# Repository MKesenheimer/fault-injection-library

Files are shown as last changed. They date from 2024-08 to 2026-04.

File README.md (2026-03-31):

# Usage with examples

Findus (aka the fault-injection-library) is a toolchain to perform fault-injection attacks on microcontrollers and other targets.
This library offers an easy entry point to carry out fault-injection attacks against microcontrollers, SoCs and MCUs.
With the provided and easy to use functions and classes, fault-injection projects can be realized quickly with cheap and available hardware.

Findus supports the [ChipWhisperer Pro](https://rtfm.newae.com/Capture/ChipWhisperer-Pro/), the [ChipWhisperer Husky](https://rtfm.newae.com/Capture/ChipWhisperer-Husky/) and the [Pico Glitcher](https://mkesenheimer.github.io/blog/pico-glitcher-v3.html).

More information about the fault-injection-library and the Pico Glitcher can be found on [https://fault-injection-library.readthedocs.io/en/latest/](https://fault-injection-library.readthedocs.io/en/latest/).

## Table of contents

- [Purchasing the Pico Glitcher](#purchasing-the-pico-glitcher)
- [Documentation](#documentation)
- [Installing findus](#installing-findus)
- [Updating the Pico Glitcher firmware](#updating-the-pico-glitcher-firmware)
    - [Step 1: MicroPython firmware](#step-1-microPython-firmware)
    - [Step 2: Install the findus library](#step-2-install-the-findus-library)
    - [Step 3: Update the firmware of your Pico Glitcher](#step-3-upload-the-pico-glitcher-micropython-script)
- [Installing from source](#installing-from-source)
- [Test the functionality of your Pico Glitcher](#test-the-functionality-of-your-pico-glitcher)
- [UART Trigger](#uart-trigger)
- [More Examples](#more-examples)
- [Analyzer](#analyzer)

## Purchasing the Pico Glitcher

Only a Raspberry Pi Pico and a few other components are required to use this software.
However, in order to achieve the best results, a circuit board was developed that was adapted directly for the fault-injection-library.

The board consists of a Raspberry Pi Pico, two level shifters for in- and outputs with any voltage, and glitching transistors that can switch up to 66 amps.
A multiplexing stage to quickly switch between up to four different voltage levels was added in revision 2.

There are several connection options for different voltage sources, from 1.8V, 3.3V to 5V.
The Pico Glitcher can also be supplied with any external voltage via `VCC_EXTERN`.
To power the target board, it is supplied with power via the `VTARGET` connection.
The output of this voltage source can be controlled via software, i.e. the target can be completely disconnected from power by executing the `power_cycle_target()` command.
This allows a cold start of the target to be carried out in the event of error states that cannot be eliminated by a reset.

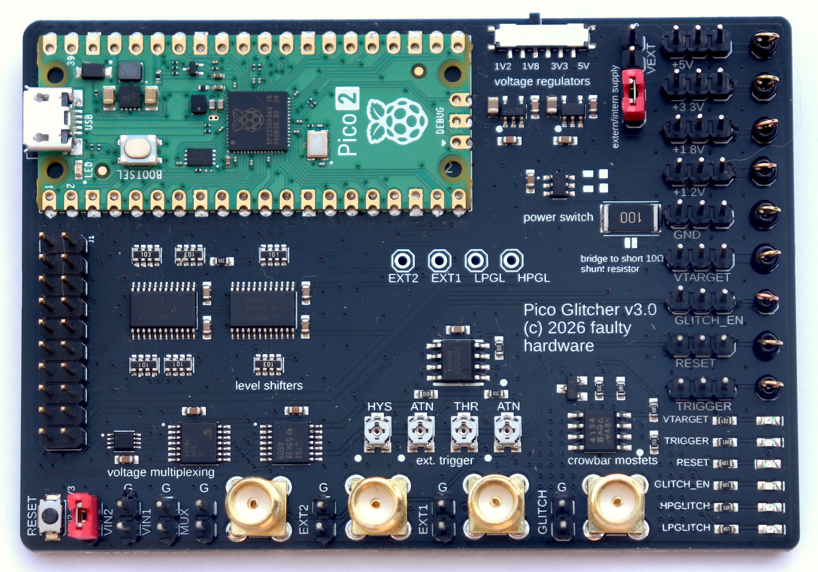
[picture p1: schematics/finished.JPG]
Assembled Pico Glitcher v1


The Pico Glitcher can be purchased from the [faultyhardware](https://faultyhardware.de) online store. If you have questions or special requests, please feel free to contact me.

## Documentation

The documentation of the source code and how to use the library and the hardware can be found on [https://fault-injection-library.readthedocs.io/](https://fault-injection-library.readthedocs.io/).

## Installing findus

If you just want to get started quickly and don't want to bother with the source code of findus, findus can be installed via pip. The findus library can be found on [https://pypi.org/project/findus/](https://pypi.org/project/findus/) and can be installed locally in a Python environment using the following command:

```bash
mkdir my-fi-project && cd my-fi-project
python -m venv .venv
source .venv/bin/activate
pip install findus
```

Install the optional RD6006 python bindings if you have a RK6006 or a RD6006 power supply from Riden:

```bash
pip install rd6006
```

This external power supply can be used optionally to supply the target with power. It is possible to control the RD6006 power supply via the findus library using the power supply's USB interface. Suitable functions for this are implemented in the findus library.
Don't worry if you don't have this power supply. The Pico Glitcher can also supply the target with voltage.

Now you can use findus:

```bash
python
>>> from findus import Database, PicoGlitcher
...
```

The next step is to copy an existing glitching script and to adapt it to your needs.
Start by copying [https://github.com/MKesenheimer/fault-injection-library/blob/master/example/pico-glitcher.py](https://github.com/MKesenheimer/fault-injection-library/blob/master/example/pico-glitcher.py). More example projects are located at [https://github.com/MKesenheimer/fault-injection-library/tree/master/projects](https://github.com/MKesenheimer/fault-injection-library/tree/master/projects).

See [examples](examples.md) for more information how to use findus and the Pico Glitcher.

## Updating the Pico Glitcher firmware

Your Pico Glitcher should come with the latest firmware already installed. If not, follow the following procedure to update the software on the Pico Glitcher.

### Step 1: MicroPython firmware

Download the MicroPython firmware from [https://micropython.org/download/RPI_PICO/](https://micropython.org/download/RPI_PICO/). Unplug the Pico Glitcher from your computer, press and hold the 'BOOTSEL' button on the Raspberry Pi Pico and connect it back to your computer. The Raspberry Pi Pico should come up as a flash-storage device. Copy the MicroPython firmware ('RPI_PICO-xxxxxxxx-vx.xx.x.uf2') to this drive and wait until the Raspberry Pi Pico disconnects automatically.
More information about setting up the Raspberry Pi Pico can be found [here](https://projects.raspberrypi.org/en/projects/getting-started-with-the-pico).

### Step 2: Install the findus library

Skip this step, if you already installed findus previously.

If you want to make sure that the libraries to be installed do not collide with your local Python environment, use a virtual environment.
Set it up by generating a new virtual environment and by activating it:

```bash
python -m venv .venv
source .venv/bin/activate
```

After these steps we have to install findus (aka fault-injection-library).
Make sure to have pip [installed](https://docs.python.org/3/library/ensurepip.html).

```bash
pip install findus
```

### Step 3: Update the firmware of your Pico Glitcher

If everything went well, you should have the `update-fw` script available for execution in your command-line environment.
Connect the Pico Glitcher to your computer and check which serial device comes up:

```bash
ls /dev/tty*
```

Take note of the device path. Next update the Pico Glitcher firmware and the specific configuration for your Pico Glitcher hardware version via the following command:

```bash
update-fw --port /dev/<rpi-tty-port> --version <pico-glitcher-version>
```

Your Pico Glitcher should now be ready to perform fault-injection attacks.

## Installing from source

If you want to get involved in the development or to have access to all the resources of this repository, clone the findus library:

```bash
git clone --depth 1 --recurse-submodules \ 
    https://github.com/MKesenheimer/fault-injection-library.git
```

Install the findus and the optional rd6006 library:

```bash
cd fault-injection-library
pip install .
cd rd6006
pip install .
update-fw --port /dev/<rpi-tty-port> --version <pico-glitcher-version>
```

The next step is to copy an existing glitching script and to adapt it to your needs.
Start by copying `fault-injection-library/example/pico-glitcher.py`. More example projects are located at `fault-injection-library/projects`.

## Test the functionality of your Pico Glitcher

The following  setup can be used to test the Pico Glitcher.

- Connect 'TRIGGER' input with 'RESET'.
- Between 'GLITCH' and 'VTARGET', connect a 10 Ohm resistor (this is the test target in this case).
- Optionally connect channel 1 of an oscilloscope to 'RESET' and channel 2 to 'GLITCH'.

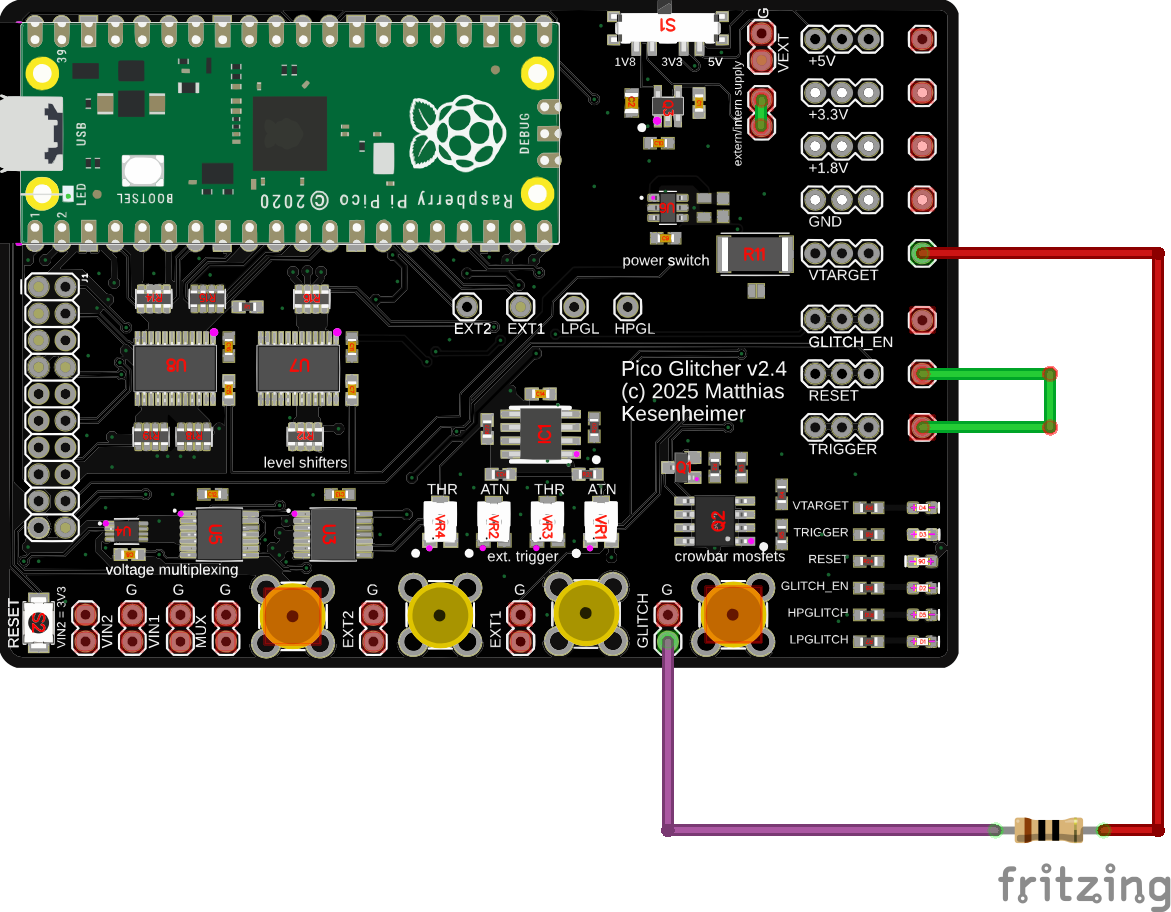
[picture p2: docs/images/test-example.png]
Example setup


Next, run the test script `pico-glitcher.py` located in `fault-injection-library/example`:

```bash
cd example
python pico-glitcher.py --rpico /dev/<rpi-tty-port> --delay 1000 1000 --length 100 100
```

You should now be able to observe the glitches with an oscilloscope on the 10 Ohm resistor.
Measure the expected delay and glitch length with the oscilloscope.

## UART Trigger

- Connect 'TRIGGER' input to 'RX' and 'TX' of a USB-to-UART adapter
- Between 'GLITCH' and 'VTARGET', connect a 10 Ohm resistor (this is the test target in this case).
- Optionally connect channel 1 of an oscilloscope to 'RESET' and channel 2 to 'GLITCH'.

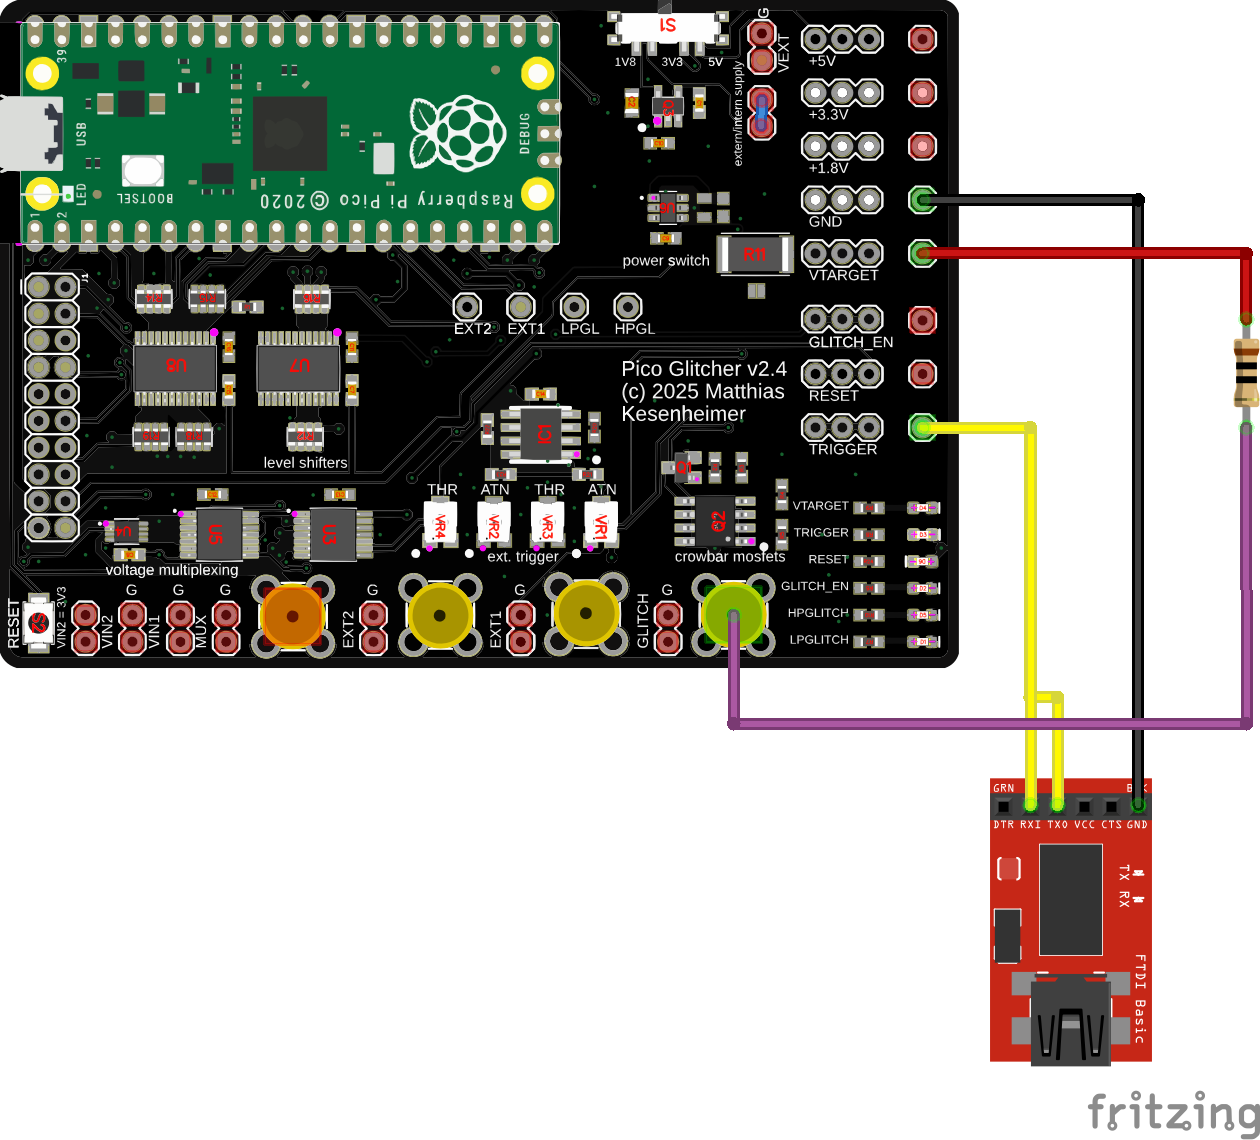
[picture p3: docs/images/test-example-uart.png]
Example setup


Next, run the test script `pico-glitcher-uart.py` located in `fault-injection-library/example`:

```bash
cd example
python pico-glitcher-uart.py --rpico /dev/<rpi-tty-port> --target /dev/<target-tty-port> --delay 1000 1000 --length 100 100
```

You should now be able to observe the glitches with an oscilloscope on the 10 Ohm resistor.
Measure the expected delay and glitch length with the oscilloscope.

## More Examples

More examples can be found on [https://fault-injection-library.readthedocs.io/en/latest/examples/#](https://fault-injection-library.readthedocs.io/en/latest/examples/#) or under `fault-injection-library/projects`.

## Analyzer

During your glitching campaign, run the `analyzer` script in a separate terminal window:

```bash
analyzer --directory databases
```

This spins up a local web application on [http://127.0.0.1:8080](http://127.0.0.1:8080) which can be used to observe the current progress.

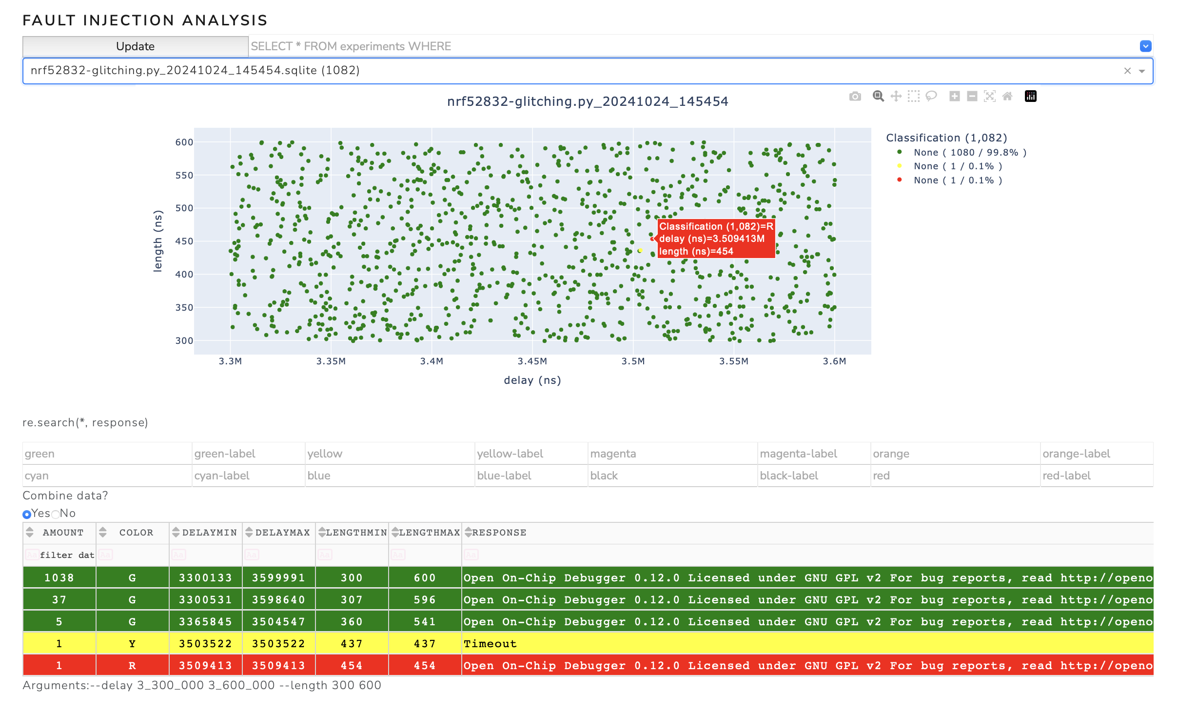
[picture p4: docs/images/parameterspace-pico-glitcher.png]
Parameter space web application


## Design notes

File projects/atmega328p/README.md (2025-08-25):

# Attacking the ATMEGA328P

## Prerequisites

- avrdude
- gcc-avr
- avr-gdb
- binutils-avr
- avr-libc

The installation on macOS is given below.
Installation on other platforms should be similar.

### Commands to install avr-gcc on macOS

```bash
brew tap osx-cross/avr
brew install avr-gcc avr-gdb avr-binutils
```

## Setup

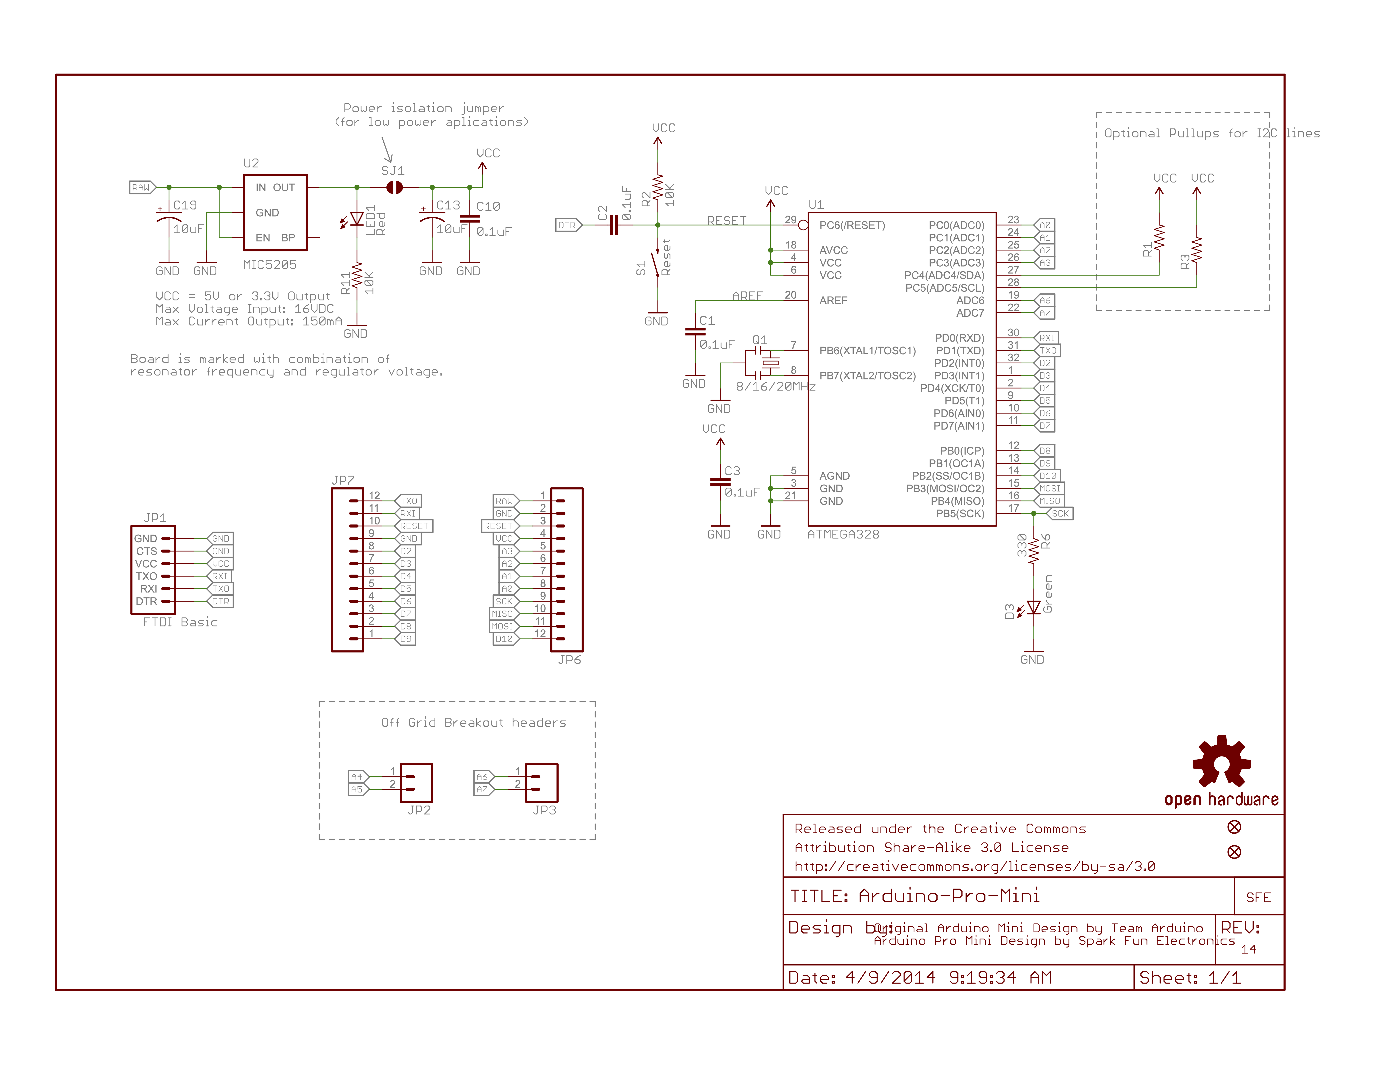
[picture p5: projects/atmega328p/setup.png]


### Wiring

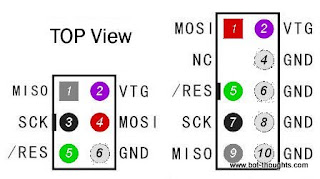
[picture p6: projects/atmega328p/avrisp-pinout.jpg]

Wire JTAGICE3 ISP pins to the ATmega328P:

```
MISO → MISO (PB4)
MOSI → MOSI (PB3)
SCK → SCK (PB5)
RESET → RESET
VCC → VCC
GND → GND
```

## Programming and Reading

The following commands can be used to program the chip, set the lock bits and read from flash:

### Programming

Write program to flash:

```bash
avrdude -F -c jtag3isp -p m328p -U flash:w:blink.hex:i
```

Setting fuses:

* Low fuse (lfuse): 0xFF -> external crystal, no CKDIV8
* High fuse (hfuse): 0xDE -> SPIEN enabled, bootloader reset + 0.5 KB boot section, EESAVE not set
* Extended fuse (efuse): 0x05 -> sets brown-out detection at 2.7 V

```bash
avrdude -F -c jtag3isp -p m328p \
  -U lfuse:w:0xFF:m \
  -U hfuse:w:0xDE:m \
  -U efuse:w:0x05:m # or 0xFD on newer avrdude
```

### Enable readout protection

* 0xFF = unlocked (default)
* 0x00 = full lock (chip only erasable, not readable)
* 0xFC = no programming, no verify/read (strongest: code protected)

```bash
avrdude -F -c jtag3isp -p m328p -U lock:w:0x00:m
```

### Disable readout protection and erase flash

```bash
avrdude -F -c jtag3isp -p m328p -e
```

### Reading

Dump flash:
```bash
avrdude -F -c jtag3isp -p m328p -U flash:r:dump.hex:i
```

Read fuses:
```bash
avrdude -F -c jtag3isp -p m328p -U lfuse:r:lfuse.hex:h -U hfuse:r:hfuse.hex:h -U efuse:r:efuse.hex:h
```

Read lock bits:
```bash
avrdude -F -c jtag3isp -p m328p -U lock:r:lock.hex:h
```

Read lock bits to stdout:
```bash
avrdude -F -c jtag3isp -p m328p -U lock:r:-:h
```

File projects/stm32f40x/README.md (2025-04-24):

# Notes

Short notes for the attacks on the STM32F40x microcontroller series.

## Short Summary

- This script attacks the read memory command while the microcontroller is in bootloader mode 
- This attack is similar to the attacks on the [STM8](https://github.com/MKesenheimer/fault-injection-library/tree/master/projects/stm8s) microcontroller
- A glitch is sent immediately after the read memory command (0x11ee)
- If the glitch is successful, the microcontroller responds with an ACK
- To get the memory contents of the flash, the script sends the following commands to set the address to read from and the number of bytes to read from that address
- To get the full flash back, the glitch is executed several times and the address to read from is increased accordingly.

Note that this script is for research only and is not intended to run on a real target. For example, if the script detects an error (such as a PCROP bit set), the microcontroller will be reprogrammed and all content will be lost. Make sure you understand what this script does and modify it to suit your needs.

Look into the [image folder](images) for more details.

A detailed write-up can be found [here](https://mkesenheimer.github.io/blog/glitching-the-stm32f4.html).

## Schematics

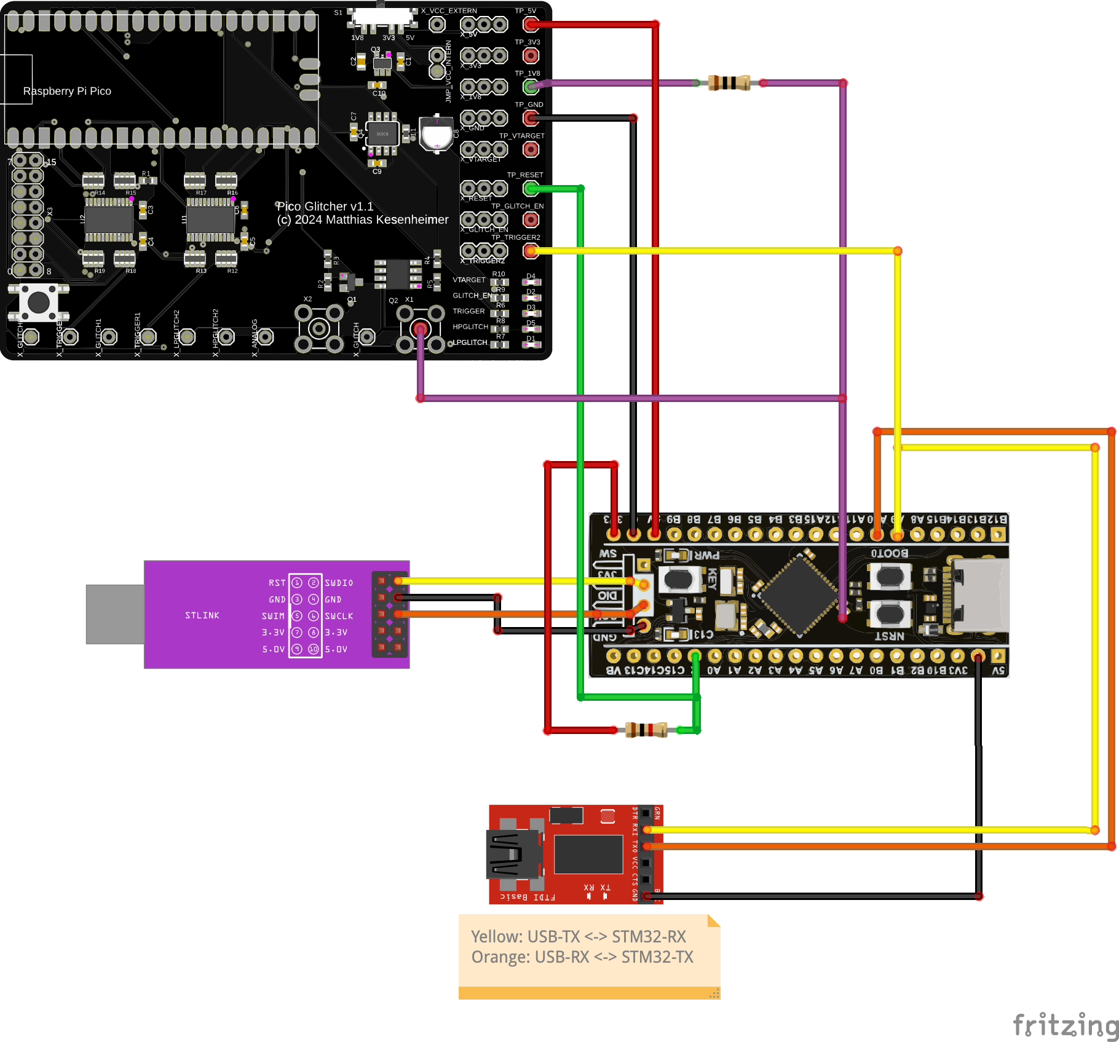
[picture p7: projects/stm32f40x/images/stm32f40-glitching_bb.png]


## Black Pill setup

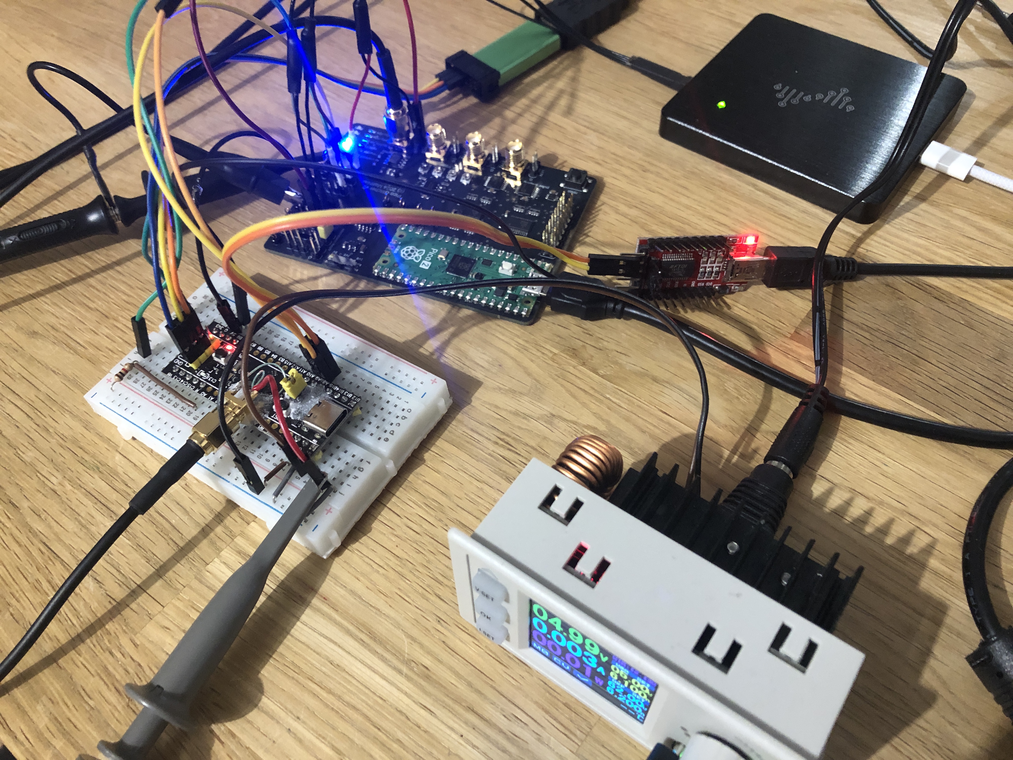
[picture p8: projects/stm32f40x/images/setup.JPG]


## Parameterspace

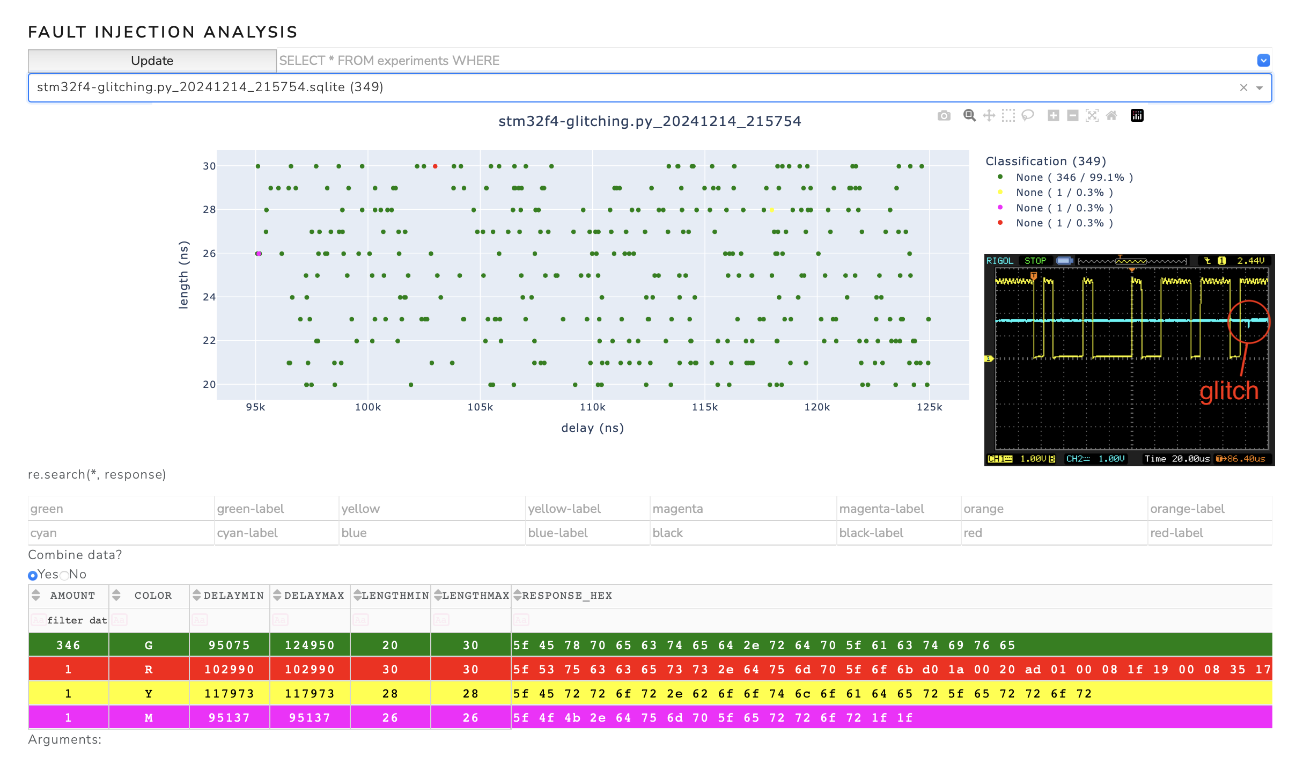
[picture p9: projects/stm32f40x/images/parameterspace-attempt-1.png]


## Successful dump

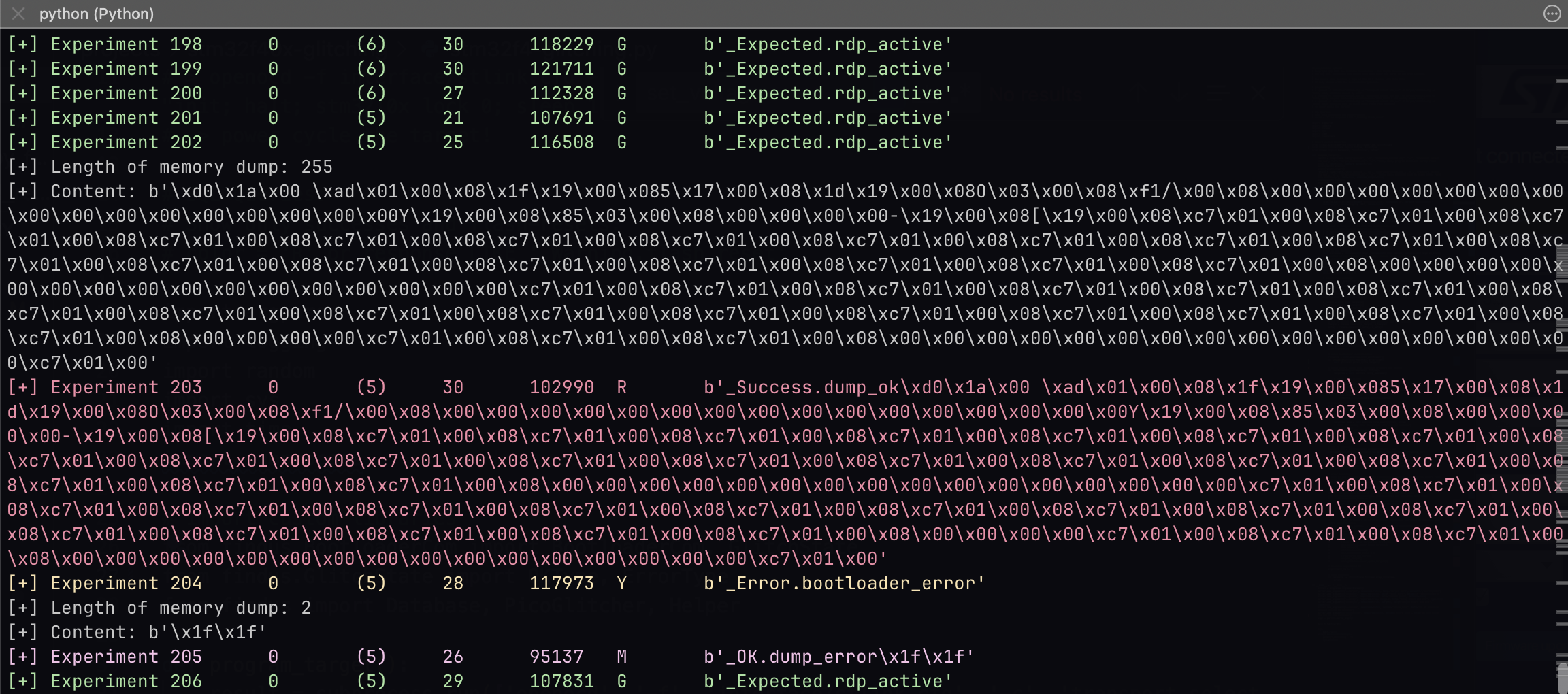
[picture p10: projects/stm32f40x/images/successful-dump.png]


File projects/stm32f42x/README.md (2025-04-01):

# Notes

## Short Summary
- Capacitors V_CAP_1 and V_CAP_2 have to be removed. Glitch is inserted on V_CAP line.
- Successful glitches and memory dumps in the following parameter range (ChipWhisperer Pro):
```bash
python pro-glitcher.py --target /dev/<target-tty-port> --delay 90_500 91_500 --length 230 240
```
- Flash gets erased occasionally while glitching -> target has to be reprogrammed.
- PCROP register gets set occasionally while glitching -> bootloader memory responses are masked with zeros.
- PCROP register must be unset if it is set during a glitching attempt.
- Bootloader code (address 0x1fff0000) can be dumped and reverse engineered.
- [AN2606 Application note STM32 microcontroller system memory boot mode](https://www.st.com/resource/en/application_note/an2606-stm32-microcontroller-system-memory-boot-mode-stmicroelectronics.pdf)

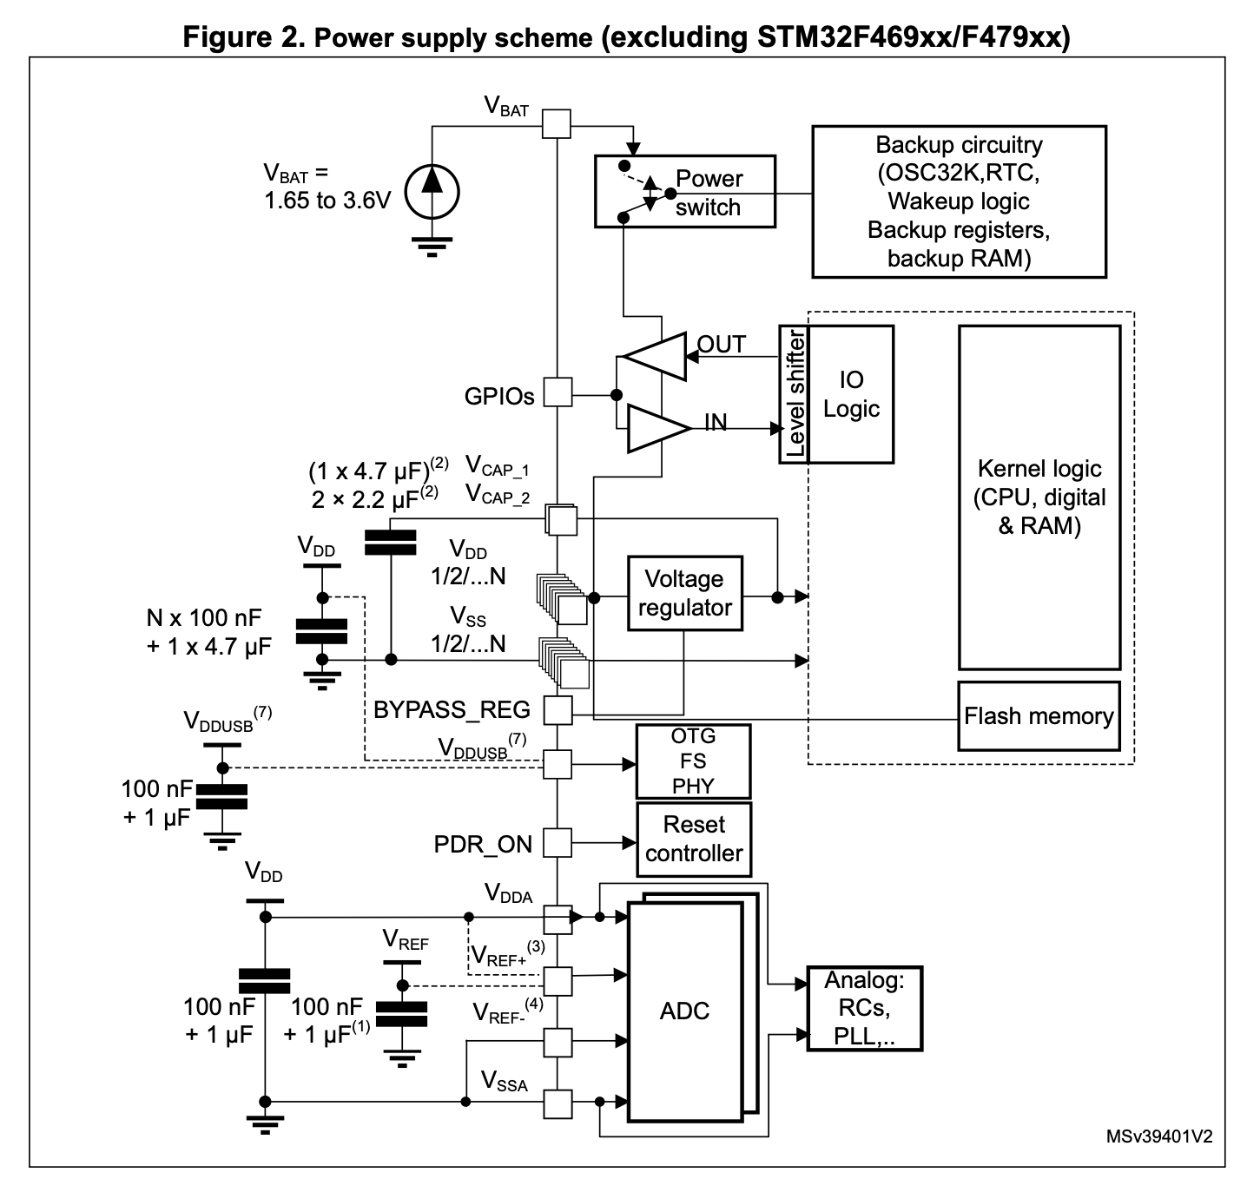
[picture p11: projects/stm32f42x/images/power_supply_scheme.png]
Glitch insertion point

[AN4488 Application note](https://www.st.com/resource/en/application_note/an4488-getting-started-with-stm32f4xxxx-mcu-hardware-development-stmicroelectronics.pdf)

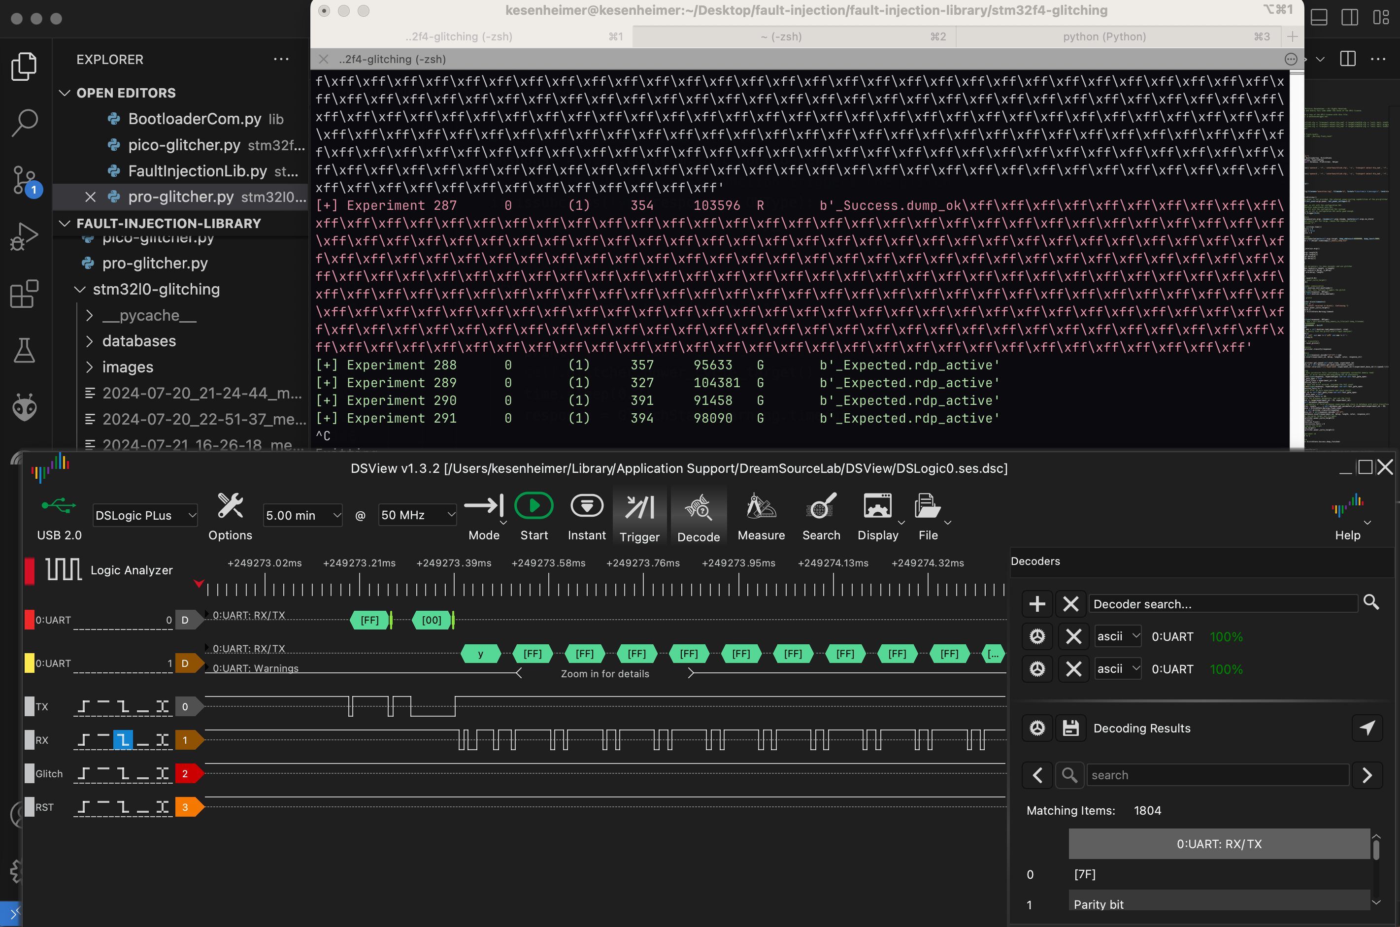
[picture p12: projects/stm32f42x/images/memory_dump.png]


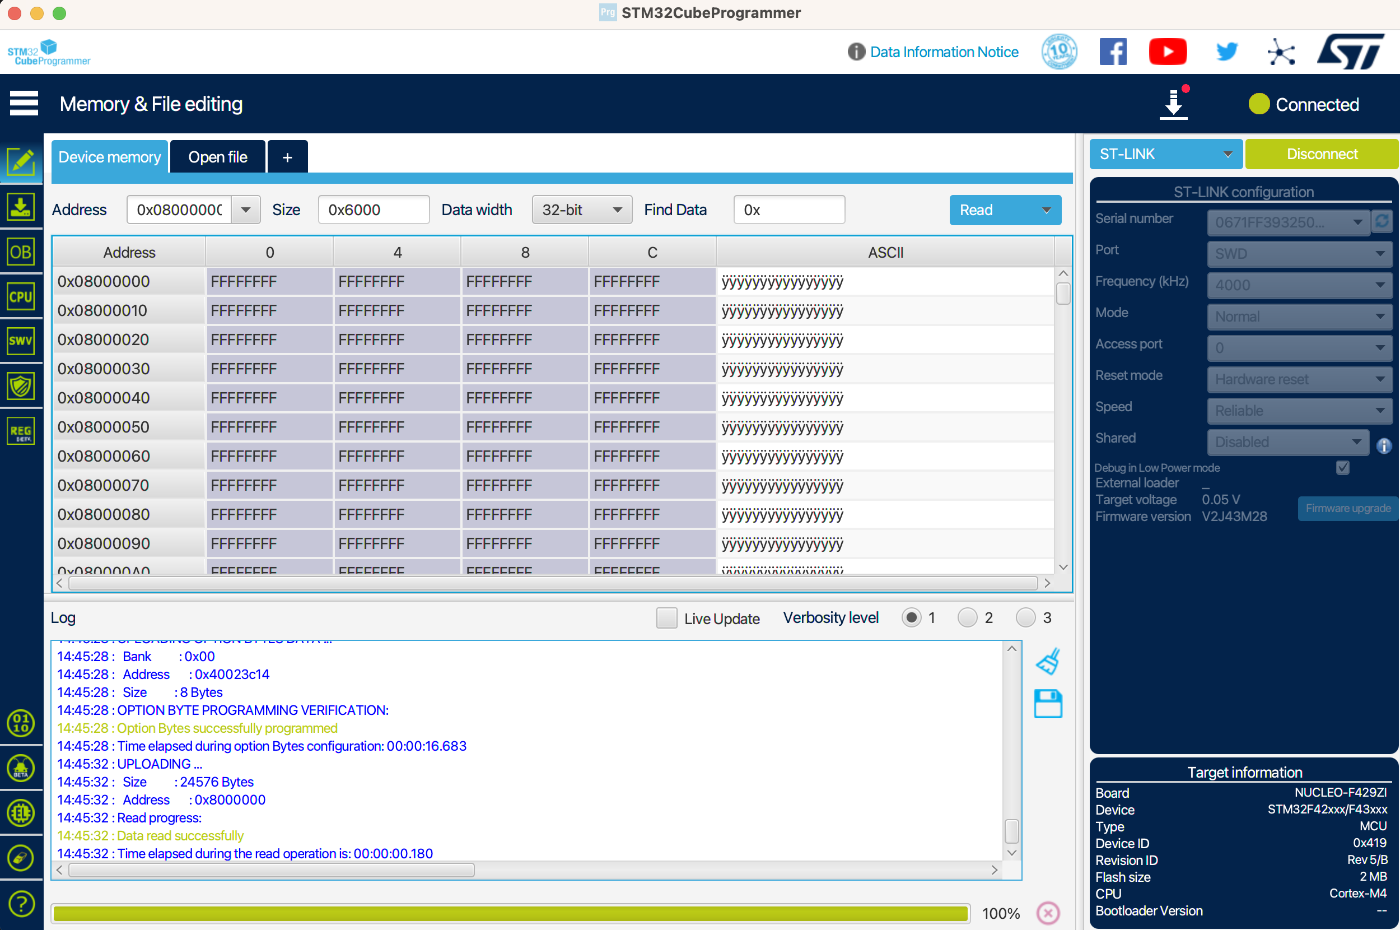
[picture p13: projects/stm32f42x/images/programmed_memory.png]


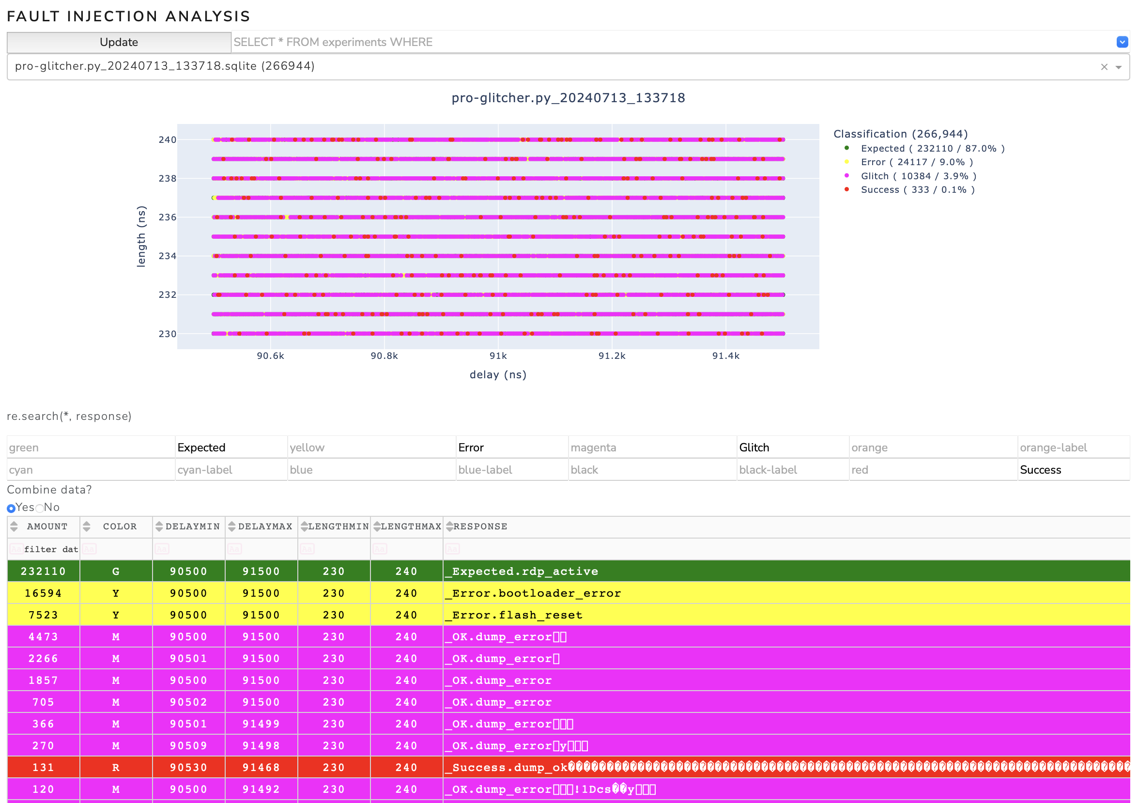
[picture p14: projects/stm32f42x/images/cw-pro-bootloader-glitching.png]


## TODO
- [ ] Screenshot of set PCROP register
- [ ] STM32F4 glitching with new development board (STM black pill STM32F401CCU6), see [STM32F401CCU6 glitching](https://jerinsunny.github.io/stm32_vglitch/)
- [ ] Screenshot of oscilloscope
- [ ] Dump and reverse engineering of Bootloader
- [ ] Document results

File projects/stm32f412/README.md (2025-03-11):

# Notes

## Short Summary

- Capacitors V_CAP_1 and V_CAP_2 have to be removed. Glitch is inserted on V_CAP line.

- Successful glitches and memory dumps in the following parameter range (PicoGlitcher):
  
  ```bash
  python pico-glitcher.py --rpico /dev/<PicoGlitcher-tty-port> --target /dev/<target-tty-port> --delay 103_000 105_000 --length 225 235
  ```

- Flash gets erased occasionally while glitching -> target has to be reprogrammed.

- Bootloader code (address 0x1fff0000) can be dumped and reverse engineered.

- [AN2606 Application note STM32 microcontroller system memory boot mode](https://www.st.com/resource/en/application_note/an2606-stm32-microcontroller-system-memory-boot-mode-stmicroelectronics.pdf)

Glitch insertion point
[AN4488 Application note](https://www.st.com/resource/en/application_note/an4488-getting-started-with-stm32f4xxxx-mcu-hardware-development-stmicroelectronics.pdf)

## Images

This is what it looks like if observering the Vcore (yellow, where we glitch) and the serial transmission (green) from the device. The bit pattern shown is that of 0x1f - NACK - we're not allowed to continue our Read Memory request due to RDP.

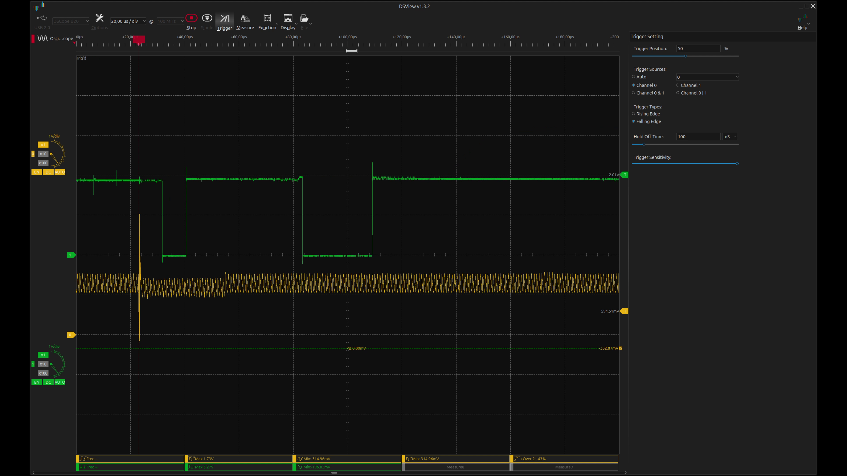
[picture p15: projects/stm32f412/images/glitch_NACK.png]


When the glitch is successful, we can see that the bit pattern now has changed to that of 0x79 - ACK - and we can continue sending the wanted memory address and length.

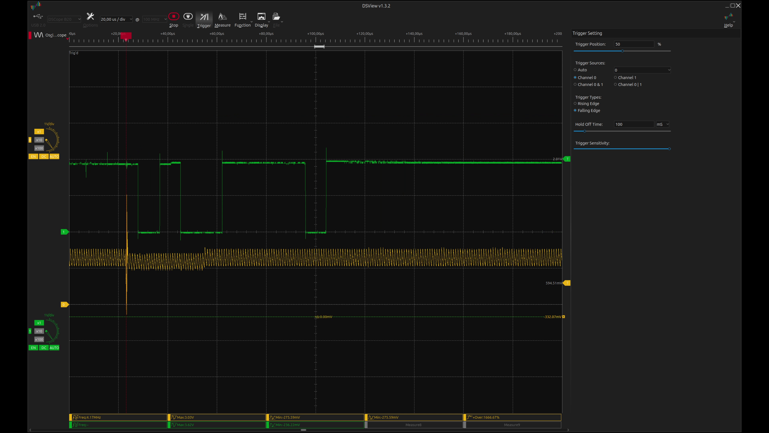
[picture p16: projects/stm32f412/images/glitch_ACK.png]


Closeups of the actual Vcore glitch. The amount of "ringing" (overshoot) after the glitch seems to correlate with what actions the glitch caused the device to take afterwards.

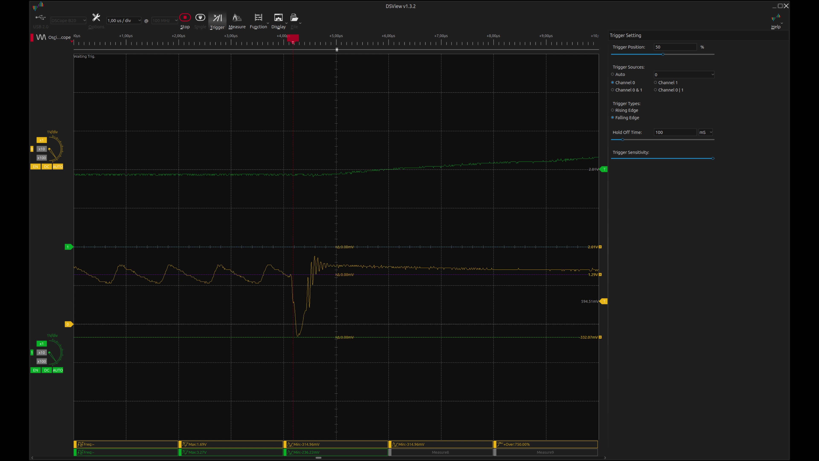
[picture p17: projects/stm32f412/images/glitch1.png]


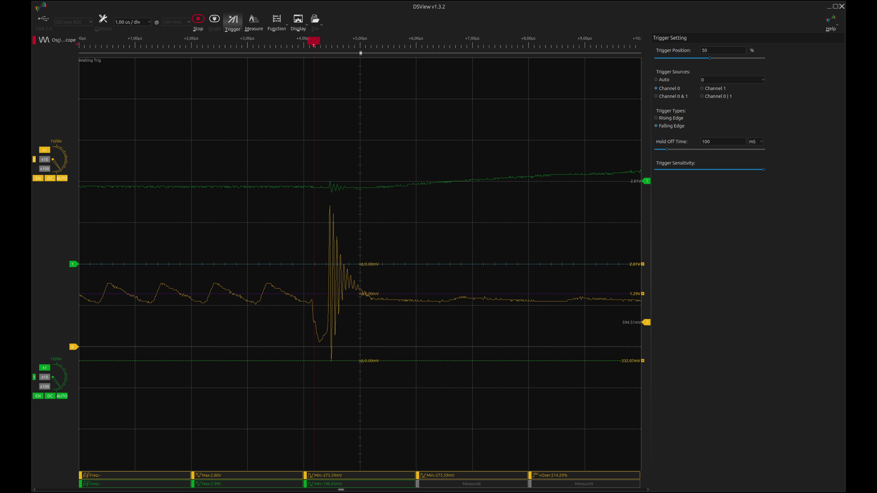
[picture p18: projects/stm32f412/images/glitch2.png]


## Example statistics

Reading out the bootloader (~24kB in size, v3.1) takes a few hours. As can be seen from the statistics, during that time we had 69 occasions (cyan) where the internal flash of the device was _possibly_ cleared. 96 successful glitched Read Memory requests (red) were needed, from a total of  ~15000 tries in total. Magenta indicates a successful glitch but where the device was no longer responding according to what Read Memory should (wrong execution path likely reached) and the various green rows indicate responses that were either expected (NACK) or anything else besides ACK.

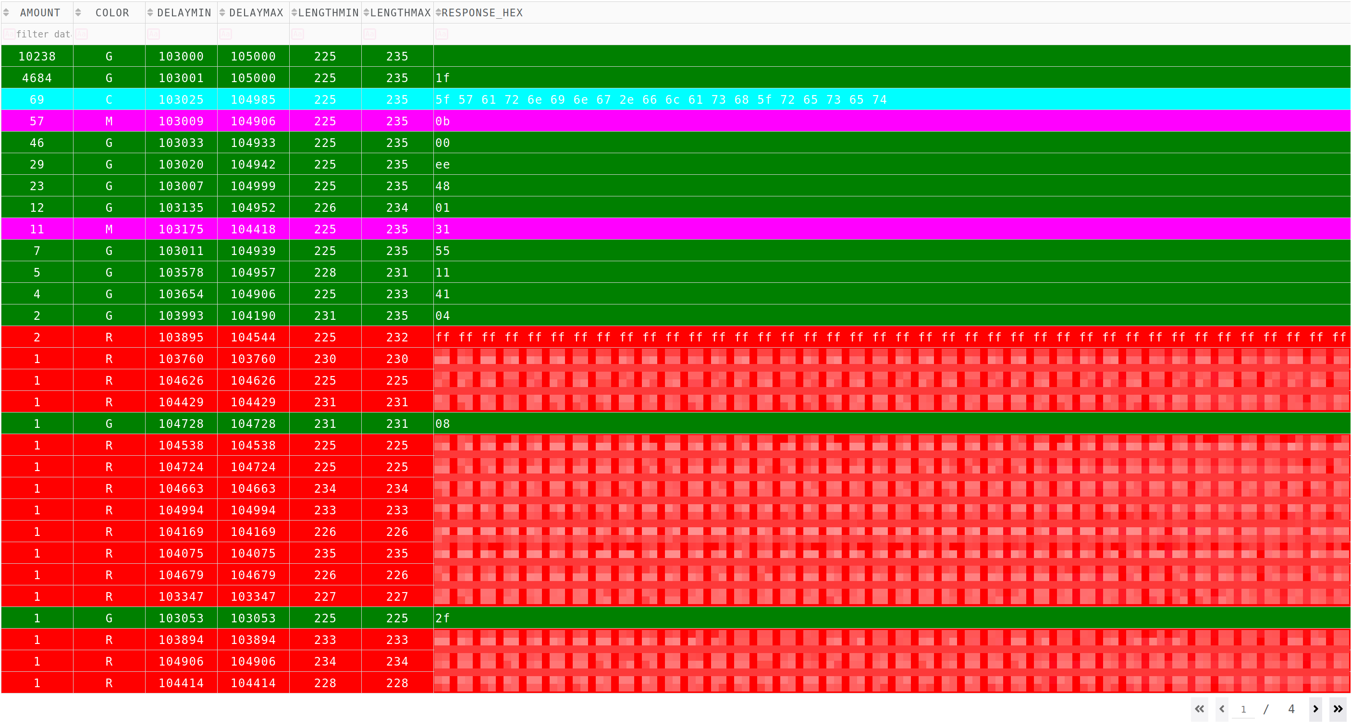
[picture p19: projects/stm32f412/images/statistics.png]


## Why this target is difficult to glitch

The current method for glitching STM32F4* relies on sending a Read Memory request to the STM bootloader via USART, picking up the sent byte on the serial line and then waiting a fix amount of nanoseconds before activating the glitch. However, due to the interaction between the serial clock and the CPU clock this method is wildly inexact. Looking at the red rows in the picture above we can clearly see that the delay at which we got successful glitches varies over 2000 ns. This also means that we're glitching all sorts of code paths during these tries, and some of those cause unintended and serious side effects.

The STM bootloader checks the received command byte with one long sequence of compares and jumps. Glitching during the time this code is run can cause execution to continue in another bootloader command method. We're also not currently able to "hook" onto some other indicator of where the bootloader is currently in it's execution, which would be needed for a much more exact exploit without the risk of clearing the internal flash memory.

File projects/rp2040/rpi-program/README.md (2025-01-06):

# Raspberry Pico Test Program

Set up raspberry pi pico projects according the official [documentation](https://projects.raspberrypi.org/en/projects/getting-started-with-the-pico).

Build and flash the project:
```
mkdir build && cd build
cmake -DCMAKE_BUILD_TYPE=Debug ..
make -j4
picotool load rpi-test.bin -f && picotool reboot
```

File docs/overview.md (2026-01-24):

# Overview

This page will give a brief overview of what findus (aka the fault-injection-library) and the PicoGlitcher is, what it can be used for and where to go from here.

## Fault-Injection

Fault injection is a group of attacks in which external influences are used to cause faults in a system and thereby influence the behavior of the system. In the simplest case, this can be an input mask on a web application that is not correctly secured against incorrect input. However, fault injection attacks usually also involve some kind of side-channel attack. This means that the fault is not caused by the usual channels (e.g. the input screen on the web application), but by a second channel. In the case of microcontrollers or embedded systems in general, the power supply or the clock generators on the board are used as a side channel to provoke error states.

## Voltage Glitching

In voltage glitching, the voltage supply to the chip is reduced for a very short time (in the order of nanoseconds to a few microseconds) to such an extent that processes in the chip no longer function correctly. Energy is required for certain operations in the chip. If this energy is not available, the operation is not carried out or is carried out incorrectly. Writing or erasing a memory cell, for example, cannot take place if there is not enough energy (i.e. in the simplest case, the supply voltage) available.

If the power supply is reduced at the time when a CPU register is written, no data or an incorrect value is written to the register. This can be particularly useful as an attack vector if the microcontroller has read-out protection. With read-out protection, the flash content is protected by checking if certain register values are set. These register values are not usually located in the firmware on the flash, but in a separate memory area, so-called fuses. If the microcontroller wants to check whether the read-out protection is set, these fuses must be read out and copied to an internal CPU register. If the power supply is lowered during this copying process so that the internal CPU register is written to incorrectly, the read-out protection can potentially be bypassed.

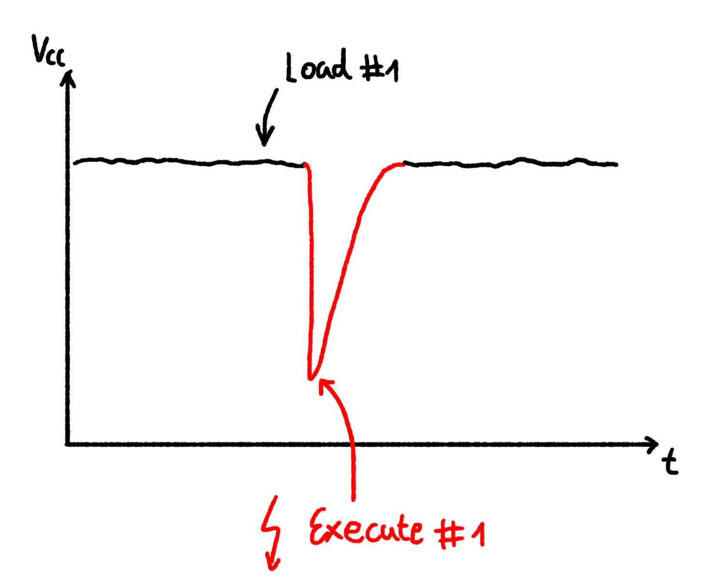
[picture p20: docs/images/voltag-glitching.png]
A reduction in the power supply causes an error during execution


The parameters for such attacks are the time delay from a trigger condition to the glitch itself ("delay") and the duration of the glitch ("length"). The trigger condition can be anything, for example switching on the power supply, removing the reset signal or certain states in the data transmission.

## What is findus?

Findus (aka the fault-injection-library) is a toolchain to perform fault-injection attacks on microcontrollers and other targets.
This library offers an easy entry point to carry out fault-injection attacks against microcontrollers, SoCs and CPUs.
With the provided and easy to use functions and classes, fault-injection projects can be realized quickly with cheap and available hardware.

Findus supports the [ChipWhisperer Pro](https://rtfm.newae.com/Capture/ChipWhisperer-Pro/), the [ChipWhisperer Husky](https://rtfm.newae.com/Capture/ChipWhisperer-Husky/) and the PicoGlitcher.
More information about the ChipWhisperer Pro and the ChipWhisperer Husky can be found on [https://chipwhisperer.readthedocs.io/en/latest/index.html](https://chipwhisperer.readthedocs.io/en/latest/index.html).

## What is the Pico Glitcher v1?

The Pico Glitcher is a device similar to the [ChipWhisperer Pro](https://rtfm.newae.com/Capture/ChipWhisperer-Pro/) and the [ChipWhisperer Husky](https://rtfm.newae.com/Capture/ChipWhisperer-Husky/).
The Pico Glitcher is capable of generating voltage glitches very precisely. It also has several options for trigger generation, i.e. the Pico Glitcher can trigger on rising or falling edges, or even on patterns in a data transmission (for example on a specific UART word).

Pico Glitcher v1.1 components

The hardware is based on the [Raspberry Pi Pico](https://www.raspberrypi.com/products/raspberry-pi-pico/), a low-power and a high-power MOSFET for glitch generation and other components for power supply. Level shifters ensure that the Pico Glitcher can handle a wide range of reference voltages, i.e. the Pico Glitcher is not limited to a fixed logic level.

Three tapping points are available for reference voltages: 1.8V, 3.3V and 5V. These can be used to supply the target or to provide reference voltages for external circuits. The voltage on the `VTARGET` pin header can be switched on and off via the findus library, which is useful for performing a hard reset on the target (power-cycle). The `VTARGET` pinouts can also be supplied by an external power supply unit. To do this, the `JMP_VCC_INTERN` jumper must be removed. The external power supply is then applied to the `VCC_EXTERN` pin.

An additional pin header is connected to the remaining GPIO pins of the Raspberry Pi Pico via level shifters. These can be programmed for further inputs and outputs as required. For example, further triggers can be created on these pin headers or protocol translators can be implemented.

Glitches are generated by two crowbar transistors. A 'IRLML2502' MOSFET is used for generating low-power glitches, the second 'SI4134DY' MOSFET can switch up to 50 Amperes. Depending on the application, one or the other transistor may be suitable. The transistors can be selected via the findus library. For most applications, the low-power MOSFET is sufficient and even generates sharper glitches (with steeper edges) than the high-power MOSFET. However, if larger currents need to be dissipated, for example if large capacitors are installed on the target, the high-power MOSFET is the better choice.

Status LEDs also indicate the current status of the board: Whether the target voltage is being generated, whether the glitcher is armed, or whether a trigger signal is present, etc.

## Pico Glitcher v2

Compared to hardware revision 1, several new features have been added in revision 2. However, the basic usage is the same and the scripts for version 1 will also (likely) work for version 2 [1].

Pico Glitcher v2.1 components

The hardware is similar to the Pico Glitcher v1 (based on the Raspberry Pi Pico, high-power MOSFETs for glitch generation, level shifters to ensure compatibility over a wide voltage range etc.).
The pin assignment of the GPIO header has changed due to PCB routing optimization.
These pins still can be programmed for further inputs and outputs as required. For example, further triggers can be created on these pin headers or protocol translators can be implemented.
Input pins `GPIO16` - `GPIO19` are connected to the Raspberry Pi Pico without a level shifter and can be used bi-directionally.

A new input stage (`EXT1` and `EXT2`) has been added to the board which can be used to filter out noise and other disturbances, see section [Schmitt Trigger EXT inputs](schmitt.md).
The multiplexing output can be used to quickly switch between different voltage levels and to supply the target board with power. Up to four different voltage levels can be configured and switched between (see section [Multiplexing](multiplexing.md)).

## Pico Glitcher v3

More improvements have been made to the Pico Glitcher version 3.

Pico Glitcher v3.0 components

The summary of changes are:

- The Pico Glitcher version 3 is based on the Raspberry Pi Pico 2: higher clock speed, better accuracy in glitching attacks, more power!
- Improved power supply: You can now choose from four different voltages to interface with various microcontrollers: 1.2V, 1.8V, 3.3V, and 5V.
- Improved Schmitt trigger inputs provide even better and more reliable triggering.

Everything else is unchanged: Two high-power MOSFETs for crowbar glitch generation, and two level shifters to ensure compatibility over a wide voltage range. An Schmitt Trigger input stage (EXT1 and EXT2) can be used to filter out noise and other disturbances via adjustable Schmitt Triggers. The multiplexing output can be used to quickly switch between up to four different voltage levels and to supply the target board with power.

Compared to the original Raspberry Pi Pico, the Pico 2 is simply a better platform for voltage glitching. The most obvious advantage is performance. The Pico 2 runs at a significantly higher clock speed, which directly improves timing resolution. In glitching attacks, timing is everything. Finer timing granularity means you can place glitches more precisely relative to the target's execution, which increases both reliability and repeatability.

The improved power supply makes the Pico Glitcher far more flexible when attacking real-world targets. Modern microcontrollers operate at a wide range of core and I/O voltages, and voltage glitching is most effective when the glitch amplitude closely matches the target's supply rail. By supporting 1.2 V and 1.8 V directly, the Pico Glitcher can interface cleanly with low-power and high-performance MCUs without level shifters or external regulators.

The HYS potentiometer of the `EXT2` input (see [Schmitt Trigger EXT inputs](schmitt.md)) is used to adjust the hysteresis of the Schmitt trigger input EXT2. It controls the difference between the upper and lower switching thresholds. By changing this difference, it directly determines how much the input signal must move before the output changes state.

Continue reading [getting started](getting_started.md) to learn more about how to set up your Pico Glitcher.

[1]: If not, please submit an issue at [https://github.com/MKesenheimer/fault-injection-library/issues](https://github.com/MKesenheimer/fault-injection-library/issues).

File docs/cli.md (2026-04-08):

# Command-Line Tools

The following command-line tools are available after the installation of findus (`pip install findus`).

## update-fw

Tool to update the firmware of the Pico Glitcher.
Usage:

```bash
$ update-fw --help
usage: update-fw [-h] --port PORT [--version VERSION]

Update the firmware of the Pico Glitcher.

options:
  -h, --help         show this help message and exit
  --port PORT        /dev/tty* of the Raspberry Pi Pico
  --version VERSION  Pico Glitcher (one of v1, v2.1, v2.2, v2.3, v2.4, v2.5, v3.0)
```

Examples:

- Update hardware version 3.0 to the latest firmware version:
```bash
update-fw --version v3.0 --port /dev/tty.usbmodem2101
```

In case this script fails, use the old update mechanism with `upload-ampy`. See below.

## upload

Tool to upload MicroPython scripts to the Pico Glitcher. This tool can be used, for example, to update the firmware of the Pico Glitcher or to update single files.
Usage:

```bash
$ upload --help
usage: upload [-h] --port PORT [--delete-all] [--delete DELETE] [--file FILE] [--files FILES [FILES ...]]

Upload a micro python script to the Raspberry Pi Pico.

options:
  -h, --help            show this help message and exit
  --port PORT           /dev/tty* of the Raspberry Pi Pico
  --delete-all          Delete all files from the Raspberry Pi Pico
  --delete DELETE       Delete the file from the Raspberry Pi Pico
  --file FILE           File to upload to the Raspberry Pi Pico
  --files FILES [FILES ...]
                        Files to upload to the Raspberry Pi Pico
```

Examples:

- Upload or update an existing MicroPython script:
```bash
upload --port /dev/<rpi-tty-port> --file <file.py>
```

- Upload multiple files:
```bash
upload --port /dev/<rpi-tty-port> --files <file1.py> <file2.py>
```

- Delete all content:
```bash
upload --port /dev/<rpi-tty-port> --delete-all
```

## upload-ampy (slow but reliable)

In case updating the firmware with the command `update-fw` or `upload` fails, there is a fall-back solution that relies on `ampy`. This script is slower, however, it is reliable.

```bash
upload-ampy --help
usage: upload-ampy [-h] --port PORT [--delete-all] [--delete DELETE] [--file FILE] [--files FILES [FILES ...]]

Upload a micro python script to the Raspberry Pi Pico.

options:
  -h, --help            show this help message and exit
  --port PORT           /dev/tty* of the Raspberry Pi Pico
  --delete-all          Delete all files from the Raspberry Pi Pico
  --delete DELETE       Delete the file from the Raspberry Pi Pico
  --file FILE           File to upload to the Raspberry Pi Pico
  --files FILES [FILES ...]
                        Files to upload to the Raspberry Pi Pico
```

The usage is the same as for `upload`.

Example to update the Pico Glitcher to the latest firmware:

```bash
cd fault-injection-library/findus/firmware
upload-ampy --files AD910X.py FastADC.py Globals.py PicoGlitcher.py PulseGenerator.py Spline.py Statemachines.py <config-version>/config.json --port /dev/<rpi-tty-port>
```

where `<rpi-tty-port>` is the tty port the Pico Glitcher is available at, and `<config-version>` is the config path for your specific Pico Glitcher hardware revision. For example `config_v1` for version 1, `config_v2.1-2` for versions 2.1 and 2.2, `config_v2.3-4` for versions v2.3 and v2.4, and `config_v3.0` for version 3.0, and so on.

## analyzer

Script that spins up a web application during a glitching campaign to observe the current progress. Must be executed in the directory where the glitching script is executed (this directory contains the `database` folder).

```bash
$ analyzer --help
usage: analyzer [-h] --directory DIRECTORY [--port PORT] [--ip IP] [-x X] [-y Y]
                [--aspect-ratio ASPECT_RATIO] [--auto-update [AUTO_UPDATE]] [--heatmap]
                [--x-number-of-bins X_NUMBER_OF_BINS] [--y-number-of-bins Y_NUMBER_OF_BINS]
                [--color-scale COLOR_SCALE]

analyzer.py v0.1 - Fault Injection Analyzer

options:
  -h, --help            show this help message and exit
  --directory DIRECTORY
                        Database directory
  --port PORT           Server port
  --ip IP               Server address
  -x X                  parameter to plot on the x-axis
  -y Y                  parameter to plot on the y-axis
  --aspect-ratio ASPECT_RATIO
                        aspect ratio of the plot relative to x-axis
  --auto-update [AUTO_UPDATE]
                        Whether to update the plot automatically. Optionally pass the update interval
                        in seconds.
  --heatmap             Generate a heat map
  --x-number-of-bins, --x-bins X_NUMBER_OF_BINS
                        Number of bins of the x-axis for the heat map
  --y-number-of-bins, --y-bins Y_NUMBER_OF_BINS
                        Number of bins of the y-axis for the heat map
  --color-scale COLOR_SCALE
                        Color scale to use for the heat map (findus, Blues, Reds, Greys, PuRd,
                        YlOrRd).
```

Example:
```bash
cd projects/airtag-glitching
analyzer --directory databases -x delay -y length
```

Visit `http://127.0.0.1:8080` in your web browser to access the analyzer web application.
Parameter space web application

Alternatively, you can spin up the web application on all network interfaces to access it from other hosts:

```bash
cd projects/airtag-glitching
analyzer --directory databases --ip 0.0.0.0
```

If you want to generate a heat map that shows the number of successful events in a region, use:

```bash
analyzer --directory databases --auto-update 60 --heatmap --x-bins 15 --y-bins 15 --color-scale findus
```

## database-tool

This is a small tool to operate on existing databases. For example, experiments can be removed on certain conditions, or two databases can be merged.

```bash
database-tool --help
usage: database-tool [-h] [--dbname DBNAME] [--cleanup CLEANUP] [--remove REMOVE] [--merge databas1 database2 output]

options:
  -h, --help            show this help message and exit
  --dbname DBNAME       Name of the database
  --cleanup CLEANUP     Remove experiments with a certain color from the database.
  --remove REMOVE       Remove experiments by a certain condition. For example, `id = 1000`, `id > 1000`, `color = "C"`
                        or `delay < 6000`.
  --merge databas1 database2 output
                        Merge two databases
```

Example how to remove experiments by a given condition:
```bash
database-tool --dbname database1.sqlite --remove 'color = "G"'
database-tool --dbname database1.sqlite --remove 'id > 1000'
```

Example how to merge two databases:
```bash
database-tool --merge database1.sqlite database2.sqlite out.sqlite
```

## stm32-bootloader

Communicate with a STM32 microcontroller in bootloader mode and read the flash memory (only if RDP-0 is active). If read-out protection is active, the corresponding target responses are printed.

Example:
```bash
stm32-bootloader /dev/<target-tty-port>
```

## stm8-programmer

Communicate with a STM8 microcontroller in bootloader mode and read the flash memory (only if RDP-0 is active). If read-out protection is active, the corresponding target responses are printed.

Example:
```bash
usage: stm8-programmer [-h] --port PORT [--baud BAUD] [--write WRITE] [--read READ] [--number-of-bytes NUMBER_OF_BYTES] [--write-option WRITE_OPTION]
                      [--read-option [READ_OPTION]]
```

## power-on

Enable `VTARGET` with this simple script. Can be necessary, for example, to supply the target with power for debugging purposes. Alternatively, the target device can also powered via the multiplexing stage, pulse-shaping stage or external power supply. If the `--rpico` argument is omitted (no Pico Glitcher connected), it will try to connect to the ChipWhisperer Pro instead.

```bash
power-on --help
usage: power-on [-h] [--rpico RPICO] [--power POWER] [--multiplexing] [--pulse-shaping] [--voltage VOLTAGE]

Power the target via different output stages of the Pico Glitcher (VTARGET, multiplexing stage, pulse-shaping stage or external power supply).

options:
  -h, --help         show this help message and exit
  --rpico RPICO      rpico port
  --power POWER      rk6006 port
  --multiplexing     Use the multiplexing stage to power the target (requires PicoGlitcher v2).
  --pulse-shaping    Use the pulse-shaping stage to power the target (requires PicoGlitcher v2). Be sure to calibrate the pulse-shaping stage's voltage output.
  --voltage VOLTAGE  The voltage to set. Note that the voltage output of the pulse-shaping stage can not be controlled with this parameter. The voltage output of the pulse-
                     shaping stage must be set manually with the potentiometer.
```

Example:
```bash
power-on --rpico /dev/<rpi-tty-port>
```

## stm32-power-cycle-and-read

Test the power supply capabilities of your setup by executing this script. The target's response is read over UART after power-cycle.
If the `--rpico` argument is omitted (no Pico Glitcher connected), it will try to connect to the ChipWhisperer Pro instead.

```bash
stm32-power-cycle-and-read --help
usage: stm32-power-cycle-and-read [-h] --target TARGET [--rpico RPICO] [--dump] [--power POWER] [--multiplexing] [--pulse-shaping] [--voltage VOLTAGE]

Power the target via different output stages of the Pico Glitcher (VTARGET, multiplexing stage, pulse-shaping stage or external power supply) and dump the flash content of a
STM32 in bootloader mode via a UART connection.

options:
  -h, --help         show this help message and exit
  --target TARGET    target port
  --rpico RPICO      rpico port
  --dump
  --power POWER      rk6006 port
  --multiplexing     Use the multiplexing stage to power the target (requires PicoGlitcher v2).
  --pulse-shaping    Use the pulse-shaping stage to power the target (requires PicoGlitcher v2). Be sure to calibrate the pulse-shaping stage's voltage output.
  --voltage VOLTAGE  The voltage to set. Note that the voltage output of the pulse-shaping stage can not be controlled with this parameter. The voltage output of the pulse-
                     shaping stage must be set manually with the potentiometer.
```

Example:

- Power cycle and read the target's response:
```bash
stm32-power-cycle-and-read --target /dev/<target-tty-port> --rpico /dev/<rpi-tty-port>
```

- Power cycle and dump the flash content of an STM32 target in bootloader mode (without read-out protection active):
```bash
stm32-power-cycle-and-read --target /dev/<target-tty-port> --rpico /dev/<rpi-tty-port> --dump
```

## power-cycle

Test the power supply capabilities of your setup by executing this script.
If the `--rpico` argument is omitted (no Pico Glitcher connected), it will try to connect to the ChipWhisperer Pro instead.

```bash
power-cycle --help
usage: power-cycle [-h] [--rpico RPICO] [--power POWER] [--multiplexing] [--pulse-shaping] [--voltage VOLTAGE]

Power-cycle the target via different output stages of the Pico Glitcher (VTARGET, multiplexing stage, pulse-shaping stage or external power supply).

options:
  -h, --help         show this help message and exit
  --rpico RPICO      rpico port
  --power POWER      rk6006 port
  --multiplexing     Use the multiplexing stage to power-cycle the target (requires PicoGlitcher v2).
  --pulse-shaping    Use the pulse-shaping stage to power-cycle the target (requires PicoGlitcher v2). Be sure to calibrate the pulse-shaping stage's voltage output.
  --voltage VOLTAGE  The voltage to set. Note that the voltage output of the pulse-shaping stage can not be controlled with this parameter. The voltage output of the pulse-
                     shaping stage must be set manually with the potentiometer.
```

Example:

- Power cycle via the Pico Glitcher:
```bash
power-cycle --rpico /dev/<rpi-tty-port>
```

- Power cycle via the ChipWhisperer Pro:
```bash
power-cycle
```

## pulse-calibration

A small tool to calibrate the digital-to-analog converter of the pulse-shaping expansion board.

```bash
pulse-calibration --help
usage: pulse-calibration [-h] --rpico RPICO [--vhigh VHIGH] [--vlow VLOW]

options:
  -h, --help     show this help message and exit
  --rpico RPICO  rpico port
  --vhigh VHIGH  The measured maximum voltage of the pulse.
  --vlow VLOW    The measured minimum voltage of the pulse.
```

Execute the following command and follow the notes on the command line:
```bash
pulse-calibration --rpico /dev/<rpi-tty-port>
```

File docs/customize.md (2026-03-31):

# Customize your Pico Glitcher

In some cases the functionality findus provide will not be sufficient and you have to write your own code. 

## Pico Glitcher v1 GPIO pin overview

The Pico Glitcher v1 is built from these components:

Pico Glitcher v1.1 components

The GPIO pins of the Raspberry Pi Pico are connected to the following outlets:

| GPIO Pin | Function |
|---|---|
| 0 | RESET (with level shifter) |
| 1 | GLITCH_EN |
| 2 - 7 | unused outputs (with level shifter) |
| 8 - 14 | unused inputs (with level shifter) |
| 15 | TRIGGER (with level shifter) |
| 16 | high-power glitch output |
| 17 | low-power glitch output |
| 18 | TRIGGER (without level shifter), currently unused |
| 19 | Glitch output (without level shifter), currently unused |
| 20 | VTARGET_EN: used to enable and disable the target voltage |
| 21 | VTARGET over current input, currently unused |
| 22 | unused |
| 26 | Analog input |
| 27 | unused |
| 28 | unused |

## Pico Glitcher v1 GPIO pin header

If you want to write code for additional communication protocols, such as a UART-to-USB adapter, or an SPI-to-USB adapter, then the unused GPIO pins are perfect for that.
The output pins with level-shifting are `GPIO2` - `GPIO7`. For inputs the pins `GPIO8` - `GPIO14` can be used.

## Pico Glitcher v2 and v3 GPIO pin overview

Of course, the second revision of the Pico Glitcher can also be modified to suit your needs. Unfortunately, for better routing on the PCB and with added features, the GPIO pin assignment is different to version 1. Hence, code written for version 1 will likely not run on version 2.

The Pico Glitcher v2 is built from the following components:

Pico Glitcher v2.1 components

And the high-level overview of the Pico Glitcher v3 is shown below:

Pico Glitcher v3.0 components

The GPIO pins of the Raspberry Pi Pico are connected to the following outlets:

| GPIO Pin | Function |
|---|---|
| 0 | MUX1: Output 1 to multiplexer |
| 1 | MUX0: Output 0 to multiplexer |
| 2 | RESET (with level shifter) |
| 3 | GLITCH_EN (with level shifter) |
| 4 - 9 | unused outputs (with level shifter) |
| 10 | EXT2: Trigger input 2 with adjustable Schmitt Trigger |
| 11 | EXT1: Trigger input 1 with adjustable Schmitt Trigger |
| 12 | high-power glitch output |
| 13 | low-power glitch output |
| 14 | TRIGGER (with level shifter) |
| 15 | unused input (with level shifter) |
| 16 - 19  | unused in- and outputs (without level shifter) |
| 20 - 21  | unused inputs (with level shifter) |
| 22 | VTARGET_EN: used to enable and disable the target voltage |
| 26 | Analog input connected to glitch out line |
| 27 | Analog input connected to EXT1 input, currently unused |
| 28 | Analog input connected to EXT2 input, currently unused |

## Pico Glitcher v2 and v3 GPIO pin header

If you want to write code for additional communication protocols, such as a UART-to-USB adapter, or an SPI-to-USB adapter, then the unused GPIO pins are perfect for that.
Pins `GPIO16` - `GPIO19` are connected to the Raspberry Pi Pico without a level shifter and can be used bi-directionally.
The output pins with level-shifting are `GPIO4` - `GPIO9`. For inputs with level shifter the pins `GPIO15`, `GPIO20` and `GPIO21` can be used.

## Modify the MicroPython script

Add your modifications to `PicoGlitcher.py` ([https://github.com/MKesenheimer/fault-injection-library/blob/master/findus/firmware/PicoGlitcher.py](https://github.com/MKesenheimer/fault-injection-library/blob/master/findus/firmware/PicoGlitcher.py), or `fault-injection-library/findus/firmware/PicoGlitcher.py` if you cloned the whole repository) and upload the MicroPython script to the Raspberry Pi Pico:

```bash
cd findus/firmware
upload --port /dev/tty.<rpi-tty-port> --file PicoGlitcher.py
```

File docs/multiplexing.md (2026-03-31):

# Multiplexing

Multiplexing is a technique to quickly switch between different supply voltage levels of the microcontroller. Similar to glitching with the [crowbar technique](glitches.md), this can cause a fault in the microcontroller.
A fundamental difference is that with the multiplexing-fault-injection method, the supply voltage of the microcontroller is not pulled to GND, but intermediate voltages can also be used, for example 1.8V or user-defined voltages.
It is also possible to go through a sequence of different supply voltages, so called voltage profiles.

With the second hardware revision of the Pico Glitcher, it is possible to create different voltage profiles and apply them to the supply voltage of the target. This is made possible by the introduction of the multiplexing stage, section [customizing your Pico Glitcher](customize.md#pico-glitcher-v2-gpio-pin-overview).
The multiplexing stage also allows the target to be supplied with power. It is therefore not necessary to additionally supply the target with voltage via the `VTARGET` output.

## Multiplexing test setup

The following setup can be used to test the multiplexing stage of the Pico Glitcher v2 and v3:

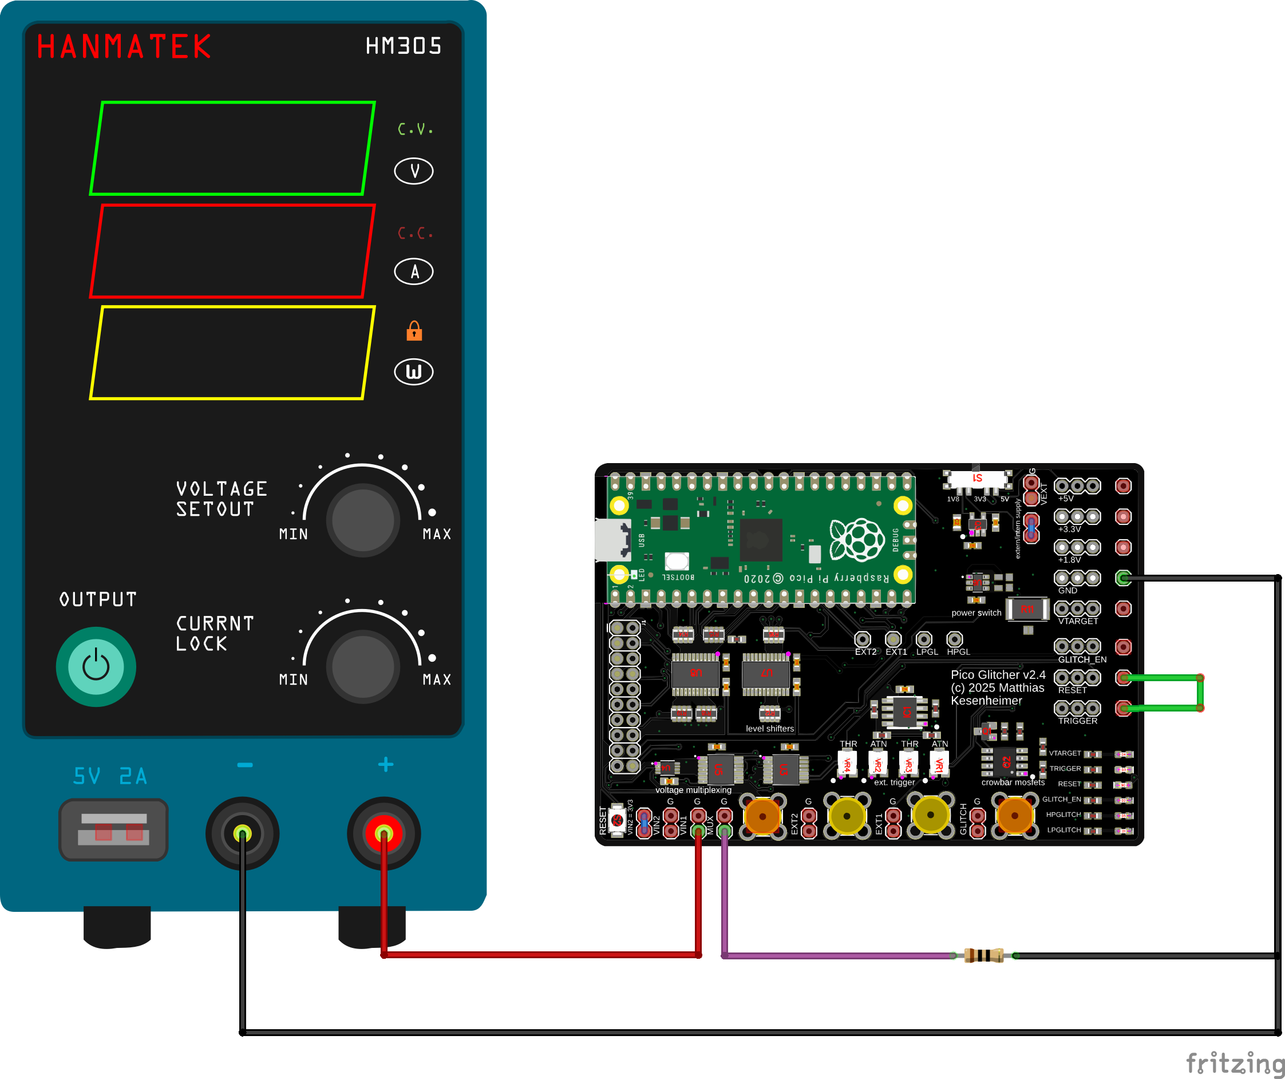
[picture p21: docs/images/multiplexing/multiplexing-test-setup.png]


Note that the power supply is optional and can be used to generate a third, intermediate voltage. Without the additional power supply, the multiplexing stage of the Pico Glitcher can switch between `3.3V`, `1.8V` and `0V`.
See `fault-injection-library/example/pico-glitcher.py` for a complete test script.

## Using the multiplexing stage

Implementing multiplexing in your fault injection campaign is no different to using the crowbar method.
Instead of setting up the crowbar transistors with `self.glitcher.set_lpglitch()` or `self.glitcher.set_hpglitch()`, the Pico Glitcher v2/v3 is configured to use the multiplexing stage with the following command:

```python
from findus import PicoGlitcher

glitcher = PicoGlitcher()
glitcher.init(port='/dev/ttyACM0')

# optional steps: set the initial voltage value
# the initial voltage for multiplexing must be hard-coded and can only be applied if the raspberry pi pico is reset and re-initialized.
glitcher.change_config_and_reset("mux_vinit", "1.8")
glitcher.init(port='/dev/ttyACM0')

glitcher.rising_edge_trigger()

glitcher.set_multiplexing()
```

Side note: you can also make use of the new trigger inputs of the Pico Glitcher v2/v3 by calling `glitcher.rising_edge_trigger(pin_trigger="ext1")`, described [here](schmitt.md). These trigger inputs are buffered by an adjustable Schmitt Trigger. If you do not provide the argument `pin_trigger` the default trigger input (`TRIGGER`) will be used.

After initializing the Pico Glitcher v2/v3, the multiplexing profile must be defined and the glitcher can be armed. This is typically done in the `while`-loop of the glitching script (see for example `fault-injection-library/example/pico-glitcher.py`).

```python
mul_config = {"t1": 100, "v1": "1.8", "t2": length, "v2": "GND"}
glitcher.arm_multiplexing(delay, mul_config)
```

The above profile, for example, will send a pulse of `1.8V` for `100ns`, followed by a 'crowbar' pulse of duration `length`, resulting in the following voltage trace:

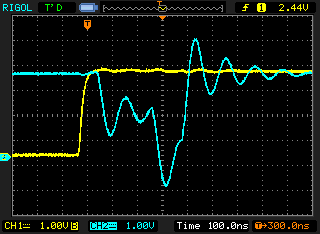
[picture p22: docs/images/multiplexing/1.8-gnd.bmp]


## Available Voltages

To switch between the different voltages, the user can choose from fixed voltages by selecting the appropriate voltage level, which is controlled by the internal multiplexer pins. The selection is made using the `mul_config` dictionary in `arm_multiplexing()` with voltage identifiers as values (e.g., `"v1": "GND"`, `"v2": "1.8"`).

Pico Glitcher v2.1 and v2.2:

- `GND`: Pulls the output to ground (0V).
- `1.8`: Outputs a fixed 1.8V reference.
- `3.3`: Outputs a fixed 3.3V reference.
- `VCC`: Outputs the voltage from the `VCC` input pin.

Pico Glitcher v2.4 and later:

- `GND`: Pulls the output to ground (0V).
- `1.8`: Outputs a fixed 1.8V reference.
- `VI1`: By selecting `VI1` the multiplexing stage outputs the voltage that is supplied at the `VI1` input.
- `VI2` / `3.3`: If the jumper 'VIN2 = 3V3' is set, by selecting `VI2` the multiplexing stage outputs `3.3V`. If the jumper is not set, arbitrary voltages can be applied to the `VI2` input.

## Example of voltage profiles

The software for controlling the multiplexing stage is extremely flexible and a vast number of voltage profiles with countless parameterizations can be generated.
Up to four different voltage steps can be parametrized and utilized with the general multiplexing configuration similar to
```python
mul_config = {"t1": t1, "v1": "GND", "t2": t2, "v2": "1.8", "t3": t3, "v3": "VCC", "t4": t4, "v4": "3.3"} 
```
where `VCC` is a user-supplied voltage level by the `VIN` input.

Below are some examples of voltage traces that can be applied to the target.

- `1.8V` voltage step, custom voltage of `0.95V`, followed by a pull to GND (`mul_config = {"t1": 4000, "v1": "1.8", "t2": 4000, "v2": "VCC", "t3": 1000, "v3": "GND"}`):

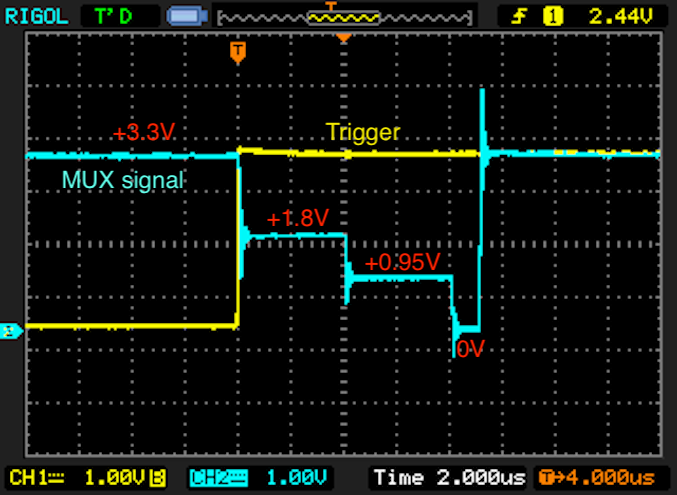
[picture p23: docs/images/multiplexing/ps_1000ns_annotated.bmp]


- `1.8V` voltage step followed by a pull to GND (`mul_config = {"t1": t1, "v1": "1.8", "t2": length, "v2": "GND"}`):

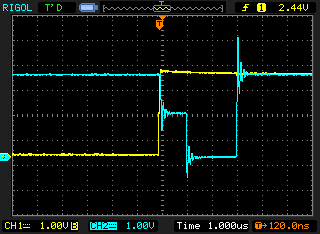
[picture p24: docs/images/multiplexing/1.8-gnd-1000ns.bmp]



- `1.8V` voltage step, `3.3V` voltage step, crowbar pull to GND (`mul_config = {"t1": t1, "v1": "1.8", "t2": t2, "v2": "3.3", "t3": length, "v3": "GND"}`)

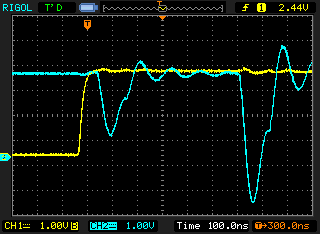
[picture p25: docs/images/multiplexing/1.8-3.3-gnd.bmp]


- double glitch (one to GND, the other to `1.8V`), separated by `400ns` (`mul_config = {"t1": length, "v1": "GND", "t2": 400, "v2": "3.3", "t3": length, "v3": "GND"}`, `mul_config = {"t1": length, "v1": "1.8", "t2": 400, "v2": "3.3", "t3": length, "v3": "1.8"}`):

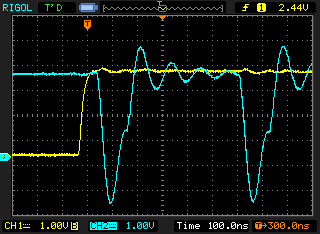
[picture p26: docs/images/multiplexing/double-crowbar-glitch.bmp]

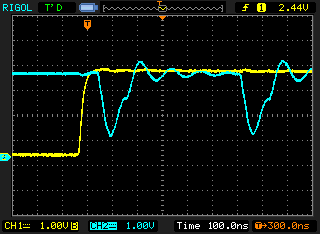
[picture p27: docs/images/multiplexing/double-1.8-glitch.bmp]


- GND pull, `1.8V` voltage step, GND pull, second `1.8V` voltage step (`mul_config = {"t1": length, "v1": "GND", "t2": 2*length, "v2": "1.8", "t3": 2*length, "v3": "GND", "t4": length, "v4": "1.8"}`):

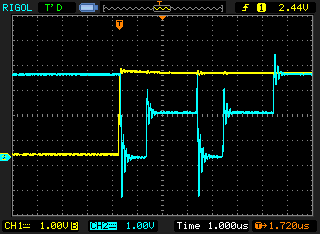
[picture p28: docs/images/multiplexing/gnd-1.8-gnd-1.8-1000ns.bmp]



By using the multiplexing stage, the possible parameter combinations can increase exponentially, which makes the search for suitable parameters more difficult. Of course, one can also keep multiple parameters constant and only vary one specific parameter. Another option is to vary all parameters and apply a [genetic algorithm](genetic.md) to the search space to find suitable parameters.

## Technical details
In order to switch quickly between different voltage levels, the chip `TS3A4751` from Texas Instruments is used. This chip is a 4-channel analog switch in SPST (single-pull-single-through) configuration.
To make the analog switch easier to control and to reduce the signal lines from the Raspberry Pi Pico to the analog switch, a digital demultiplexer is used (`SN74LVC1G139DCUT`). Since the voltage levels are reversed after the demultiplexer, a 4-channel not-gate is used to reverse the voltage levels.

Multiplexing schematic for the Pico Glitcher v2.1 and v2.2:


Multiplexing schematic for the Pico Glitcher v2.4 and later:


This setup seems rather complicated to switch between four different voltage levels. However, the choice of analogue switches is not exactly extensive or does not match the requirements of a fast-switching fault-injection device. The required properties of the analogue switch are as follows:

- Fast switching: less than 5ns switching time.
- Number of channels: four channels for flexible switching between as many voltage levels as possible.
- Low resistance: to avoid switching losses, a low resistance of 1Ω or less is required.
- High output current: a high continuous current of at least 100mA is needed to keep the device powered even for a long time. This maximum current should be suitable for most microcontrollers.

All these requirements are met by the `TS3A4751`, even if the choice of this chip has made controlling it a little more complicated.

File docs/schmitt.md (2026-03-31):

# Schmitt Trigger EXT inputs

The trigger inputs `EXT1` and `EXT2` are particularly useful for noisy logic signals, as the noise can be easily suppressed by the adjustable Schmitt Trigger. If the signal oscillates or is disturbed in any other way, these disturbances can be filtered by selecting a suitable threshold.



Use the potentiometer labeled `THR` to adjust the threshold of the Schmitt Trigger. The threshold is lowered by turning the potentiometer counter-clockwise.

The potentiometer `ATN` can be used to attenuate the signal, if necessary. Turning the potentiometer clockwise disables attenuation and uses the full signal range.

Changes have been made in version 3 to the `EXT2` trigger input. Now the hysteresis of the trigger behavior can be adjusted.



The `HYS` potentiometer adjusts the hysteresis of the Schmitt trigger input `EXT2`. It controls the difference between the upper and lower switching thresholds. A larger hysteresis means the input signal must change more before the output switches, while a smaller hysteresis makes the output more sensitive to small signal changes.

With no hysteresis, the Schmitt trigger switches at the same input level for both rising and falling edges. The output changes state exactly at a single threshold, making the circuit sensitive to noise and small fluctuations around that level.

When hysteresis is introduced, the switching point depends on the direction of the input signal. On a rising input, the signal must reach the upper threshold before the output changes, causing the transition to occur later than it would without hysteresis. On a falling input, the signal must drop below the lower threshold before switching back, which also delays the transition compared to a single-threshold comparator.

Increasing the hysteresis widens the gap between the upper and lower thresholds. This makes the circuit switch later on both rising and falling edges, relative to the no-hysteresis case. Reducing the hysteresis narrows this gap, bringing the two switching points closer together until they coincide when hysteresis is effectively zero.

This behavior is what gives the Schmitt trigger its noise immunity: small variations around the switching level do not cause repeated transitions, and the exact timing of state changes can be deliberately shifted by adjusting the hysteresis.

The schematics of the new Schmitt trigger inputs can be seen below.



## How to set the potentiometers

The `ATN` potentiometer should be turned clockwise completely to the right to use the full signal range.
If you have trigger signals that exceed the voltage range of the Pico Glitcher (max. `5V`), use the `ATN` potentiometer to attenuate the input signals to a range acceptable for the Raspberry Pi Pico.

By turning the `THR` potentiometer counter-clockwise to the left, the threshold is lowered, which means the Pico Glitcher triggers at lower signals. Start the `THR` potentiometer at the highest threshold position (right), then lower it (turn it counter-clockwise) until the trigger is observed.

Adjust the `HYS` potentiometer in the same way as the `THR` potentiometer. Start the `HYS` potentiometer at the highest hysteresis position (right), then reduce it (turn it counter-clockwise) until the desired hysteresis is achieved.

Choose the trigger input (`EXT1` or `EXT2`) based on your setup and the quality of your trigger signal. Try each input to determine which works best.

Once the potentiometers are set for a particular configuration, do not change them during your glitching campaign. Changing the threshold or hysteresis values can affect your glitching parameters, particularly the `delay` value.

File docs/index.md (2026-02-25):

# Welcome to findus (aka fault-injection-library)

This library is intended to make fault injection attacks against microcontrollers accessible for hobbyists and to introduce the topic of voltage glitching.
Findus offers an easy entry point to carry out your own attacks against microcontrollers, SoCs and CPUs.
With the provided and easy to use functions and classes, fault injection projects can be realized quickly.

The fault-injection-library has been built to work with hardware that consists of a common MOSFET, the [Raspberry Pi Pico](https://www.raspberrypi.com/products/raspberry-pi-pico/) as the controller and a few other cheap components.
The Raspberry Pi Pico is not only cheap and available for the hobbyist, but also a very capable microcontroller.
Furthermore, this library supports the [ChipWhisperer Pro](https://rtfm.newae.com/Capture/ChipWhisperer-Pro/) and the [ChipWhisperer Husky](https://rtfm.newae.com/Capture/ChipWhisperer-Husky/) as well.

Pico Glitcher Board

The Pico Glitcher was developed to minimize the effort and requirements for the hardware setup. The Pico Glitcher is optimized for use with findus and makes it particularly easy to carry out fault injection attacks.

## Where to get the Pico Glitcher from?

The Pico Glitcher and accessories can be obtained from [https://faultyhardware.de/](https://faultyhardware.de/).

## Links and further resources

If you have feature requests or issues, please contact me:

- [twitter @BartimaeusvUruk](https://x.com/BartimaeusvUruk)
- [Mastodon @mkesenheimer@mastodon.social](https://mastodon.social/@mkesenheimer)
- [Faulty Hardware discord server](https://discord.gg/8mqEVPG6k7)
- [Pico Glitcher v3](https://faultyhardware.de/en/home/21-pico-glitcher-v3.html)
- [STM8s target board](https://faultyhardware.de/en/home/30-stm8-target-board.html)

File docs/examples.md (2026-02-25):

# Example Projects

Start your glitching career with these examples.

## Important

Some connections on the Pico Glitcher are not obvious and incorrect connection can lead to errors or even destruction of the hardware. So be especially careful when rebuilding the following examples. In particular, be aware that some pin headers carry both the signal and a connection to `GND`. The following pins on the signal lines, marked with a capital `G`, are connected to `GND`.

GND connections

## Test the functionality of your Pico Glitcher

The following  setup can be used to test the Pico Glitcher.

- Connect `TRIGGER` input with `RESET`.
- Between `GLITCH` and `VTARGET`, connect a 10 Ohm resistor (this is the test target in this case).
- Optionally connect channel 1 of an oscilloscope to `RESET` and channel 2 to `GLITCH`.

Example setup

Next, run the test script `pico-glitcher.py` located in `fault-injection-library/examples`:

```bash
cd examples
python pico-glitcher.py --rpico /dev/<rpi-tty-port> --delay 1000 1000 --length 100 100
```

You should now be able to observe the glitches with an oscilloscope on the 10 Ohm resistor.
Measure the expected delay and glitch length with the oscilloscope.

## UART Trigger

- Connect `TRIGGER` input to `RX` and `TX` of a USB-to-UART adapter
- Between `GLITCH` and `VTARGET`, connect a 10 Ohm resistor (this is the test target in this case).
- Optionally connect channel 1 of an oscilloscope to `RESET` and channel 2 to `GLITCH`.

Example setup

Next, run the test script `pico-glitcher-uart.py` located in `fault-injection-library/examples`:

```bash
cd examples
python pico-glitcher-uart-trigger.py --rpico /dev/<rpi-tty-port> --target /dev/<target-tty-port> --delay 1000 1000 --length 100 100
```

You should now be able to observe the glitches with an oscilloscope on the 10 Ohm resistor.
Measure the expected delay and glitch length with the oscilloscope.

## Edge Counting Trigger

Sometimes it is clever to trigger after a certain number of edges in a signal. For example, if the communication protocol is unknown or is not supported by the Pico Glitcher as a trigger signal.
However, since most signals are deterministic, the number of edges of the signal can be used as a trigger signal.

The script `pico-glitcher-edge-counter.py` located in `fault-injection-library/examples` can be used to test the edge-counting trigger capabilities of the Pico Glitcher. Use the same connections as in [the first setup](#test-the-functionality-of-your-pico-glitcher).

Run the following command to execute the script that implements edge-counting:

```bash
cd examples
python pico-glitcher-edge-counter.py --rpico /dev/<rpi-tty-port> --delay 1000 1000 --length 100 100
```

Observe the edges of the signal on the `RESET` line and the position of the glitch on the `GLITCH` output.

## STM8s Glitching

Difficulty: Simple

If you have the STM8s target board (available [here](https://faultyhardware.de/en/home/30-stm8-target-board.html)), you can learn how to atttack targets with findus and the Pico Glitcher. The STM8s MCUs are very easy to glitch.

Similar to the STM32 series, the STM8s has a configurable read-out protection (ROP), which can be used to protect the flash content from unauthorised access. However, the STM8s does not have a UART bootloader like a MCU from the STM32 series (see [STM32 glitching](#stm-black-pill-stm32f401-glitching)), meaning that an ST-Link programming adapter would be required for an example target.

In order to have a simple test target and also a realistic scenario, a STM32-like UART bootloader was developed for the STM8s target board. The bootloader software can be found [on github](https://github.com/MKesenheimer/stm8-bootloader). However, it should not be necessary to install the software yourself.

The bootloader implements several UART commands that can be used, for example, to read or write the flash content or to set the option bytes (configure the ROP). To read a memory area from flash, the following commands have to be sent to the STM8s MCU in bootloader mode via UART. Each command is acknowledged by an `ACK` (`0x79`) if successful or `NACK` (`0x1f`) if not.

- bootloader init (`0x7f`)
- read memory command (`0x11`), followed by the address to read from (for example `0x8000`)
- the number of bytes to read minus one, starting from the specified address (for example `0xff` to read 256 bytes)

The bootloader checks if reading from flash memory is allowed, and responds with an `ACK` on the read memory command. If flash access is not allowed (default behavior when ROP is set), the bootloader returns a `NACK` on the read memory command.
The following C code reflects this check:

```C
inline void bootloader_enter() {
    // ...
    } else if (cmd == 0x11) {
        // check if ROP is set
        uint8_t rop = read_flash(0x4800);
        if (rop == 0xaa) {
            serial_send_nack();
        } else {
            serial_send_ack();
            read_memory();
        }
    // ...
}
```

In order to attack the bootloader and obtain the flash content, a glitch must be triggered while this check is being carried out. The script [stm8s-readmemory.py](https://github.com/MKesenheimer/fault-injection-library/blob/master/projects/stm8s/stm8-readmemory.py) therefore configures the Pico Glitcher to trigger on the UART word `0x11`. The following figure shows the UART communication with the bootloader. The glitch is executed after the read memory command.

Bootloader communication

To carry out the attack on the STM8s in bootloader mode, the target board is connected to the Pico Glitcher as follows. A USB-C cable is also used to connect the target board to the host computer which will provide the UART interface.

STM8s crowbar glitching
STM8s crowbar glitching setup

If you don't have an SMA cable, twist two jumper cables and connect them as shown in the following figure (black and brown cables). Connect the black cable to `GND` and the brown cable to `GLITCH`.

No SMA cable

- red: 1.8V, supply voltage for the `VCAP` input of the STM8s MCU
- black: `GND`
- green: Reset line, connected to the Reset input of the target board
- yellow: Trigger line, connected to the UART `TX` line. If the UART word `0x11` is observed on this line, the glitch is triggered.
- purple: `GLITCH`, connected to `VCAP` of the STM8s

Also, for glitching the jumper on the STM8s target board must be in the `ISP ENABLE` position.

Next, we determine the time between the read memory command `0x11` and the response (`ACK` or `NACK`) from the microcontroller. The check whether ROP is active must happen between those two events. It turns out (and by observing the [Analog Plotter](../adc.md)), the glitch must be placed between 106,000 and 107,500 ns.

<TODO: AnalogPlot figure>

As always, the glitch length is estimated: the length must not be too long, but also not too short. We start with a broad range of 10 to 100 ns.
Overall, the glitching script is called with the following parameters (the tty ports can of course be different in your case).

```bash
git clone https://github.com/MKesenheimer/fault-injection-library.git
cd fault-injection-library/projects/stm8s
python stm8-readmemory.py --rpico /dev/tty.usbmodem11301 \
  --target /dev/tty.usbserial-A50285BI --delay 106_000 107_500 \
  --length 10 100
```

After a few attempts you should observe the first positive results.

Successful glitches

The parameterspace could be optimized to increase the success rate even more.

Optimized parameterspace

Note how the successful events shift upwards if no SMA cable and instead two jumper cables are used to connect to the `GLITCH` line.

Parameterspace without SMA cable

### Technical deep-dive - why do we attack the VCAP line and not VCC?

The `VCAP` line of the STM8 microcontroller is targeted in voltage glitching attacks rather than the VCC line because it directly affects the internal core voltage of the microcontroller.

VCAP input

The `VCAP` pin is connected to the internal voltage regulator, which powers the CPU core. This voltage is typically lower (e.g., 1.8V) than the external supply (VCC, often 3.3V or 5V) and is more sensitive to small fluctuations. Glitching the core voltage can cause instruction corruption, bypass security checks, or cause unintended behavior.

Also, the core voltage (`VCAP`) is isolated from the peripheral voltage (VCC). Glitching VCC may cause a system reset or disrupt external interfaces, while glitching `VCAP` directly targets the internal logic without affecting external components.

The VCAP line is in general more vulnerable and effective for precision attacks on the core logic, while the VCC line is more resilient due to the internal voltage regulation.

### Bonus: Using the multiplexing method

The voltage glitching attack against the STM8 target board can also be performed using the voltage multiplexing stage.
The setup is similar to glitching with the crowbar method, however, the connection to the `1.8V` supply to power the microcontroller is not required. When glitching with the multiplexing stage, power can be supplied directly from the multiplexing stage.
Note, that this attack can only be performed with the Pico Glitcher v2 (and later versions).

STM8s multiplexing glitching

**Important**: In order to flush the multiplexing stage and initialize the multiplexing stage with the correct voltage, the script has to be execute once before connecting to the target. Make sure the correct voltage can be measured at the `MUX` output (`1.8V`). Other voltages may damage the STM8s target board.

We first try scanning over a larger parmater space with the following command.

```bash
python stm8-readmemory.py--rpico /dev/tty.usbmodem11301 \
  --target /dev/tty.usbserial-A50285BI --delay 104_000 110_000 \
  --length 0 100 --multiplexing
```

After a while a positive event is observed, as can be seen in the following figure.

Success with the multiplexing method

It turns out that the timing is a little different than with the crowbar method. Now that we have found a positive experiment, we can optimize our search by homing in around the 105,000 nanosecond mark. In this case, however, the multiplexing method appears to be less effective than the crowbar method.

### Programming the STM8s target board

If something goes wrong and the memory of the STM8s is wiped (or simply if we want to flash the target with another program), we can flash the STM8s with the following steps. For this an ST-LINK V2 is needed.
The setup is as follows:

Target board programming

To function correctly, the jumper must be on the `VCAP` position.

Note, to program the STM8s target board, the program [stm8flash](https://github.com/vdudouyt/stm8flash) must be installed.
We continue by downloading the STM8s bootloader, compiling it and flashing it to the target board.

```bash
git clone https://github.com/MKesenheimer/stm8-bootloader.git && cd stm8-bootloader
make
make flash
make enable-rop
```

Now we check if the bootloader responds correctly to the isp programmer. For that we execute the following command (we could also use the command line tool `stm8-programmer` which is part of findus):

```bash
python3 isp-programmer/STM8Programmer.py -p /dev/tty.usbserial-11140 --read 0x8000 --number-of-bytes 255
```

If everything is correct, the bootloader should respond with the memory contents via serial:

```bash
b'success: bootloader enter succeeded'
b'success:'
b"\x82\x00\x80\x80\xcc..."
```

We continue by enabling the read-out protection

```bash
make enable-rop
```

If we now run the above command, the bootloader should not respond with the memory contents which tells us that the read-out protection is active:

```bash
b'success: bootloader enter succeeded'
b'error: sending read memory command failed'
b''
```

## Airtag Glitching

Difficulty: Simple

It has already been shown by other works ([Stacksmashing](https://youtu.be/_E0PWQvW-14?si=zNzqpAz84Lce6TEz), [Adam Catley](https://adamcatley.com/AirTag.html), [Colin O'Flynn](https://colinoflynn.com/tag/airtag/)) that the chip installed on the Airtag, the nrf52832, is susceptible to voltage glitching attacks. The setup for the voltage glitching attack with the Pico Glitcher is as follows:

Airtag Glitching

To ensure that the correct voltage levels are available to the Segger J-Link, a level converter is inserted between the Airtag and J-Link. Voltage levels of 1.8V are required on the Airtag side and 3.3V on the J-Link side. The Pico Glitcher's voltage generation capabilities can be used to generate the different voltage levels.

The numbers on the pads of the Airtag PCB represent the following signals:

|Name | Description |
|-----|---|
|VCC1 | +3.0V input (1 of 2 - both needed)* |
|VCC2 | +3.0V input (2 of 2 - both needed)* |
|GND  | Ground | 
| | |
| 5 | VCC2 (Connects to VCC2 input) |
| 6 | VCC1 (Connects to VCC1 input) |
| 7 | GND |
| 8 | nRF ball E2 (P0.16) |
| 9 | nRF ball D3 (P0.26) |
| 19  | 1.8V SPI Flash - Data In (COPI) / nRF ball H3 (P0.16) |
| 20  | 1.8V SPI Flash - Data Out (CIPO) /nRF ball H4 (P0.15) |
| 21  | 1.8V SPI Flash VCC |
| 22  | 1.8V SPI Flash - SCLK / nRF ball G3 (P0.17) |
| 24  | 1.8V SPI Flash - Chip Select (CS)/ nRF ball F4 (P0.11) |
| 29  | Apple Logo :) GND |
| 30  | nRF ball H1 (P0.21/nRST) |
| 31  | nRF ball H2 (P0.18/SWO) |
| 34  | 1.8V from nRF |
| 35  | nRF ball F1 (SWCLK) |
| 36  | nRF ball G1 (SWDIO) |

The colors of the connections encode these signals:

- red: `VTARGET`, supply voltage of the air tag (`3.3V`)
- brown: `VRef`, reference voltage for the level shifter (`1.8V`)
- black: `GND`
- green: `TRIGGER` line, connected to `1.8V` of the airtag. If this line is supplied with voltage, the trigger is set.
- purple: `GLITCH`, connected to `VCORE` of the airtag. This is the power supply of the nrf52832

An oscilloscope on `VTARGET` and `VCORE` is also used to monitor the fault-injection campaign and to narrow down the `delay` paremeter.
The following figures show the voltage curve of `VTARGET` (blue) and `VCORE` (yellow).
The fine voltage drop in `VCORE` after about 4.5ms after activating the power supply is striking.
This area is interesting for gliching attacks, as the microcontroller nrf52832 switches from the bootloader to the user program (application) and has a higher energy consumption after this switch.
Shortly before this switch, a check is made to see whether read-out protection is set. Glitches are therefore set around the 4.5ms mark.

Voltage trace

Glitch

The magnitude of the glitch length is estimated from the processor frequency. For the nrf52832 this is 64 MHz, i.e. one CPU cycle takes approx. 16 ns. However, as other components such as capacitors or even the supply lines can change the "sharpness" of the glitch, a multiple of this duration is selected as the starting point. The glitch duration must not be too long, otherwise the microcontroller will be driven into reset. A glitch duration of 300 ns is selected initially.

The script `nrf52832-glitching.py` located at `projects/nrf52832` (or [here](https://github.com/MKesenheimer/fault-injection-library/blob/master/projects/nrf52832)) is used to perform the glitching campaign. After connecting the Pico Glitcher to the Airtag according to the schematics, run the following commands to start glitching:

```bash
cd fault-injection-library/projects/nrf52832
python pico-glitcher.py --rpico /dev/<rpi-tty-port> --delay 300 600 --length 3_300_000 3_600_000
```

Note, in order to communicate with the Airtag over SWD, [openocd](https://openocd.org) must be installed. Additionally, the script [testnrf.cfg](https://github.com/MKesenheimer/fault-injection-library/blob/master/projects/nrf52832/testnrf.cfg) must be in the root directory of the script `pico-glitcher.py`.
During the glitching campaign, run the `analyzer` script in a separate terminal window:

```bash
analyzer --directory databases
```

This spins up a local web application on [http://127.0.0.1:8080](http://127.0.0.1:8080) which can be used to observe the current progress.

Parameter space web application

The successful glitch and dump of the Airtag's flash content can be seen in the following figures.

Successful glitch

Successful dump

### Details of the script nrf52832-glitching.py 

After initializing the glitcher, setting up the database and the logging mechanism, a random point from the parameter space is rolled in an endless loop from the arguments passed.
The advantage of rolling a random parameter point is that a successful glitch can be achieved more quickly, even if a large range is tested.
It also gives a quicker overview of interesting areas. The `glitcher.arm` function arms the glitcher and waits until the trigger condition occurs.

```bash
# set up glitch parameters (in nano seconds) and arm glitcher
length = random.randint(s_length, e_length)
delay = random.randint(s_delay, e_delay)
self.glitcher.arm(delay, length)
```

The target is then restarted (power-cycled), which triggers the glitch. The glitch is sent after the time `delay` with the duration `length`.
The function `test_jtag()` is used to check whether the nrf52832 can be interacted with on the SWD interface and, if so, the flash content is downloaded.

```bash
# power cycle target
self.glitcher.power_cycle_target(0.08)
 
# block until glitch
try:
    self.glitcher.block(timeout=1)
    # dump memory
    response = test_jtag()
except Exception as _:
    print("[-] Timeout received in block(). Continuing.")
    self.glitcher.power_cycle_target(power_cycle_time=1)
    time.sleep(0.2)
    response = b'Timeout'
```

The following commands are used to characterize the response of the target via SWD and the parameter point is inserted into the database in the corresponding color.

```bash
# classify response
color = self.glitcher.classify(response)

# add to database
self.database.insert(experiment_id, delay, length, color, response)
```

## STM Black Pill (STM32F401) Glitching

Difficulty: Advanced

STMicroelectronics offers a wide range of STM32 microcontrollers, based on ARM Cortex-M cores, catering to various performance and power requirements. These microcontrollers are integral in applications across industrial automation, consumer electronics, automotive systems, and IoT devices, providing efficient processing, connectivity, and real-time control.
Since they are widely used, these microcontrollers are a interesting target for hardware attacks.

A processor from the ST32F4 series was chosen as the target, specifically the STM Black Pill board with the STM32F401 microcontroller which is based on the Arm® Cortex®-M4 architecture. The Black Pill board contains all necessary components for operation.

STM32 processors utilize a readout protection (RDP) that is divided into three stages.
RDP level 1 (RDP-1) is the first level that restricts access to the microcontroller.
With RDP-0 selected, no protection is active, i.e. the flash content of the microcontroller can be read out and the debug functions can be accessed.
With RDP-1, the readout protection is active for the program flash, but the RAM of the microcontroller can still be accessed for debugging purposes. With RDP-2 selected, the microcontroller is completely closed. It is possible to switch from RDP-1 to RDP-0, but the program flash will be deleted. Switching from RDP-2 to RDP-1 is not supported by the microcontroller.
The level of the readout protection can, for example, be set or read via the [STM32CubeProgrammer](https://www.st.com/en/development-tools/stm32cubeprog.html).

The following setup was selected to glitch the microcontroller. The glitch is inserted at one of the voltage regulator capacitors (`VCAP` pin). In order to achieve good results, the capacitor have to be removed from the board.

STM Black Pill Glitching

The colors of the connections encode these signals:

- red: Voltage supply of the Black Pill board (5V)
- purple: 1.8V voltage supply to the `VCAP` pin decoupled with a 10 Ohms resistor and glitch input. The 1.8V voltage supply via the resistor is needed to get a stable voltage on the `VCAP` pin.
- yellow: TX line to the STM32 microcontroller.
- orange. RX line to the STM32 microcontroller.
- also yellow: Trigger line, connected to the TX line to the STM32 microcontroller. If 0x11 (memory read command) is transmitted, the trigger is set.
- geen: Reset line to reset the microcontroller.

Additionally, an oscilloscope is connected to the TX line and the `VCAP` pin (glitch line).

The bootloader of the STM32 processors offers a specific option for reading out the program flash.
The bootloader mode is activated when the `BOOT0` pin is connected to VCC.
This can be done by pressing the `BOOT0` switch on the Black Pill board, or by shorting the `BOOT0` pin to `VCC`.

To read the program memory, a series of commands must be sent to the processor in bootloader mode via UART, which instruct the processor to return parts of the flash memory (see [STMicroelectronics: USART protocol used in the STM32 bootloader](https://www.st.com/resource/en/application_note/an3155-usart-protocol-used-in-the-stm32-bootloader-stmicroelectronics.pdf)).
Among other things, the 'read memory' command is sent to the processor via UART, i.e. the byte 0x11.
The glitcher is configured in such a way that it triggers as soon as byte 0x11 is recognized on the TX line.
As the transmission of a  second checksum byte requires additional 80µs, the interesting range begins at a `delay` of 80,000ns and ends as soon as the bootloader sends the acknowledgement approximately 20-40µs later. In practice, it turns out that a range from 95,000ns to 125,000ns must be scanned.
The duration of the glitch is selected just short enough so that the microcontroller is not reset (´brown-out’) and long enough so that the glitch also has an effect. A `length` of 25 to 35ns turns out to be good.

The script to perform the glitch can be found in `projects/stm32f40x` or [here](https://github.com/MKesenheimer/fault-injection-library/blob/master/projects/stm32f40x/stm32f4-glitching.py) and is typically run with the command:

```bash
python stm32f4-glitching.py --target /dev/tty.usbserial-A50285BI --rpico /dev/tty.usbmodem11101 --power /dev/tty.usbserial-10 --delay 95_000 125_000 --length 25 35
```

In the following figure, the glitch is barely visible after the bytes 0x11 and 0xee are sent via UART.

Oscilloscope trace of a glitch

A successful glitching campaign can be seen in the following figure. Successful glitches were found around the parameter point (104,000ns, 33ns), for example.

Parameter space and a successful glitch

A status message is printed with the memory content if a successful glitch was found.

Memory dump

### Things that can and will go wrong

*Problem 1: Flash is sometimes completely erased*

In addition to the memory read command, the bootloader also offers the memory erase command. If this function is accidentally triggered by a glitch, the entire flash content of the microcontroller is erased. This can happen up to once every 100,000 attempts. Interesting data (such as the firmware) is of course lost in that case.

*Problem 2: PCROP protection*

It can also happen that the SPRMOD bit is set in the event of a glitch. This bit causes the bytes returned by the bootloader when reading the flash contents to be masked with 0x00. This means that the bootloader is in the correct path of the read memory routine due to the glitch, but any response from the bootloader will be replaced with a zero by a downstream instance in the microcontroller.

If the PCROP bit is set by mistake, the glitching process must be aborted and the entire flash reprogrammed. Interesting data (e.g. firmware) will be lost.

## Burst Glitching

If the position of the glitch is unknown, a fast overview of the parameters space can be obtained with the burst glitching feature of the Pico Glitcher.
Add the arguments `number_of_pulses` and `delay_between` when invoking the function `arm()`, where `number_of_pulses` is the number of pulses to emit and `delay_between` is the delay between each pulse. For example:

```python
from findus import PicoGlitcher
import random
import sys

glitcher = PicoGlitcher()
glitcher.init(port="/dev/ttyACM0", ext_power="/dev/ttyACM1", ext_power_voltage=3.3)

# set up database with a third parameter delay_between
database = Database(sys.argv, column_names=["delay", "length", "delay_between"])

# define delay, length, delay_between
delay = random.randint(0, 1_000)
length = random.randint(100, 200)
delay_between = random.randint(100, 200)

# burst glitching
glitcher.arm(delay=delay, length=length, number_of_pulses=20, delay_between=delay_between)

# reset target for 0.01 seconds (the rising edge on reset line triggers the glitch)
glitcher.reset_target(0.01)

# read the response from the device (for example UART, SWD, etc.)
response = ...

# classify the response and put into database
# If the method classify is not sufficient, overload classify with your own implementation
color = glitcher.classify(response)

database.insert(experiment_id, delay, length, delay_between, color, response)
```

As there are now three parameters in the database, different cuts through the parameterspace can be made to analyze different scenarios:

```bash
analyzer --directory databases -x delay -y length
analyzer --directory databases -x delay -y delay_between
```

## More examples

More example projects can be found at [https://github.com/MKesenheimer/fault-injection-library/tree/master/projects](https://github.com/MKesenheimer/fault-injection-library/tree/master/projects) or under `fault-injection-library/projects` if you cloned the whole repository.

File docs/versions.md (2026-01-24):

# Changelog

This is a brief summary of the different versions of Pico Glitcher and what has changed between versions.

## Pico Glitcher v1

### v1.0

- First prototype version of the Pico Glitcher with mainly the Raspberry Pi Pico, two power MOSFETs for glitching, level shifters and a switchable power supply.

### v1.1

- Public release of the Pico Glitcher v1.1
- Layouting changed. Fixed issues with some LEDs not lighting correctly.

## Pico Glitcher v2

### v2.0

- First prototype version of the Pico Glitcher v2.
- v2.0 included for the first time a voltage multiplexer that could switch between GND, 1.8V, 3.3V and an arbitrary voltage applied to the VIN input.
- Because a logic gate with open drain outputs was selected, the multiplexer stage did not work properly. This could be fixed with additional pull-up resistors.
- The capacity of the capacitor on the VTARGET output was reduced.

### v2.1

- Public release of the Pico Glitcher v2.1.
- The logic gates were fixed and the multiplexer stage works correctly.
- Increased the pin count of the multi-purpose GPIO header from 16 pins to 20 pins to support the pulse shaping expansion board.
- Removed the level shifters between GPIO pins 16-19 to interface the pulse shaping expansion board.
- Note: the power switch TPS2041 that controls the targets power supply VTARGET can only switch voltages above 2.2 V. The power switch has been replaced with TPS22860 in versions 2.3 and later to allow lower voltages to be switched.

### v2.2

- Improved PCB layout, such as thicker tracks for power traces.
- In order to switch between two arbitrary voltages with the multiplexer stage, the connection to 3.3V has been removed. Instead, a second input (VIN2) on the multiplexer stage can be used to supply a second arbitrary voltage.
- The multiplexer stage now consists of two arbitrary voltage inputs (VIN1, VIN2) and a second jumper to fix VIN2 at 3.3V.

### v2.3

- Replaced the TPS2041 power switch with the TPS22860 power switch, which has a faster switching rate and can switch lower voltages.
- Replaced NH245 level shifters with TXB0108 bi-directional level shifters.
- Removed the capacitors on the VTARGET output. This allows for faster switch on and off the power ouput.
- Major problems with this version: The red power LED did not light properly. Also, the level shifters did not work properly because they did not sense the signal direction correctly. This meant that the Pico Glitcher v2.3 could only be used with 3.3V logic levels. All other functions remain unaffected.

### v2.4

- Improved PCB layout.
- Switched back to NH245 level shifters which proved to be the better choice for that application.
- Added a 10Ω resistor to the VTARGET output to protect the power switch. This 10Ω resistor can be bypassed by shorting the solder bridge below the resistor.

### v3.0

- Replaced the Raspberry Pi Pico with the more powerful Raspberry Pi Pico 2.
- Improved power supply: Four different voltages to interface with various microcontrollers can be chosen from: 1.2V, 1.8V, 3.3V, and 5V.
- Improved Schmitt trigger inputs provide better and more reliable triggering.
- Tented vias and more vias in critical regions for better impedance.

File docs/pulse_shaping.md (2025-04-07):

# Pulse-Shaping

The pulse-shaping expansion board for the Pico Glitcher allows for fine-tuned control over glitch waveforms by defining voltage transitions over time. This technique is useful for more sophisticated fault injection attacks where simple square-wave glitches might not be effective.

As described previously in section [comparing different glitching modes](glitches.md), pulse-shaping is the method of generating arbitrary voltage profiles that are applied to the power rail of the target device. This board gives you very fine control over the voltage curve with which the target device is supplied. Not only that, but unwanted oscillations after the transitions between two voltage levels can also be suppressed, resulting in cleaner voltage curves.

This method was introduced to the Pico Glitcher v2 with a special expansion board and is described briefly in the following.

## Pulse-shaping test setup

The following test setup can be used to test the pulse-shaping expansion board of the Pico Glitcher v2:



## Using the pulse-shaping stage

Before using the pulse-shaping functionality, the Pico Glitcher needs to be initialized:

```python
from findus import PicoGlitcher

glitcher = PicoGlitcher()
glitcher.init(port='/dev/ttyACM0')

glitcher.rising_edge_trigger()

# choose pulse-form glitching
glitcher.set_pulseshaping(vinit=3.3)
```

- `glitcher.rising_edge_trigger()`: To ensure the glitch is applied at the correct moment, a trigger condition needs to be defined. Here, we use a rising edge trigger.
- `glitcher.set_pulseshaping(vinit=3.3)`: Instead of a simple voltage drop, the pulse-shaping mode allows defining a more complex glitch waveform. The pulse-shaping capabilities are initialized and the initial voltage of `3.3V` is stored for internal reference. 

**Note** that the initial voltage output of the Pulse Shaping Expansion Board cannot be controlled by software. Instead, the small potentiometer on the board must be used to set the desired voltage output. The voltage set by the `vinit` parameter is for internal reference only. Other voltages during pulse output are calculated from this parameter. Remember to calibrate the voltage output of the pulse shaping expansion board according to this [guide](#calibration).

To create a smooth glitch waveform, we define a time-voltage spline:

```python
tpoints = [  0,  20, 40,  60,  80]
vpoints = [3.3, 2.7,  0, 2.7, 3.3]
glitcher.arm_pulseshaping_from_spline(delay, tpoints, vpoints)
```

- `tpoints`: A list of time points (in nanoseconds) where voltage changes occur.
- `vpoints`: The corresponding voltage levels at each time point.
- `arm_pulseshaping_from_spline(delay, tpoints, vpoints)` configures the Pico Glitcher to apply a shaped glitch after a specified delay.

By following these steps, the Pico Glitcher is configured to apply a precise, smooth voltage glitch instead of a sharp transition, making it more effective in certain fault injection scenarios.

## Other examples
Here are a few examples on how to quickly generate different voltage traces with multiple pre-defined functions.
See `fault-injection-library/example/pico-glitcher-pulse-shaping.py` for the comlpete script.

- Pulse-shaping with a configuration similar to multiplexing (without interpolation):
```python
ps_config = [[length, 2.0], [length, 1.0], [length, 0.0], [length, 3.3]]
glitcher.arm_pulseshaping_from_config(delay, ps_config)
```




- A voltage trace defined from a lambda:
```python
ps_lambda = f"lambda t:2.0 if t<{length} else 1.0 if t<{2*length} else 0.0 if t<{3*length} else 3.0"
glitcher.arm_pulseshaping_from_lambda(delay, ps_lambda, 10*length)
```




- A pulse from a lambda; ramp down to `1.8V` than `GND` glitch:
```python
ps_lambda = f"lambda t:-1.0/({2*length})*t+3.0 if t<{2*length} else 2.0 if t<{4*length} else 0.0 if t<{5*length} else 3.0"
glitcher.arm_pulseshaping_from_lambda(delay, ps_lambda, 6*length)
```




- A voltage trace from a raw list:
```python
pulse = [-0x1fff] * 50 + [-0x0fff] * 50 + [-0x07ff] * 50 + [0x0000] * 50
glitcher.arm_pulseshaping_from_list(delay, pulse)
```



- Pulse from time-voltage coordinates, interpolated in between:
```python
xpoints = [0,   100, 200, 300, 400, 500, 515, 520]
ypoints = [3.0, 2.1, 2.0, 2.0, 1.7, 0.0, 2.0, 3.0]
glitcher.arm_pulseshaping_from_spline(delay, xpoints, ypoints)
```


## Plotting requested pulses in real time

To observe the generated voltage traces while they are generated, the function `Spline.interpolate_and_plot(xpoints, ypoints)` can be used:

```python
from findus.firmware.Spline import Spline
[...]

xpoints = [0,   100, 200, 300, 400, 500, 515, 520]
ypoints = [3.0, 2.1, 2.0, 2.0, 1.7, 0.0, 2.0, 3.0]
glitcher.arm_pulseshaping_from_spline(delay, xpoints, ypoints)
Spline.interpolate_and_plot(xpoints, ypoints)
```



Run the script `fault-injection-library/examples/pico-glitcher-pulse-shaping.py` with the following parameters:

```bash
python pico-glitcher-pulse-shaping.py --rpico /dev/tty.<rpi-tty-port> --delay 10 10 --length 100 100 --pulse-type 5
```

## Interactive PCHIP Editor

Alternatively, the interactive PCHIP (Piecewise Cubic Hermite Interpolating Polynomial) editor can be used to generate a voltage trace.
The PCHIP editor is a tool which enables you to drag and drop multiple points that define the voltage trace. Interpolation is used to generate the intermediate points.

Import the respective module and initialize the PCHIP editor with `InteractivePchipEditor()`:
```python
from findus.InteractivePchipEditor import InteractivePchipEditor
editor = InteractivePchipEditor()
```

The following commands open the editor and retrieve the points in real-time:
```python
editor.show(block=False)
xpoints, ypoints = editor.get_points()
glitcher.arm_pulseshaping_from_spline(delay, xpoints, ypoints)
```

Here are two examples of voltage traces generated by the PCHIP editor:






See `fault-injection-library/examples/pico-glitcher-pulse-shaping.py` for more details.
The above example can be executed by running:

```bash
python pico-glitcher-pulse-shaping.py --rpico /dev/tty.<rpi-tty-port> --delay 10 10 --length 100 100 --pulse-type 6
```

## Calibration

Since the gain of the amplifier of the pulse-shaping expansion board depends on a lot of things, the output of the expansion board has to be calibrated.

This can be done by executing the command-line tool `pulse-calibration` (should be installed with findus) and by measuring the voltage trace with an oscilloscope:

```bash
pulse-calibration --rpico /dev/tty.<rpi-tty-port>
```

To perform a calibration routine

- Connect `TRIGGER` and `RESET`.
- Turn gain potentiometer of Pulse Shaping Expansion board all the way to the left (lowest gain).
- Connect your oscilloscope to pulse output of the Pulse Shaping Expansion board and to `TRIGGER` for triggering.
- Observe pulse.
- Measure maximum and minimum voltage of the generated pulse (`vhigh` and `vlow`). Take note and abort execution.
- Execute this script again with the found values for `vhigh` and `vlow` and check if the pulse aligns with `GND`.
- Note that the found calibration values are stored on the Pico Glitcher persistently if this script is called with values for `vhigh` and `vlow`.

For example, to apply and store the calibration, execute:
```bash
pulse-calibration --rpico /dev/tty.<rpi-tty-port> --vhigh 1.5 --vlow -0.5
```

## Technical details

The waveform generator AD9102 from Analog devices was chosen and is used to generate arbitrary voltage profiles.
This chip is a high performance digital-to-analog converter (DAC) integrating on-chip pattern memory for complex waveform generation with a direct digital synthesizer (DDS).
The key features of the chip are:

- On-chip 4096 × 14-bit pattern memory
- 180 MSPS pattern generator
- SPI interface to connect to the Pico Glitcher v2



The following circuit is used for the Pico-Glitcher v2 expansion board to amplify the signals from the DDS:



The requirements to the power amplifier are as follows:

- High slew rate for clean and steep signals: >7000 V/μs.
- Wide bandwidth of up to 200MHz.
- High output current to supply the target with power: >±200 mA



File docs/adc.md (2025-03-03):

# Using the analog digital converter
The Pico Glitcher includes an ADC that allows you to capture and analyze voltage traces while performing fault injection attacks. This guide explains how to configure and use the ADC for glitch analysis.

## Test setup

The ADC input is connected to the glitch-out line. For the test setup, connect a small resistor (~10Ω) between `VTARGET` and `GLITCH`.



First, import the necessary module and initialize the glitcher:

```python
from findus.AnalogPlot import AnalogPlot

# initialization
glitcher = DerivedGlitcher()
glitcher.rising_edge_trigger()
```

- `DerivedGlitcher()` initializes the Pico Glitcher.
- `glitcher.rising_edge_trigger()` sets the trigger to activate on a rising edge of the `TRIGGER` signal, ensuring the ADC starts sampling when the trigger condition is met.

Next, configure the ADC:

```python
# plot the voltage trace while glitching
number_of_samples = 1024
sampling_freq = 450_000
glitcher.configure_adc(number_of_samples=number_of_samples, sampling_freq=sampling_freq)
plotter = AnalogPlot(number_of_samples=number_of_samples, sampling_freq=sampling_freq)
```

- `number_of_samples` defines how many ADC readings are taken per capture.
- `sampling_freq` sets the sampling frequency (450 kHz in this case).
- `glitcher.configure_adc(...)` configures the ADC with the given parameters.
- `AnalogPlot(...)` initializes a plotting tool to visualize the collected data.

## Sampling Process

The ADC starts sampling when the trigger condition is met. The following code demonstrates the main loop where glitches are applied, and the ADC captures the voltage trace:

In the glitch loop:
```python
while True:
    # arming and other stuff
    ...

    # arm the adc
    glitcher.arm_adc()
    # triggering and reading the targets response
    ...

    # plotting the analog samples
    samples = glitcher.get_adc_samples()
    plotter.update_curve(samples)
```
- The function `glitcher.arm_adc()` prepares the ADC to capture samples when triggered. This must be done before triggering a glitch to ensure the ADC triggers when the trigger condition is met.
- `glitcher.get_adc_samples()` retrieves the recorded ADC data.
- `plotter.update_curve(samples)` updates the visualization with the new samples, allowing you to analyze how the voltage changes during the glitching campaign.

## Example Usage

To execute an example script utilizing the ADC functionality with the Pico Glitcher, see `fault-injection-library/examples/pico-glitcher.py`. Run:

```bash
python pico-glitcher.py --rpico /dev/tty.usbmodem1101 --delay 1000000 1000000 --length 1000 1000
```

This script sets up the Pico Glitcher with a USB connection (`/dev/tty.usbmodem1101`), applies specific delay values, and defines glitch length parameters.
With this setup the voltage trace and, for example, where the glitch should be applied, can be observed with the ADC.



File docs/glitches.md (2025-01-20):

# Comparing different glitching modes

To carry out fault injection attacks, voltage glitching can be applied to the target in various ways.

## Crowbar glitching

Probably the most common and simplest method is so-called crowbar glitching, in which the supply voltage of the microcontroller is pulled to GND for a very short time, as described in section [overview](overview.md).
This method leads to voltage curves similar to the following:




This method is suitable for many targets and is used in particular when large capacitive loads (e.g. capacitors on the power rails) need to be discharged.
However, the crowbar method also has disadvantages. On the one hand, if the crowbar pulse is too long, the target is reset and no fault is usefully induced.
On the other hand, the crowbar pulses must be very precisely timed and very narrow, which poses certain challenges for the electronics used.

## Multiplexing

A second method of voltage glitching is the multiplexing method. This involves rapid switching back and forth between different supply voltages, which can also cause faults in the target. See section [multiplexing](multiplexing.md) for more details.
One advantage of the multiplexing method is that the microcontroller can be supplied with voltage by the same electronics that carry out the voltage glitching. On the other hand, the voltages that lead to a fault can be kept over a longer period of time, which reduces the chance of a hard reset of the target.




A disadvantage is the complex electronics required to switch quickly between different voltage levels.

## Pulse shaping
An even more advanced methode is the pulse shaping methode, first described [here](https://doi.org/10.13154/tches.v2019.i2.199-224).
The key idea here is to use a Digital Direct Synthesis (DDS) to generate an arbitrary pulse form that is amplified and applied to the target.
The advantages of this method are obvious: almost any voltage curve with any intermediate voltages can be defined and generated. The overshoots when switching the voltage through the crowbar transistors or with the multiplexing stage are also eliminated, which ensures a cleaner voltage curve.






The disadvantages of this method are that it requires complicated and high-frequency power electronics with very specialised components. See section [pulse-shaping](pulse_shaping.md) for more details.

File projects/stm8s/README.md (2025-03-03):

#

## Prerequisites

stm8flash

```bash
git clone https://github.com/vdudouyt/stm8flash.git
cd stm8flash
make
sudo make install
```

Small Device C Compiler:

```bash
brew install sdcc
```

stm8-bootloader

```bash
git clone https://github.com/MKesenheimer/stm8-bootloader.git
cd stm8-bootloader
make
make flash
```

## Commands to flash the target via stm8flash

Unlock the device (erases the flash):

```bash
stm8flash -c stlinkv2 -p stm8s003f3 -u
```

Write image to flash:

```bash
stm8flash -c stlinkv2 -p stm8s003f3 -w blink.bin
```

Read image from flash:

```bash
stm8flash -c stlinkv2 -p stm8s003f3 -r dump.bin
```

Set Read-Out Protection (ROP):

```bash
echo -ne '\xaa' > rop_enable.bin
stm8flash -c stlinkv2 -p stm8s003f3 -s opt -w rop_enable.bin
```

Read option bytes:

```bash
stm8flash -c stlinkv2 -p stm8s003f3 -s opt -r opt_bytes.bin && xxd opt_bytes.bin
```

## Commands to flash the target using the Makefile

Unlock the device (erases the flash):

```bash
make reset-opt
```

Write image to flash:

```bash
make flash
```

Read image from flash:

```bash
make dump-flash
```

Set Read-Out Protection (ROP):

```bash
make enable-rop
```

Read option bytes:

```bash
make dump-opt
```

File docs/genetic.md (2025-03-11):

# Genetic Algorithm

In some cases, finding the parameters of a successful glitch can be quite tedious.
Especially if the possible parameter space is large (see [multiplexing](multiplexing.md) and [pulse-shaping](pulse_shaping.md)).
Therefore, the search for a suitable parameter point must be done somewhat more intelligently than with a brute force approach.

In the case of `findus`, a genetic algorithm has been implemented that can be used to search for the optimum parameter points.

The use of this genetic algorithm will be briefly outlined below. For a detailed view into how to use this algorithm in the context of voltage glitching, see for example `projects/esp32v1.3`.

## Implementing a genetic search algorithm when glitching

Import the class `OptimizationController` into your project:

```python
from finds.GeneticAlgorithm import OptimizationController
```

Since the genetic algorithm needs to classify the outcome of each bin with a numerical value (the so-called `weight`), a classify-method with additional weight factors must be implemented.
These weights are fed into the genetic algorithm.
```python
def classify(self, response):
    if b'read-out protection enabled\r\n' in response:
        color, weight = 'G', 0
    elif b'' == response:
        color, weight = 'M', 0
    elif b'Error' in response:
        color, weight = 'M', 0
    elif b'Fatal exception' in response:
        color, weight = 'M', 0
    elif b'Timeout' in response:
        color, weight = 'Y', -1
    else:
        color, weight = 'R', 2
    return color, weight
```

After initializing the glitcher, the parameter space must be defined. This is done by defining the parameter space boundaries, and the corresponding divisions into bins:
```python
# Genetic Algorithm to search for the best performing bin
boundaries = [(s_delay, e_delay), (s_t1, e_t1), (s_length, e_length)]
divisions = [10, 10, 5]
opt = OptimizationController(parameter_boundaries=boundaries, parameter_divisions=divisions, number_of_individuals=10, length_of_genom=20, malus_factor_for_equal_bins
=1)
```

In the while-loop before the experiment is performed, the best performing bins can be monitored from time to time. The next parameter set is pulled with the command `opt.step()`. Also the glitch outcome must be classified and fed into the genetic algorithm again.
```python
# get the next parameter set
delay, t1, length = opt.step()
if experiment_id % 100 == 0:
    opt.print_best_performing_bins()

# perform arming, triggering, read response
[...]

# classify response
color, weight = glitcher.classify(response)

# add experiment to parameterspace of genetic algorithm
opt.add_experiment(weight, delay, t1, length)
```

If implemented correctly (and with a suitable configuration of the `OptimizationController`) you should expect clustering experiments around successful glitches. See the figure below for an example output of a glitching campaign.



Note that the implementation of the genetic algorithm is not specific to the Pico Glitcher and can therefore also be used by the ChipWhisperer Pro and Husky.

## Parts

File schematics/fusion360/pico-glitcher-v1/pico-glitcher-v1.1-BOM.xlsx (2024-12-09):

Comment | Designator | Footprint | JLCPCB Part#(optional)
10nF | C1 | 0603 | C307346
2.2uF | C2 | 0805 | C77081
100nF | C3, C4, C5, C6, C7, C9, C10 | 0603 | C105907
22uF Aluminum Electrolytic Capacitor | C8 | SMD | C178580
10kΩ | R1, R2, R5, R11 | 0603_R | C103199
1Ω | R3, R4 | 0603_R | C140111
150Ω | R6, R7, R8, R10 | 0603_R | C3016246
220Ω | R9 | 0603_R | C138284
4x 10kΩ 1206 Resistor Array | R12, R13, R14, R15 | 0603x4 | C396839
4x 100Ω 1206 Resistor Array | R16, R17, R18, R19 | 0603x4 | C396838
IRLML2502 | Q1 | SOT-23 | C5364308
SI4134DY-T1-GE3 | Q2 | SOP-8 | C142600
TPS79318 | Q3 | SOT-23-5 | C7102
TPS2041BDR | Q4 | SOIC-8 | C431481
SN74LVC8T245PWR | U1, U2 | TSSOP-24 | C27643
Test Point | TP_5V, TP_3V3, TP_1V8, TP_GND, TP_TRIGGER2, TP_GLITCH_EN, TP_RESET, TP_VTARGET | - | C5277086
LED red, 25mA | D1, D4, D5 | 0603 | C19171390
LED blue, 25mA | D2, D3 | 0603 | C2917173
SMD Slide Switch, SP3T (SSSS812201) | S1 | SMD | C160878
SMA Connector | X1, X2 | Plugin | C914559
1X1 Pin Header 2.54mm | X_ANALOG, X_HPGLITCH2, X_LPGLITCH2, X_TRIGGER1, X_GLITCH1, X_GLITCH0, X_TRIGGER0, X_GLITCH, X_VCC_EXTERN | Plugin,P=2.54mm | C7501259
2X1 Pin Header 2.54mm | JMP_VCC_INTERN | Plugin,P=2.54mm | C7501260
3X1 Pin Header 2.54mm | X_1V8, X_3V3, X_5V, X_GLITCH_EN, X_GND, X_RESET, X_TRIGGER2, X_VTARGET | Plugin,P=2.54mm | C7501261
8X2 Pin Header 2.54mm | X3 | Plugin,P=2.54mm | C68234
Tactile Switch | S_RST | SMD | C2845324
Raspberry Pi Pico | PICO | RPI_PICO | C7203002

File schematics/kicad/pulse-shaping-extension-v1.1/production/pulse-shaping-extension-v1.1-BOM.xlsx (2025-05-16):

Comment | Designator | Footprint | JLCPCB Part#(optional)
4.7kΩ | R1, R2, R3 | 0603_R | C23162
AD9102BCPZRL7 | U1 | LFCSP-32(5x5) | C653184
CO32D6-125.000-33GDTSTL | X1 | SMD3225-6P | C5119019
100Ω | R4 | 0603_R | C22775
100nF | C1, C2, C3, C4, C6, C8, C9, C11, C13, C15, C17, C21, C23, C27, C29, C30 | 0603 | C105907
6.8kΩ | R5, R7 | 0603_R | C23212
100pF | C5, C7, C10, C12, C14, C16, C18, C22, C24 | 0603 | C1635
1kΩ | R6 | 0603_R | C14676
150Ω | R8, R9, R10 | 0603_R | C3016246
LED red, 25mA | D1 | 0603 | C19171390
LED green, 25mA | D2 | 0603 | C19273151
LED blue, 25mA | D3 | 0603 | C19171394
1uF | C19, C20 | 0805 | C5422
MAX1853EXT+T | U5 | SOT-363-6 | C143384
560Ω | R11 | 0603_R | C23204
120Ω | R12 | 0603_R | C22787
DNP | C25, C26 | 0603
ADA4817-1ACPZ-R7 | U3 | LFCSP-8(3x3) | C514314
49.9Ω | R18, R21 | 0603_R | C23185
10Ω, 1W | R20 | 2512 | C16861
1kΩ | RV1 | TC33X | C719174
THS3091DDAR | U4 | SOIC-8-EP | C181226
2.2uF | C28, C31 | 0805 | C77081
10kΩ | R13, R14, R15, R16, R17 | 0603_R | C103199
499Ω | R19, R22 | 0603_R | C23065
1Ω, 1W | R23 | 2512 | C11254

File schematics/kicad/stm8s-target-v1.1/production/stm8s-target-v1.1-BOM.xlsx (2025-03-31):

Comment | Designator | Footprint | JLCPCB Part#(optional) | pre-ordered
USB-C Connector | J7 | SMD | C165948
5.1kΩ | R1, R2 | 0603_R | C23186
10uF | C1, C2 | 0805 | C1713
100nF | C3 | 0603 | C1590
AMS1117 | U1 | SOT-223 | C6186
CH340X | U2 | MSOP-10 | C3035748
10n | C4, C5 | 0603 | C1589
STM8S003F3U6TR | U3 | UFQFPN-20(3x3) | C35556
1N4148WS | D6, D7, D8 | SOD-323 | C2128
4.7kΩ | R8, R9 | 0603_R | C23162
Tactile Switch | S1 | SMD | C72443
100Ω | R12, | 0603_R | C22775
150Ω | R3, R4, R5, R6, R7 | 0603_R | C3016246
LED green, 25mA | D2 | 0603 | C19273151
LED red, 25mA | D1, D4 | 0603 | C19171390
LED blue, 25mA | D3, D5 | 0603 | C19171394
1uF | C6 | 0603 | C1592
4.7kΩ | R10 | 0603_R | C23162

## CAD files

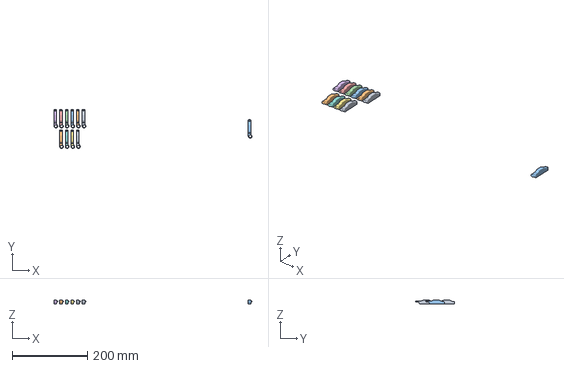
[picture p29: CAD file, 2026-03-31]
schematics/3d-models/expansion-board-spacer-v1.1.3mf
526.3 x 103.6 x 11.5 mm
expansion-board-spacer-v1.1.stl x 11

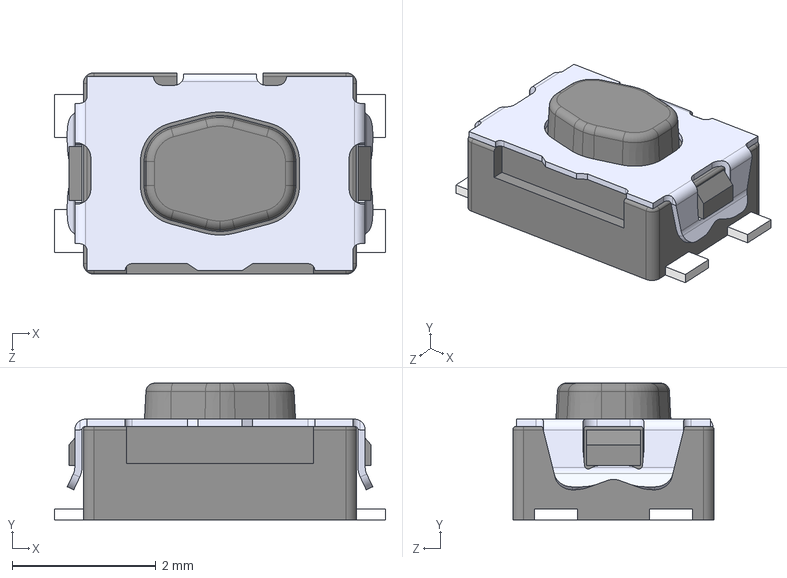
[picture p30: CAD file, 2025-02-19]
schematics/kicad/stm8s-target-v1.1/KMR221GLFS/KMR221GLFS.step
4.60 x 1.90 x 2.80 mm

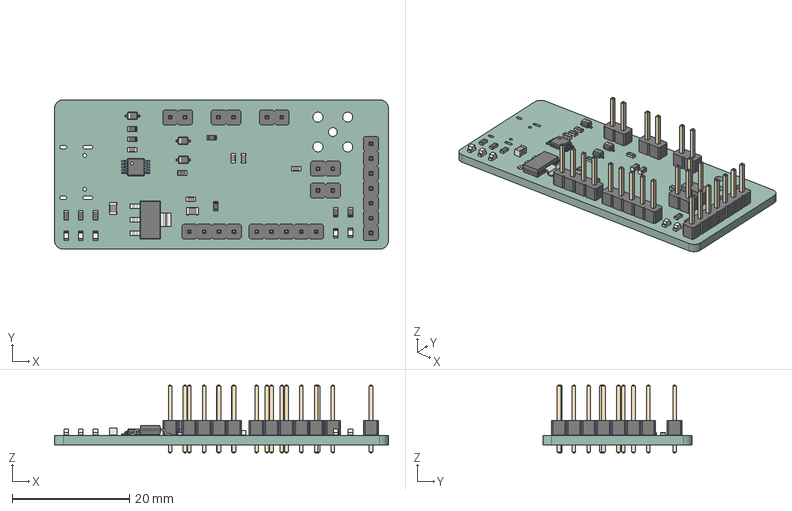
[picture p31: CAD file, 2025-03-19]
schematics/kicad/stm8s-target-v1.1/stm8s-target-v1.1.step
57.0 x 25.5 x 11.5 mm
C_0603_1608Metric x 5
R_0603_1608Metric x 10
C_0805_2012Metric x 2
PinHeader_1x04_P254mm_Vertical
LED_0603_1608Metric x 5
PinHeader_1x02_P254mm_Vertical x 5
PinHeader_1x07_P254mm_Vertical
D_SOD_323 x 3
MSOP_10_3x3mm_P05mm
PinHeader_1x05_P254mm_Vertical
SOT_223
stm8s-target-v1_PCB

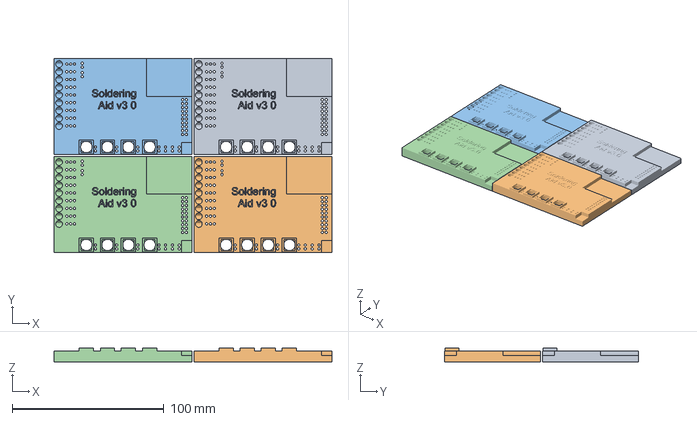
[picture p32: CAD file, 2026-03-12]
schematics/3d-models/soldering-aid-v3.0.3mf
183.0 x 128.0 x 9.50 mm
soldering-aid-v3.0.stl x 4

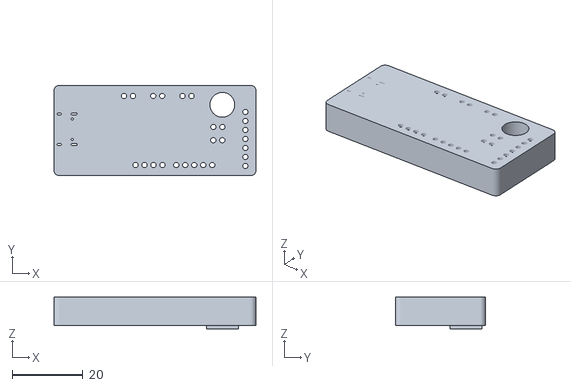
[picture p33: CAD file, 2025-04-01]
schematics/3d-models/target-board-soldering-aid-v1.1.stl
57.0 x 25.5 x 9.00

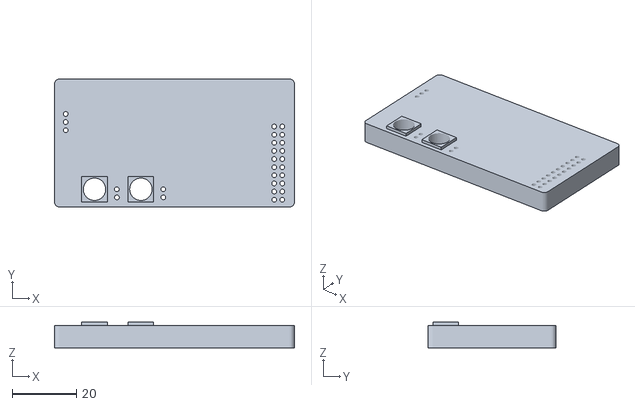
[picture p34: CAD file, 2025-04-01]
schematics/3d-models/pulse-shaping-soldering-aid-v1.1.stl
75.0 x 40.0 x 8.00

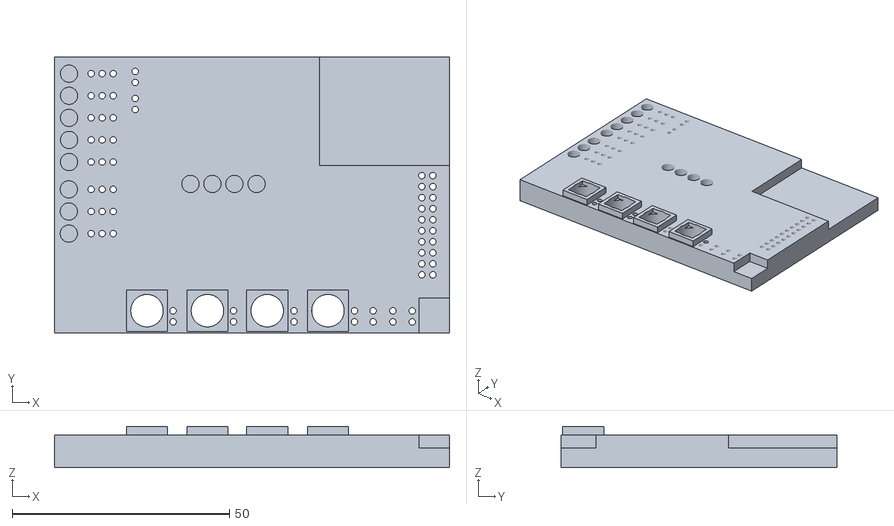
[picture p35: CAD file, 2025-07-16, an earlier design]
schematics/3d-models/soldering-aid-v2.4.stl
91.0 x 63.5 x 9.50

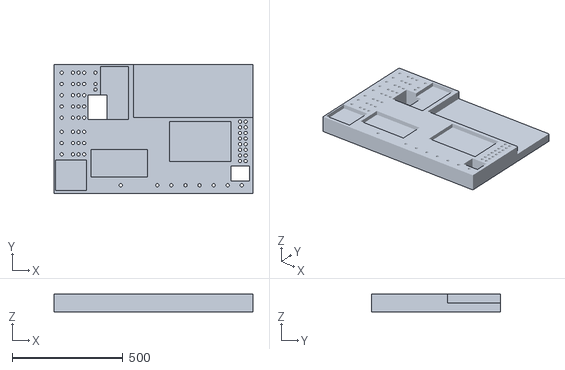
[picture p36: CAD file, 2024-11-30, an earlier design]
schematics/3d-models/soldering-aid-v1.1.stl
898.2 x 584.1 x 80.0

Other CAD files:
schematics/3d-models/expansion-board-spacer-v1.1.stl
schematics/3d-models/soldering-aid-v3.0.stl

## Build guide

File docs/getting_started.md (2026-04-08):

# Getting Started

This guide should quickly prepare you to use the Pico Glitcher and the findus library.

## TL;DR

If you are in a hurry and just want to execute an example script as fast as possible, follow these commands:

```bash
cd ~
mkdir my-fi-project && cd my-fi-project
python3 -m venv .venv && source .venv/bin/activate
pip install findus
update-fw --port /dev/<rpi-tty-port> --version <pico-glitcher-version>
wget https://raw.githubusercontent.com/MKesenheimer/fault-injection-library/refs/heads/master/examples/pico-glitcher.py
python pico-glitcher.py --rpico /dev/ttyACM0 --delay 0 0 --length 100 100
```

Replace `<pico-glitcher-version>` with the hardware version you have. For example `v1`, `v2.1`, `v2.2`, `v2.3`, `v2.4`, `v2.5` or `v3.0`, and so on.

Note that the paths and tty names may be different in your case.

If these commands fail, see below for a detailed installation guide.

## Installing findus

If you just want to get started quickly and don't want to bother with the source code of findus, findus can be installed via pip. The findus library can be found on [https://pypi.org/project/findus/](https://pypi.org/project/findus/) and can be installed locally in a Python environment using the following command:

```bash
mkdir my-fi-project && cd my-fi-project
python -m venv .venv
source .venv/bin/activate
pip install findus
```

Install the optional RD6006 python bindings if you have a RK6006 or a RD6006 power supply from Riden:

```bash
pip install rd6006
```

This external power supply can be used optionally to supply the target with power. It is possible to control the RD6006 power supply via the findus library using the power supply's USB interface. Suitable functions for this are implemented in the findus library.
Don't worry if you don't have this power supply. The Pico Glitcher can also supply the target with voltage.

Now you can use findus:

```bash
python
>>> from findus import Database, PicoGlitcher
...
```

The next step is to copy an existing glitching script and to adapt it to your needs.
Start by copying [https://github.com/MKesenheimer/fault-injection-library/blob/master/example/pico-glitcher.py](https://github.com/MKesenheimer/fault-injection-library/blob/master/example/pico-glitcher.py). More example projects are located at [https://github.com/MKesenheimer/fault-injection-library/tree/master/projects](https://github.com/MKesenheimer/fault-injection-library/tree/master/projects).

See [examples](examples.md) for more information how to use findus and the Pico Glitcher.

## Updating the Pico Glitcher firmware

Your Pico Glitcher should come with the latest firmware already installed. If not, follow the following procedure to update the software on the Pico Glitcher.

### Step 1: MicroPython firmware

Download the MicroPython firmware from [https://micropython.org/download/RPI_PICO/](https://micropython.org/download/RPI_PICO/). Unplug the Pico Glitcher from your computer, press and hold the `BOOTSEL` button on the Raspberry Pi Pico and connect it back to your computer. The Raspberry Pi Pico should come up as a flash-storage device. Copy the MicroPython firmware (`RPI_PICO-xxxxxxxx-vx.xx.x.uf2`) to this drive and wait until the Raspberry Pi Pico disconnects automatically.
More information about setting up the Raspberry Pi Pico can be found [here](https://projects.raspberrypi.org/en/projects/getting-started-with-the-pico).

On Linux, your user must have permissions to connect to the Pico Glitchers tty port. If not already done, add your user to the `dialout` group and restart your computer:

```bash
sudo usermod -aG dialout <username>
```

### Step 2: Install the findus library

Skip this step, if you already installed findus previously (see [here](#installing-findus)).

If you want to make sure that the libraries to be installed do not collide with your local Python environment, use a virtual environment.
Set it up by generating a new virtual environment and by activating it:

```bash
python -m venv .venv
source .venv/bin/activate
```

After these steps we have to install findus (aka fault-injection-library).
Make sure to have pip [installed](https://docs.python.org/3/library/ensurepip.html).

```bash
pip install findus
```

### Step 3: Update the Pico Glitcher firmware

If everything went well, you should have the `update-fw` script available for execution in your command-line environment.
Connect the Pico Glitcher to your computer and check which serial device comes up:

```bash
ls /dev/tty*
```

Take note of the device path. Next upload the Pico Glitcher firmware and the specific configuration for your Pico Glitcher hardware version via the following command:

```bash
update-fw --port /dev/<rpi-tty-port> --version <pico-glitcher-version>
```

Your Pico Glitcher should now be ready to perform fault-injection attacks.

## Installing from source

If you want to get involved in the development or to have access to all the resources of this repository, clone the findus library:

```bash
git clone --depth 1 --recurse-submodules \ 
    https://github.com/MKesenheimer/fault-injection-library.git
```

Install `findus` and the optional `rd6006` library:

```bash
cd fault-injection-library
pip install .
cd rd6006
pip install .
update-fw --port /dev/<rpi-tty-port> --version <pico-glitcher-version>
```

The next step is to copy an existing glitching script and to adapt it to your needs.
Start by copying `fault-injection-library/example/pico-glitcher.py`. More example projects are located at `fault-injection-library/projects`.

See [examples](examples.md) for more information how to use findus and the Pico Glitcher.

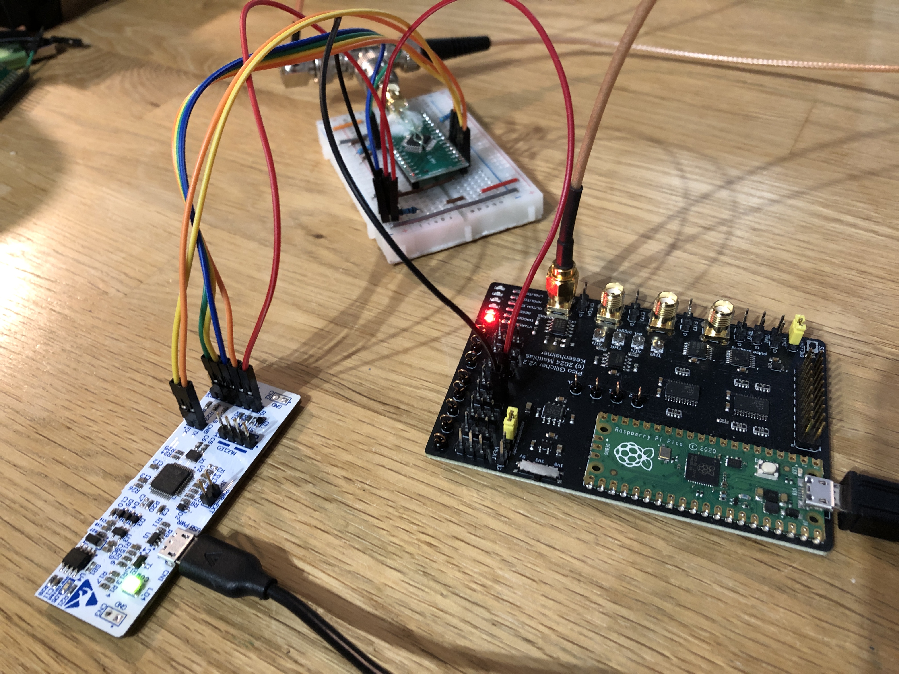
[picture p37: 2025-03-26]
projects/stm32l422/images/setup-3.JPG

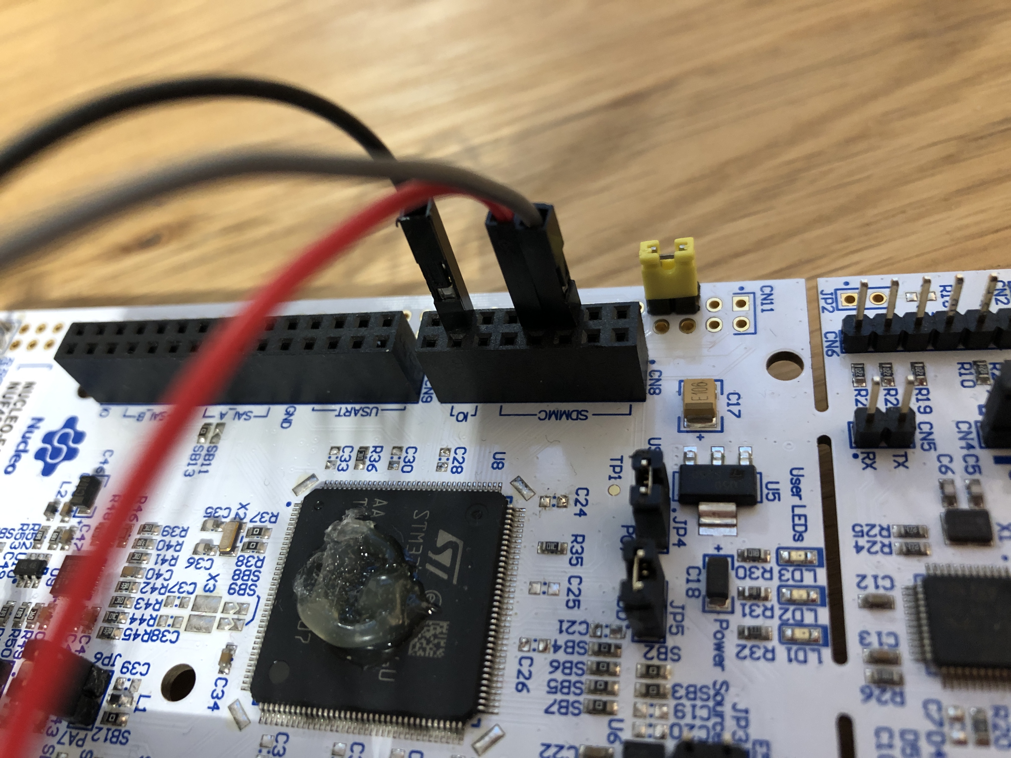
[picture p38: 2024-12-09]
projects/stm32f42x/images/setup-1.JPG

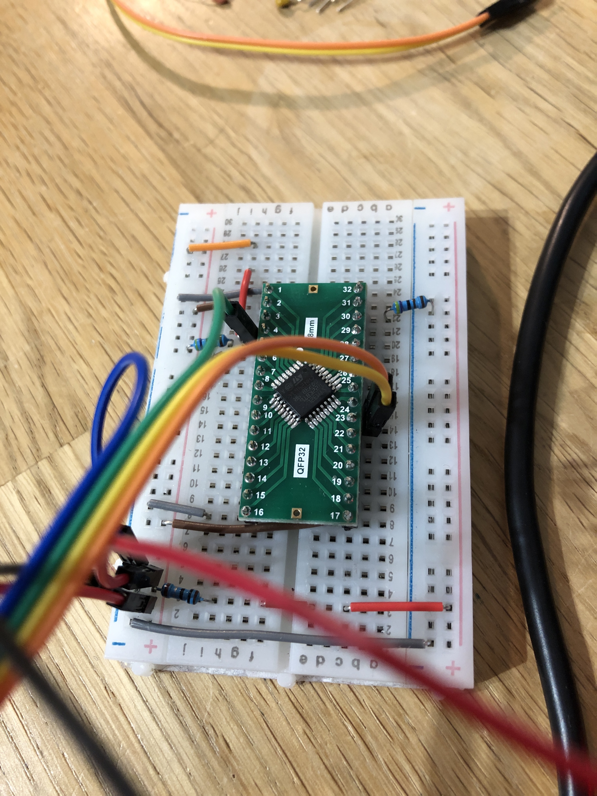
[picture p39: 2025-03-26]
projects/stm32l422/images/setup-1.JPG

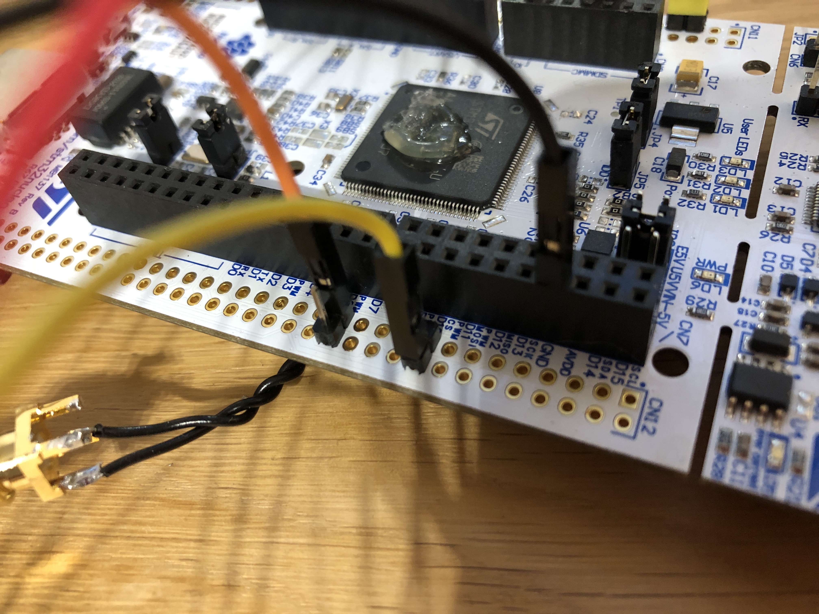
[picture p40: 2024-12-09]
projects/stm32f42x/images/setup-2.JPG

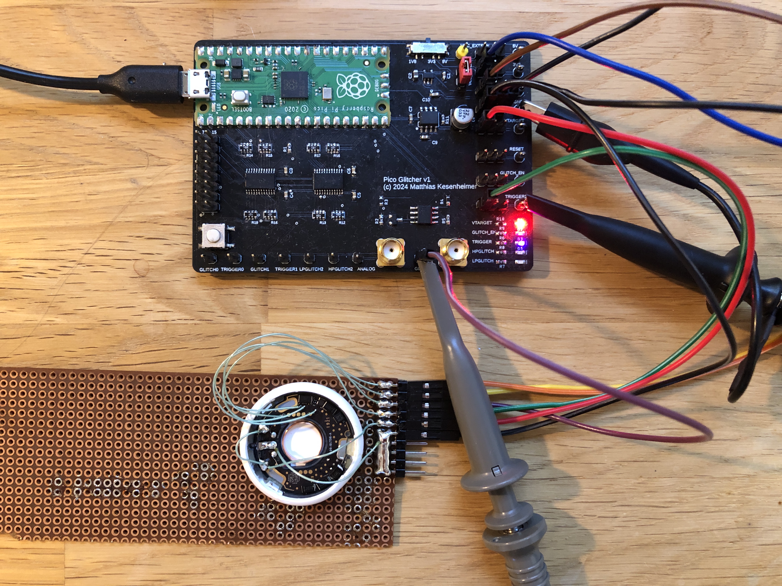
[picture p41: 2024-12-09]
projects/nrf52832/images/airtag/setup-1.JPG

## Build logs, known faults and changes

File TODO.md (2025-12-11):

# TODOs

* implement a "findus-launcher" that handles all the common things, like command line parsing, database setup and so on. The user should only provide the handles for classification, and the contents of the glitching loop.

* AnalogPlot für das Skript stm8-readmemory.py verwenden, um den Zeitraum für den Glitch zu messen.
* Bild von AnalogPlot für die Glitchpositionierung beim STM8s Glitchen.
* use consistent time units for all functions.
* implement shell completion with 'click'
* check minimal python version before installation

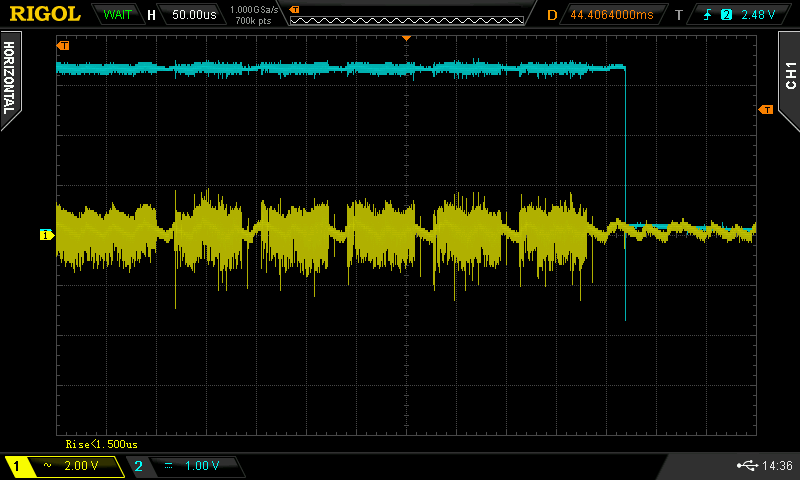
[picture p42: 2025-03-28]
projects/stm32l422/images/debug-unlock-C.png

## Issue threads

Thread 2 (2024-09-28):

[question] porting to kicad ?

FabienTregan, 2024-09-28:
Hi,

  I wanted to try a few modifications on the board*, but the files are for Fusion360 for which I do not (and don't plan to) own a license. Would you be interested in porting the project to Kicad ? (I think I can do the job, but have no interest in maintaining a Kicad fork if you prefer Fusion).

* : mainly the possibility to have different voltages for power and glitching, since the CC2510 I play with gives better results when glitching from the 1.8V regulation pins but still need to be power-cycled through the 3V3 pin and use 3V3 for communicating on the debug interface.

MKesenheimer, 2024-09-29:
Hey Fabien,
if you are willing to do the work, feel free to do so. I am happy for contributions. I do not use Kicad currently, but if you can port the project to this program, I am open to a change since I am not that happy with Fusion360 regarding to PCB prototyping. Maybe this would be the perfect time to switch gears.
To sum up: Thank you for your kind offer to port the project. I would like to maintain the project in Kicad after you ported it ;)

FabienTregan, 2024-09-29:
I could not open the `.fsch` and `.fbrd` files (eagle crashes on my two computers under linux mint). If you have an option in fusion to export the file to a more standard format (eagle 'old' .sch and .brd ?), I could start from your file instead of redoing from scratch. If you can, just attach the files to this issue and I'll give it a try.

MKesenheimer, 2024-09-29:
I added the files `*.brd` and `*.sch` to `schematics`. Let me know if these files formats work.

FabienTregan, 2024-09-29:
After a few crashes they seem to be imported fine ! I need to check all the biding between components in schematic and PCB, but that will be way easyer than redoing everything from scratch, thanks !

FabienTregan, 2024-09-29:
(I'll try sending a first version during next week)

MKesenheimer, 2024-09-29:
That's good news. Looking forward to your PR.

FabienTregan, 2024-09-30:
On component is present twice on the schematic with the same reference (because `x-glitch` is automatically numbered as `x-glitch0` which already existed) so I renamed this way. Can you confirm it is correct ?
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

MKesenheimer, 2024-09-30:
Ah, I see. Yeah, that should be fine I guess.

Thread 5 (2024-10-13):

[discussion] initiating user documentation ?

FabienTregan, 2024-10-13:
Hi,

 would this be the proper time to initiate user documentation ? as a beginner trying to test the project, here are the chapter which would really have helped me getting into the code / project:

- basic architecture (what is running on computer side, on the rp pico, ...)
- pins usage (e.g. difference between `lpglitch`, `hpglitch`, `x_glitch0`, `x_glitch`,  ... far all pins)
- how to run the samples (which firmware / python code to send to the RP Pico, what to run on computer side, ...)

MKesenheimer, 2024-10-13:
Yes, a full documentation is still missing and I am aware of this. Do you have any recommendations for a documentation framework?

FabienTregan, 2024-10-13:
Since I like Rust, I use mdbook as a basic static website generator from markdown files. Output with default settings looks like this : https://tregan.fr/NoCV/

The "extra" work is minimal (just provide a markdown file for the table of content on the left), and the files can probably be reused in lot of static generators that takes markdown as an imput.

There is an extension to generate diagrams from plantuml, which is a bit less common but allow text bases, human readable / maintainable diagrams (great for git + usable without installing anything). Plantuml looks like this (see example for sequence diagram : https://plantuml.com/sequence-diagram )

I have gitlab CI script to generate the static file and upload to my webserver when I push, this is probably easy to do and already documented for github actions.

I don't have any suggestion to document the python code / api since I've only done minimal work with python.

FabienTregan, 2024-10-13:
There is this indication that I don't know where to position (it was over a lot of things)
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

MKesenheimer, 2024-10-18:
Documentation of the first classes and methods is available under [https://fault-injection-library.readthedocs.io/](https://fault-injection-library.readthedocs.io/).
I leave this issue open until the documentation is in a "complete-enough" state.

MKesenheimer, 2024-11-01:
Documentation of important functions and classes finished. This still needs to be improved or updated in some places, but documentation is generally complete.

Closed 2024-11-01.

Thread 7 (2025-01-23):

Support for double glitches

MKesenheimer, 2025-01-23:
Sometimes it is necessary to glitch the target multiple times, i.e. if checks are performed more than once.

Implement methods in the Pico Glitcher firmware that allow to glitch multiple times, for example by providing multiple trigger conditions and multiple delay and length parameters.

MKesenheimer, 2025-03-06:
The possibility to insert multiple glitch with multiple length would be useful.

MKesenheimer, 2025-03-28:
Done with #13.

Closed 2025-03-28.

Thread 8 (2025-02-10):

Latest micropython firmware (v1.24.1 (2024-11-29) .uf2) does not work

MKesenheimer, 2025-02-10:
When updating to the latest micropython firmware ([v1.24.1 (2024-11-29) .uf2](https://micropython.org/resources/firmware/RPI_PICO-20241129-v1.24.1.uf2), the ADC does not trigger anymore.

Latest working micropython firmware is [v1.23.0 (2024-06-02) .uf2](https://micropython.org/resources/firmware/RPI_PICO-20240602-v1.23.0.uf2) / [[Release notes]](https://github.com/micropython/micropython/releases/tag/v1.23.0).

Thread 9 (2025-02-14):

Hi where can I find pico glitcher v2

gunbileg2010, 2025-02-14:
Hi where can I find pico glitcher v2

MKesenheimer, 2025-02-14:
You mean the hardware?
Here: [https://www.tindie.com/products/faulty-hardware/picoglitcher-v21/](https://www.tindie.com/products/faulty-hardware/picoglitcher-v21/)

gunbileg2010, 2025-02-14:
Yes can I have the schematic or brd

MKesenheimer, 2025-02-14:
The schematic and board for v2 is currently not public. This may change in the future, but there are no specific plans.

Closed 2025-02-14.

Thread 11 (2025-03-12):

arm should not release target

inode-, 2025-03-12:
The arm code release the target, but in this way if the reset is also the trigger the picoglitcher is not able to identify the trigger due the target start faster than the initial setup.

https://github.com/MKesenheimer/fault-injection-library/blob/b5ec99b4813cef692553d9ec373e20b5441a9b4e/findus/firmware/PicoGlitcher.py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

MKesenheimer, 2025-03-12:
Do you use the arming and blocking functions as in the examples?

You should do it similar to this:
```
            self.glitcher.arm(delay, length)

            # power cycle target
            #self.glitcher.power_cycle_target(0.1)

            # reset target
            time.sleep(0.01)
            self.glitcher.reset(0.01)
``

inode-, 2025-03-12:
The target that I was working on continues to reboot due to secure boot failing. In this case if the arm is executed before the reset pin is executed it will glitch in a non controlled position because it will not match the reset send on the code.

I don't see why the ARM should also handle releasing the reset. The way I see it, the code and the timing of the reset release should be controlled by the user to make it more versatile.

MKesenheimer, 2025-03-12:
You can also have a look into the dead time trigger suppression feature of the Pico Glitcher: https://fault-injection-library.readthedocs.io/en/latest/findus/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

Maybe this would also help in your case.

lfldp1, 2025-03-14:
> The target that I was working on continues to reboot due to secure boot failing. In this case if the arm is executed before the reset pin is executed it will glitch in a non controlled position because it will not match the reset send on the code.
>
> I don't see why the ARM should also handle releasing the reset. The way I see it, the code and the timing of the reset release should be controlled by the user to make it more versatile.

Why do you complicate everything in a similarly complicated way as chipwhisperers api work? For the same target with secure boot I always use a simple method: Resets the processor via a glitcher then generates a glitch via the received signal from the reset line, the arm function is completely unnecessary here.

lfldp1, 2025-03-14:
> The target that I was working on continues to reboot due to secure boot failing

The target that I was working on continues to reboot due to secure boot failing - this condition shouldn't interest you. Do as I wrote above and a correctly made glitch will be confirmed by a diode lighting up after verifying the signature, if you have one, or a similar event. You can lead the diode control signal to pico-glitcher and react accordingly.

inode-, 2025-03-15:
>
> Why do you complicate everything in a similarly complicated way as chipwhisperers api work? For the same target with secure boot I always use a simple method: Resets the processor via a glitcher then generates a glitch via the received signal from the reset line, the arm function is completely unnecessary here.

The arm function should be called otherwise the glitch will not be generated. In general, as wrote before, I prefere to have a user control to when the release reset is called and not have an internal function (in this case the arm() ) that release the reset automatically.

lfldp1, 2025-03-15:
> > Why do you complicate everything in a similarly complicated way as chipwhisperers api work? For the same target with secure boot I always use a simple method: Resets the processor via a glitcher then generates a glitch via the received signal from the reset line, the arm function is completely unnecessary here.
>
> The arm function should be called otherwise the glitch will not be generated. In general, as wrote before, I prefere to have a user control to when the release reset is called and not have an internal function (in this case the arm() ) that release the reset automatically.

I still don't understand what you mean. The points I listed are used to glitch secure boot. This is the simplest solution and also prevents the processor from hanging during glitching. The signal sent by the processor during reset is irrelevant in this method.

MKesenheimer, 2025-03-15:
Yeah, I am wondering if we talk past each other, too.
Try the following:

- connect the reset line of your device under test (DUT) with `RESET` of the PicoGlitcher
- additionally connect `RESET` with the `TRIGGER` input of the PicoGlitcher
- supply power to the device via `VTARGET` and `GND`

use
```
from findus import PicoGlitcher

glitcher = PicoGlitcher()
glitcher.init(port='/dev/ttyACM0')
glitcher.set_lpglitch()
glitcher.reset_target()

delay = 0
length = 100

glitcher.arm(delay, length)
glitcher.reset(0.01)
glitcher.block(timeout=1)
```

as a minimal example to start with.

Explanation:
- the `PicoGlitcher` is initialized and crowbar glitching is activated
- `glitcher.reset_target()`: the `RESET` line is pulled to GND and the DUT is reset. The DUT should not boot with this command executed. It should stay so until `glitcher.reset()` is called.
-`glitcher.arm()`: the Pico Glitcher is armed (the internal statemachines are configured to wait for the trigger signal)
- `glitcher.reset()`: the `RESET` line is pulled to GND, the Pico Glitcher waits for `0.01` seconds, than the `VTARGET` is applied to the `RESET` line. This will start the device and immediately trigger the PicoGlitcher
- a glitch is emitted after the specified delay (in nanoseconds)
- `glitcher.block()` is not necessary, however you can check with this command if triggering was successful

MKesenheimer, 2025-03-16:
Removed `release_reset()` from `arm()` in `findus/firmware/PicoGlitcher.py` in the latest release, as it was unnecessary. This does not break anything.

Closed since original question should be resolved.

Closed 2025-03-16.

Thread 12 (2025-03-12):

reset_target into the PicoGlitcher object is missing

inode-, 2025-03-12:
In the PicoGlitcher code the "release_reset" is implemented, but the "reset_target()" is not.

https://github.com/MKesenheimer/fault-injection-library/blob/b5ec99b4813cef692553d9ec373e20b5441a9b4e/findus/findus.py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

it can be accessed by using the "self.pico_glitcher" internal object, but it's not the best.

The idea is to:

```
reset_target()
arm()
sleep()
release_reset()
```

MKesenheimer, 2025-03-12:
use the function `reset()` instead. That should be exactly what you want.

MKesenheimer, 2025-03-12:
https://fault-injection-library.readthedocs.io/en/latest/picoglitcher/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

inode-, 2025-03-12:
hmm, if I'm not wrong the reset it blocking: https://github.com/MKesenheimer/fault-injection-library/blob/b5ec99b4813cef692553d9ec373e20b5441a9b4e/findus/firmware/PicoGlitcher.py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

I need to arm before the release of the reset.

MKesenheimer, 2025-03-12:
Yes, reset is blocking.

Why does

```
self.glitcher.arm(delay, length)
self.glitcher.reset(0.01)
```

not work in your case?

This arms the Pico Glitcher (waits for the trigger line to rise), and pulls the reset line down for 0.01 seconds. Afterwards the reset line rises and the Pico Glitcher triggers on the rising edge of the reset line.
You must also connect the reset with the trigger line.

inode-, 2025-03-14:
It was related to: https://github.com/MKesenheimer/fault-injection-library/issues/16

MKesenheimer, 2025-03-14:
Is this still a problem? Or does the use of dead_time and the external trigger inputs EXT1 and EXT2 fix this issue?

MKesenheimer, 2025-03-16:
Replaced `reset` by `reset_target` in the latest release. This should be easier to understand what this function does. The function `reset` is still left in for downward compatibility. You can still use `reset` to reset your target.

Also the original function `reset_target` was replaced by `initiate_reset` for consistency.

Closed since the original question seems to be resolved. If not, please re-open.

Closed 2025-03-16.

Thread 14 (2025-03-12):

Errors in python scripts

lfldp1, 2025-03-12:
Unfortunately, there is no way to run the example script correctly. The command .\python pico-glitcher.py --rpico COM7 --delay 1000 1000 --length 100 100 returns the following errors:
 .\python pico-glitcher.py --rpico COM7 --delay 1000 1000 --length 100 100
Traceback (most recent call last):
  File "D:\INSTALKI\ANACONDA\pico-glitcher.py", line 162, in <module>
    main = Main(args)
           ^^^^^^^^^^
  File "D:\INSTALKI\ANACONDA\pico-glitcher.py", line 51, in __init__
    self.glitcher.init(port=args.rpico, ext_power=args.power, ext_power_voltage=3.3)
  File "C:\Users\dom\AppData\Roaming\Python\Python312\site-packages\findus\findus.py", line 672, in init
    self.pico_glitcher.init(port, 'PicoGlitcher')
  File "C:\Users\dom\AppData\Roaming\Python\Python312\site-packages\findus\findus.py", line 379, in init
    self.pyb.exec(f'import {micropy_script}')
  File "C:\Users\dom\AppData\Roaming\Python\Python312\site-packages\findus\pyboard.py", line 498, in exec_
    raise PyboardError("exception", ret, ret_err)
findus.pyboard.PyboardError: ('exception', b'', b'Traceback (most recent call last):\r\n  File "<stdin>", line 1, in <module>\r\n  File "PicoGlitcher.py", line 139, in <module>\r\nNameError: name \'MUX0_PIO_INIT\' isn\'t defined\r\n')
[+] Terminating gracefully.

PICO GLITCHER V1 has been reprogrammed with the v1 config file so it should work

MKesenheimer, 2025-03-12:
Hey, sorry for that. I will try to reproduce the error and fix it, if possible.

lfldp1, 2025-03-12:
> Hey, sorry for that. I will try to reproduce the error and fix it, if possible.

Ok thank you very much master :)

MKesenheimer, 2025-03-12:
Fixed in Version 1.3.1.

to update:
```
mkdir my-fi-project && cd my-fi-project
python -m venv .venv && source .venv/bin/activate
pip install findus==1.3.1
cd .venv/lib/python3.xy/site-packages/findus/firmware
upload --port /dev/tty.<rpi-tty-port> --files AD910X.py FastADC.py PicoGlitcher.py PulseGenerator.py Spline.py <config-path>/config.json
```

MKesenheimer, 2025-03-12:
Hmm, do you have the correct micropython firmware installed?

https://micropython.org/resources/firmware/RPI_PICO-20240602-v1.23.0.uf2

Also, I never tried the software on Windows. Do you have the possibility to execute on Linux, for example via an virtual machine?

lfldp1, 2025-03-12:
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

Yes 1.23.0

lfldp1, 2025-03-12:
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

!C:\Users\dom\AppData\Roaming\Python\Python312\Scripts\upload --port COM7 --files AD910X.py FastADC.py PicoGlitcher.py PulseGenerator.py Spline.py C:\Users\dom\AppData\Roaming\Python\Python312\site-packages\findus\firmware\config_v1\config.json

give this reprogramming result:

/AD910X.py
/FastADC.py
/PicoGlitcher.py
/PulseGenerator.py
/Spline.py
/config.json
/main.py
[+] Resetting Raspberry Pi Pico...
[+] Deleting AD910X.py...
[+] Uploading AD910X.py...
[+] Deleting FastADC.py...
[+] Uploading FastADC.py...
[+] Deleting PicoGlitcher.py...
[+] Uploading PicoGlitcher.py...
[+] Deleting PulseGenerator.py...
[+] Uploading PulseGenerator.py...
[+] Deleting Spline.py...
[+] Uploading Spline.py...
[+] Deleting config.json...
[+] Uploading C:\Users\dom\AppData\Roaming\Python\Python312\site-packages\findus\firmware\config_v1\config.json...
[+] Resetting Raspberry Pi Pico...
[+] Content of the Raspberry Pi Pico: but nothing received after : is this normall ?

lfldp1, 2025-03-12:
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

yes I use windows. Tomorrow I will try to run it all on linux. By the way I will ask if these scripts are suitable to run in jupyter notebook?

MKesenheimer, 2025-03-12:
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

No, this is not normal. You see the content of your PicoGlitcher at the start of the output, which is the other way around. You can try uploading the files manually with Thonny (https://thonny.org).

lfldp1, 2025-03-12:
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

Ok

lfldp1, 2025-03-12:
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

After installing everything on ubuntu, these errors occur:

(.venv) root@lukasz-virtual-machine:~/my-fi-project/.venv/lib/python3.10/site-packages/findus/firmware# upload --port /dev/ttyACM0 --files AD910X.py FastADC.py PicoGlitcher.py PulseGenerator.py Spline.py .venv/lib/python3.10/site-packages/findus/firmware/config_v1/config.json
[+] Resetting Raspberry Pi Pico...on
[+] Uploading AD910X.py...
[+] Uploading FastADC.py...
[+] Uploading PicoGlitcher.py...
[+] Uploading PulseGenerator.py...
[+] Uploading Spline.py...
[+] Deleting config.json...
[+] Uploading .venv/lib/python3.10/site-packages/findus/firmware/config_v1/config.json...

[+] Resetting Raspberry Pi Pico...
[+] Content of the Raspberry Pi Pico:

/AD910X.py
/FastADC.py
/PicoGlitcher.py
/PulseGenerator.py
/Spline.py
/config.json

(.venv) root@lukasz-virtual-machine:~/my-fi-project/.venv/lib/python3.10/site-packages/findus/firmware# ls
AD910X.py  config_v1  config_v2  decorators.py  FastADC.py  fault-injection-library.git  __init__.py  PicoGlitcher.py  PulseGenerator.py  __pycache__  Spline.py
(.venv) root@lukasz-virtual-machine:~/my-fi-project/.venv/lib/python3.10/site-packages/findus/firmware# wget https://github.com/MKesenheimer/fault-injection-library/archive/refs/tags/1.3.1.tar.gz
--2025-03-12 23:02:12--  https://github.com/MKesenheimer/fault-injection-library/archive/refs/tags/1.3.1.tar.gz
Resolving github.com (github.com)... 140.82.121.3
Connecting to github.com (github.com)|140.82.121.3|:443... connected.
HTTP request sent, awaiting response... 302 Found
Location: https://codeload.github.com/MKesenheimer/fault-injection-library/tar.gz/refs/tags/1.3.1 [following]
--2025-03-12 23:02:12--  https://codeload.github.com/MKesenheimer/fault-injection-library/tar.gz/refs/tags/1.3.1
Resolving codeload.github.com (codeload.github.com)... 140.82.121.9
Connecting to codeload.github.com (codeload.github.com)|140.82.121.9|:443... connected.
HTTP request sent, awaiting response... 200 OK
Length: unspecified [application/x-gzip]
Saving to: ‘1.3.1.tar.gz’

1.3.1.tar.gz                                           [                     <=>                                                                                         ]  95,05M  22,9MB/s    in 4,1s

2025-03-12 23:02:17 (23,0 MB/s) - ‘1.3.1.tar.gz’ saved [99668465]

(.venv) root@lukasz-virtual-machine:~/my-fi-project/.venv/lib/python3.10/site-packages/findus/firmware# tar -xvf 1.3.1.tar.gz
fault-injection-library-1.3.1/
DID UNPACKED ALL FILES.......

(.venv) root@lukasz-virtual-machine:~/my-fi-project/.venv/lib/python3.10/site-packages/findus/firmware# ls
1.3.1.tar.gz  config_v1  decorators.py  fault-injection-library-1.3.1  __init__.py      PulseGenerator.py  Spline.py
AD910X.py     config_v2  FastADC.py     fault-injection-library.git    PicoGlitcher.py  __pycache__
(.venv) root@lukasz-virtual-machine:~/my-fi-project/.venv/lib/python3.10/site-packages/findus/firmware# cd fault-injection-library-1.3.1
(.venv) root@lukasz-virtual-machine:~/my-fi-project/.venv/lib/python3.10/site-packages/findus/firmware/fault-injection-library-1.3.1# ls
docs  examples  findus  LICENSE  mkdocs.yml  projects  pyproject.toml  README.md  requirements.txt  schematics  TODO.md
(.venv) root@lukasz-virtual-machine:~/my-fi-project/.venv/lib/python3.10/site-packages/findus/firmware/fault-injection-library-1.3.1# cd examples
(.venv) root@lukasz-virtual-machine:~/my-fi-project/.venv/lib/python3.10/site-packages/findus/firmware/fault-injection-library-1.3.1/examples# ls
CMD                            pico-glitcher-multiplexing-optimization.py  pico-glitcher-pulse-shaping-optimization.py  pico-glitcher.py               pro-glitcher.py
pico-glitcher-edge-counter.py  pico-glitcher-multiplexing.py               pico-glitcher-pulse-shaping.py               pico-glitcher-uart-trigger.py
(.venv) root@lukasz-virtual-machine:~/my-fi-project/.venv/lib/python3.10/site-packages/findus/firmware/fault-injection-library-1.3.1/examples# python3 pico-glitcher.py --rpico /dev/ttyACM0 --delay 1000 1000 --length 100 100
Traceback (most recent call last):
  File "/root/my-fi-project/.venv/lib/python3.10/site-packages/findus/firmware/fault-injection-library-1.3.1/examples/pico-glitcher.py", line 162, in <module>
    main = Main(args)
  File "/root/my-fi-project/.venv/lib/python3.10/site-packages/findus/firmware/fault-injection-library-1.3.1/examples/pico-glitcher.py", line 51, in __init__
    self.glitcher.init(port=args.rpico, ext_power=args.power, ext_power_voltage=3.3)
  File "/root/my-fi-project/.venv/lib/python3.10/site-packages/findus/findus.py", line 672, in init
    self.pico_glitcher.init(port, 'PicoGlitcher')
  File "/root/my-fi-project/.venv/lib/python3.10/site-packages/findus/findus.py", line 379, in init
    self.pyb.exec(f'import {micropy_script}')
  File "/root/my-fi-project/.venv/lib/python3.10/site-packages/findus/pyboard.py", line 498, in exec_
    raise PyboardError("exception", ret, ret_err)
findus.pyboard.PyboardError: ('exception', b'', b'Traceback (most recent call last):\r\n  File "<stdin>", line 1, in <module>\r\n  File "PicoGlitcher.py", line 24, in <module>\r\nOSError: [Errno 2] ENOENT\r\n')
[+] Terminating gracefully.
(.venv) root@lukasz-virtual-machine:~/my-fi-project/.venv/lib/python3.10/site-packages/findus/firmware/fault-injection-library-1.3.1/examples# ls /dev/ttyACM0
/dev/ttyACM0
(.venv) root@lukasz-virtual-machine:~/my-fi-project/.venv/lib/python3.10/site-packages/findus/firmware/fault-injection-library-1.3.1/examples# sudo usermod -aG dialout $USER
(.venv) root@lukasz-virtual-machine:~/my-fi-project/.venv/lib/python3.10/site-packages/findus/firmware/fault-injection-library-1.3.1/examples# python
Python 3.10.12 (main, Feb  4 2025, 14:57:36) [GCC 11.4.0] on linux
Type "help", "copyright", "credits" or "license" for more information.
>>> pico-glitcher.py --rpico /dev/ttyACM0 --delay 1000 1000 --length 100 100
  File "<stdin>", line 1
    pico-glitcher.py --rpico /dev/ttyACM0 --delay 1000 1000 --length 100 100
                                                  ^^^^
SyntaxError: invalid syntax
>>> from findus import Database, PicoGlitcher
>>> pico-glitcher.py --rpico /dev/ttyACM0 --delay 1000 1000 --length 100 100
  File "<stdin>", line 1
    pico-glitcher.py --rpico /dev/ttyACM0 --delay 1000 1000 --length 100 100
                                                  ^^^^
SyntaxError: invalid syntax
>>>

What am I doing wrong?

MKesenheimer, 2025-03-13:
Thanks. I don't understand what is happening here. It is also hardly readable. Could you please use code fences in the future?

\`\`\`
your code here
\`\`\`

MKesenheimer, 2025-03-13:
I tried again step by step with this commands:

```
cd ~
mkdir my-fi-project && cd my-fi-project
python3 -m venv .venv && source .venv/bin/activate
pip install findus
cd .venv/lib/python3.13/site-packages/findus/firmware
upload --port /dev/tty.usbmodem1101 --files AD910X.py FastADC.py PicoGlitcher.py PulseGenerator.py Spline.py config_v1/config.json
cd ~/my-fi-project
wget https://raw.githubusercontent.com/MKesenheimer/fault-injection-library/refs/heads/master/examples/pico-glitcher.py
python pico-glitcher.py --rpico /dev/tty.usbmodem1101 --delay 0 0 --length 100 100
```

Please try again with these commands so that we can compare our results.

lfldp1, 2025-03-13:
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
MKesenheimer, 2025-03-13:
Please use code fences for longer pastes.

\`\`\`
your code here
\`\`\`

> This timeout means whats ?

You probably didn't connect RESET to TRIGGER. See here: https://fault-injection-library.readthedocs.io/en/latest/examples/

lfldp1, 2025-03-13:
> Please use code fences for longer pastes.

Please use code fences for longer pastes. - Yes and i did that in last post i use "code" button. I understand and thank for yours help will check this reset.

MKesenheimer, 2025-03-13:
> Please use code fences for longer pastes. - Yes and i did that in last post i use "code" button

For longer pastes over multiple lines the "code" button will not work. You will need to fence your pastes with three back-ticks:

\`\`\`
your code here
\`\`\`

lfldp1, 2025-03-13:
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

Ok i understand you now :)

Closed 2025-03-14.

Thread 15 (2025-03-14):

Support for multiple UART bytes

inode-, 2025-03-14:
Currently the picoglotcher support only UART trigger on a single byte.  It would be useful to have a trigger that activates after a specific sequence of bytes is received, to avoid possible collisions of individual bytes

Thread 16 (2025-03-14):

Unexpected behaviour in trigger with reset

inode-, 2025-03-14:
# Current setup
ESP32 is attached only with the reset and crowdbar. The ESP32 is powered by an external power supply.

The reset pin and the trigger pin are connected together.

# Code
```
            self.target.flush()

            # arm
            self.glitcher.rising_edge_trigger(pin_trigger=args.trigger_input, dead_time=0)
            self.glitcher.arm(delay, length)
            self.glitcher.reset(0.01)

            # block until glitch and read response
            try:
                self.glitcher.block(timeout=2)
                response = self.target.read(3000)
            except Exception as _:
                print("[-] Timeout received in block(). Continuing.")
                response = b'Timeout'
```

# Expected
I expect to glitch during the ESP32 startup.

# What I saw
It seems that after the arm the glitchout is set just after the reset signal is taken down during the `self.glitcher.reset(0.01)`.

CH3 (blue line) is the reset signal.
CH1 (yellow) is the LP glitch

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

zooomed

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

MKesenheimer, 2025-03-14:
Thanks inode, this is a known issue for a false trigger placement. Please use the Schmitt Trigger inputer EXT1 or EXT2 in this case. Alternatively you can use trigger suppression by a configurable dead zone:

https://fault-injection-library.readthedocs.io/en/latest/findus/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

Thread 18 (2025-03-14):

uart trigger dead

inode-, 2025-03-14:
Hello,

the code for uart_trigger currently doesn't work.

``` python
            self.glitcher.uart_trigger(0x11)
            self.glitcher.arm(delay, length)
            self.glitcher.reset(0.01)
```

The code will generate:

``` python
(.venv) D:\GIT\fault_injection_tests>python example1.py --target COM5 --rpico COM4 --delay 0 0 --length 100 100
[+] Version of Pico Glitcher: [1, 3, 1]
[+] Version of findus: [1, 3, 1]
Traceback (most recent call last):
  File "D:\GIT\fault_injection_tests\example1.py", line 147, in <module>
    main.run()
    ~~~~~~~~^^
  File "D:\GIT\fault_injection_tests\example1.py", line 78, in run
    self.glitcher.uart_trigger(0x11)
    ~~~~~~~~~~~~~~~~~~~~~~~~~~^^^^^^
  File "D:\GIT\fault_injection_tests\.venv\Lib\site-packages\findus\findus.py", line 1005, in uart_trigger
    self.pico_glitcher.set_trigger("uart", pin_trigger)
    ~~~~~~~~~~~~~~~~~~~~~~~~~~~~~~^^^^^^^^^^^^^^^^^^^^^
TypeError: PicoGlitcherInterface.set_trigger() missing 1 required positional argument: 'edge_type'
[+] Terminating gracefully.

(.venv) D:\GIT\fault_injection_tests>
```

The error seems to be at: https://github.com/MKesenheimer/fault-injection-library/blob/e5f5ca0029e1c198d04d33ec58e0d2e32355fec9/findus/findus.py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

The code `self.pico_glitcher.set_trigger("uart", pin_trigger, "rising")` should fix everything.

inode

Closed 2025-03-14.

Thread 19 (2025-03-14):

implements dead_time in edge_count_trigger

inode-, 2025-03-14:
In some cases would be useful to have the dead_time also in the edge counter functionallity.

The example is glitching on the ESP32 using the CS as trigger. If I want to glitch on the end of the latest CS blocks, the best way is to use dead_time until the pause between block and then use the edge counter.

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

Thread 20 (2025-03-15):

Script execution error.

Petr330, 2025-03-15:
Hello,
the code projects stm32f40x currently doesn't work.
```
>>> %FastDebug stm32f4-glitching.py --rpico /dev/ttyACM0 --target /dev/ttyUSB1 --delay 125000 125000 --length 20 30 --no-store
[+] Version of Pico Glitcher: [1, 3, 2]
[+] Version of findus: [1, 3, 2]
[+] Opening serial port /dev/ttyUSB1.
[-] Timeout received in block(). Continuing.
Traceback (most recent call last):
  File "/home/user1/fault-injection-library/projects/stm32f40x/stm32f4-glitching.py", line 165, in <module>
    main.run()
  File "/home/user1/fault-injection-library/projects/stm32f40x/stm32f4-glitching.py", line 129, in run
    speed = self.glitcher.get_speed(self.start_time, experiment_id)
AttributeError: 'Main' object has no attribute 'start_time'
>>>
```
Adding this code for "class Main:" fixes the error:
```
self.start_time = int(time.time())
```
But then another error occurs:
```
(.venv) user1@user1-Vostro-5502:~/fault-injection-library/projects/stm32f40x$ python stm32f4-glitching.py --rpico /dev/ttyACM0 --target /dev/ttyUSB1 --delay 125000 125000 --length 20 30 --no-store
[+] Version of Pico Glitcher: [1, 3, 2]
[+] Version of findus: [1, 3, 2]
[+] Opening serial port /dev/ttyUSB1.
[-] Timeout received in block(). Continuing.
[+] Experiment 0	0	(0)	125000	26	O	b"b'warning: timeout'"
[-] Timeout received in block(). Continuing.
[+] Experiment 1	0	(0)	125000	23	O	b"b'warning: timeout'"
........................................................................................................................
[-] Timeout received in block(). Continuing.
[+] Experiment 30	0	(1)	125000	23	O	b"b'warning: timeout'"
Traceback (most recent call last):
  File "/home/user1/fault-injection-library/projects/stm32f40x/stm32f4-glitching.py", line 166, in <module>
    main.run()
  File "/home/user1/fault-injection-library/projects/stm32f40x/stm32f4-glitching.py", line 143, in run
    self.error_handler.check(experiment_id=experiment_id, response=response, expected=b'expected', user_action=error_action)
  File "/home/user1/fault-injection-library/.venv/lib/python3.12/site-packages/findus/findus.py", line 1238, in check
    parameters = (experiment_id - self.look_back + 1, ) + parameters[1:-2] + ('O', str(response).encode("utf-8"))
                 ~~~~~~~~~~~~~~~~~~~~~~~~~~~~~~~~~~~~~~~^~~~~~~~~~~~~~~~~~
TypeError: can only concatenate tuple (not "list") to tuple
[+] Terminating gracefully.
[+] Closing serial port.
```
Could you check the code? Thanks in advance.

MKesenheimer, 2025-03-15:
Thanks, I will look into it.

MKesenheimer, 2025-03-15:
I could verify the first issue which I fixed in the latest push. You can update via `git pull`.

However I was not able to verify the second issue. Could you please go to `findus/findus.py` line `1238` and add these lines?

```
                    print(f"debug1 = {parameters[1:-2]}")
                    print(f"debug2 = {(experiment_id - self.look_back + 1, )}")
```

What is the output before the exception is displayed? Look out for the lines `debug1` and `debug2`. You have to install findus manually in this case:

```
cd fault-injection-library
pip install .
```

MKesenheimer, 2025-03-15:
Are you on Windows or Linux?

Petr330, 2025-03-15:
> Are you on Windows or Linux?

Yes.
```
(.venv) user1@user1-Vostro-5502:~/fault-injection-library$ lsb_release -a
No LSB modules are available.
Distributor ID:	Ubuntu
Description:	Ubuntu 24.04.2 LTS
Release:	24.04
Codename:	noble
(.venv) user1@user1-Vostro-5502:~/fault-injection-library$ python -V
Python 3.12.3
(.venv) user1@user1-Vostro-5502:~/fault-injection-library$
```

Petr330, 2025-03-15:
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

There is an error:
```
(.venv) user1@user1-Vostro-5502:~/fault-injection-library/projects/stm32f40x$ python stm32f4-glitching.py --rpico /dev/ttyACM0 --target /dev/ttyUSB1 --delay 125000 125000 --length 20 30 --no-store
[+] Version of Pico Glitcher: [1, 3, 2]
[+] Version of findus: [1, 3, 2]
[+] Opening serial port /dev/ttyUSB1.
[-] Timeout received in block(). Continuing.
[+] Experiment 0	0	(0)	125000	22	O	b"b'warning: timeout'"
[-] Timeout received in block(). Continuing.
[+] Experiment 1	0	(0)	125000	24	O	b"b'warning: timeout'"
[-] Timeout received in block(). Continuing.
[+] Experiment 2	0	(0)	125000	26	O	b"b'warning: timeout'"
[-] Timeout received in block(). Continuing.
[+] Experiment 3	0	(0)	125000	25	O	b"b'warning: timeout'"
[-] Timeout received in block(). Continuing.
[+] Experiment 4	0	(0)	125000	20	O	b"b'warning: timeout'"
[-] Timeout received in block(). Continuing.
[+] Experiment 5	0	(0)	125000	21	O	b"b'warning: timeout'"
[-] Timeout received in block(). Continuing.
[+] Experiment 6	0	(0)	125000	27	O	b"b'warning: timeout'"
[-] Timeout received in block(). Continuing.
[+] Experiment 7	0	(0)	125000	24	O	b"b'warning: timeout'"
[-] Timeout received in block(). Continuing.
[+] Experiment 8	0	(0)	125000	25	O	b"b'warning: timeout'"
[-] Timeout received in block(). Continuing.
[+] Experiment 9	0	(0)	125000	27	O	b"b'warning: timeout'"
[-] Timeout received in block(). Continuing.
[+] Experiment 10	0	(0)	125000	25	O	b"b'warning: timeout'"
[-] Timeout received in block(). Continuing.
[+] Experiment 11	0	(0)	125000	30	O	b"b'warning: timeout'"
[-] Timeout received in block(). Continuing.
[+] Experiment 12	0	(0)	125000	21	O	b"b'warning: timeout'"
[-] Timeout received in block(). Continuing.
[+] Experiment 13	0	(0)	125000	25	O	b"b'warning: timeout'"
[-] Timeout received in block(). Continuing.
[+] Experiment 14	0	(0)	125000	30	O	b"b'warning: timeout'"
[-] Timeout received in block(). Continuing.
[+] Experiment 15	0	(0)	125000	30	O	b"b'warning: timeout'"
[-] Timeout received in block(). Continuing.
[+] Experiment 16	0	(0)	125000	28	O	b"b'warning: timeout'"
[-] Timeout received in block(). Continuing.
[+] Experiment 17	0	(0)	125000	28	O	b"b'warning: timeout'"
[-] Timeout received in block(). Continuing.
[+] Experiment 18	0	(0)	125000	27	O	b"b'warning: timeout'"
[-] Timeout received in block(). Continuing.
[+] Experiment 19	0	(0)	125000	30	O	b"b'warning: timeout'"
[-] Timeout received in block(). Continuing.
[+] Experiment 20	0	(0)	125000	29	O	b"b'warning: timeout'"
[-] Timeout received in block(). Continuing.
[+] Experiment 21	0	(0)	125000	25	O	b"b'warning: timeout'"
[-] Timeout received in block(). Continuing.
[+] Experiment 22	0	(0)	125000	30	O	b"b'warning: timeout'"
[-] Timeout received in block(). Continuing.
[+] Experiment 23	0	(0)	125000	22	O	b"b'warning: timeout'"
[-] Timeout received in block(). Continuing.
[+] Experiment 24	0	(0)	125000	29	O	b"b'warning: timeout'"
[-] Timeout received in block(). Continuing.
[+] Experiment 25	0	(0)	125000	24	O	b"b'warning: timeout'"
[-] Timeout received in block(). Continuing.
[+] Experiment 26	0	(0)	125000	29	O	b"b'warning: timeout'"
[-] Timeout received in block(). Continuing.
[+] Experiment 27	0	(0)	125000	27	O	b"b'warning: timeout'"
[-] Timeout received in block(). Continuing.
[+] Experiment 28	0	(0)	125000	25	O	b"b'warning: timeout'"
[-] Timeout received in block(). Continuing.
[+] Experiment 29	0	(0)	125000	20	O	b"b'warning: timeout'"
[-] Timeout received in block(). Continuing.
[+] Experiment 30	0	(0)	125000	24	O	b"b'warning: timeout'"
debug1 = []
debug2 = (1,)
Traceback (most recent call last):
  File "/home/user1/fault-injection-library/projects/stm32f40x/stm32f4-glitching.py", line 166, in <module>
    main.run()
  File "/home/user1/fault-injection-library/projects/stm32f40x/stm32f4-glitching.py", line 143, in run
    self.error_handler.check(experiment_id=experiment_id, response=response, expected=b'expected', user_action=error_action)
  File "/home/user1/fault-injection-library/.venv/lib/python3.12/site-packages/findus/findus.py", line 1240, in check
    parameters = (experiment_id - self.look_back + 1, ) + parameters[1:-2] + ('O', str(response).encode("utf-8"))
                 ~~~~~~~~~~~~~~~~~~~~~~~~~~~~~~~~~~~~~~~^~~~~~~~~~~~~~~~~~
TypeError: can only concatenate tuple (not "list") to tuple
[+] Terminating gracefully.
[+] Closing serial port.
(.venv) user1@user1-Vostro-5502:~/fault-injection-library/projects/stm32f40x$
```

Petr330, 2025-03-15:
Figured it out a bit. This error occurs when using the --no-store key.

MKesenheimer, 2025-03-15:
ah, yes, that makes sense. Then, no experiments can be loaded from the database and error handling fails. Thanks for reporting, I will figure out a fix.

MKesenheimer, 2025-03-15:
Pushed another fix. I added a try except block which should be sufficient in that case.

Closed 2025-03-15.

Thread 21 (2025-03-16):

ADC times out if not used in connection with reset_target()

MKesenheimer, 2025-03-16:
If the following code is used in `exampl/pico-glitcher.py` to generate the trigger signal, the ADC times out:

```
            # reset target via gpio
            self.glitcher.set_gpio(5, 0)
            time.sleep(0.01)
            self.glitcher.set_gpio(5, 1)
```

This can be partially remedied, if a sleep is used in `findus/firmware/PicoGlitcher.py`:

```
    def arm_adc(self):
        if self.core1_stopped:
            _thread.start_new_thread(self.__poll_fast_adc, ())
            time.sleep(0.001)
```

However, than the ADC triggers too late or too early (?) and the glitch can not be observed anymore.

- Why does it matter if the target is reset via `set_gpio` isntead of `reset_target`?
- Why does a sleep function mitigate this problem partially?

It has been checked, that `wait_irq7()` works correctly. This function blocks the ADC until the trigger signal is observed.

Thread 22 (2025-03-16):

Force core1 to stop if the arm() function is called

MKesenheimer, 2025-03-16:
Sometimes the ADC does not trigger correctly. If the ADC is armed while core1 is still active, an exception ‘core1 is active’ occurs. This is because the function `wait_irq7` is executed on core1 and the trigger did not cause the loop to exit.

This could be mitigated by checking another status variable in the loop of function `wait_irq7`. If the status variable changes, the loop should exit.

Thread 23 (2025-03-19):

Error reading response bytes through Serial Port.

Petr330, 2025-03-19:
Hello.
I am working with the stm32f40x project.
The script has an error reading bytes via the serial port.
```
(.venv) user1@user1-ub24:~/fault-injection-library/projects/stm32f40x$ python stm32f4-glitching.py --rpico /dev/ttyACM0 --target /dev/ttyUSB0 --delay 125000 125000 --length 20 30
[+] Version of Pico Glitcher: [1, 5, 0]
[+] Version of findus: [1, 5, 0]
[+] Opening serial port /dev/ttyUSB0.
UARTsetPort = Serial<id=0x713f87722110, open=True>(port='/dev/ttyUSB0', baudrate=115200, bytesize=8, parity='E', stopbits=1, timeout=1, xonxoff=False, rtscts=False, dsrdtr=False)
init_bootloader_read = b'y'
setup_memread_read = b'y'
[-] Timeout received in block(). Continuing.
[+] Experiment 0	0	(0)	125000	23	O	b'warning: timeout'
init_bootloader_read = b'y'
setup_memread_read = b'\xb9'
[-] Timeout received in block(). Continuing.
[+] Experiment 1	0	(0)	125000	22	O	b'warning: timeout'
init_bootloader_read = b'\xf9'
[+] Experiment 2	0	(1)	125000	26	M	b'error: bootloader error'
init_bootloader_read = b'y'
setup_memread_read = b'y'
[-] Timeout received in block(). Continuing.
[+] Experiment 3	0	(1)	125000	22	O	b'warning: timeout'
init_bootloader_read = b'\xf9'
[+] Experiment 4	0	(1)	125000	20	M	b'error: bootloader error'
init_bootloader_read = b'y'
setup_memread_read = b'y'
[-] Timeout received in block(). Continuing.
[+] Experiment 5	0	(1)	125000	29	O	b'warning: timeout'
init_bootloader_read = b'y'
setup_memread_read = b'y'
[-] Timeout received in block(). Continuing.
[+] Experiment 6	0	(1)	125000	21	O	b'warning: timeout'
init_bootloader_read = b'y'
setup_memread_read = b'y'
[-] Timeout received in block(). Continuing.
[+] Experiment 7	0	(1)	125000	22	O	b'warning: timeout'
init_bootloader_read = b'y'
setup_memread_read = b'y'
[-] Timeout received in block(). Continuing.
[+] Experiment 8	0	(1)	125000	21	O	b'warning: timeout'
init_bootloader_read = b'y'
setup_memread_read = b'\xb9'
[-] Timeout received in block(). Continuing.
[+] Experiment 9	0	(1)	125000	22	O	b'warning: timeout'
init_bootloader_read = b'y'
setup_memread_read = b'y'
[-] Timeout received in block(). Continuing.
[+] Experiment 10	0	(1)	125000	29	O	b'warning: timeout'
init_bootloader_read = b'y'
setup_memread_read = b'y'
[-] Timeout received in block(). Continuing.
[+] Experiment 11	0	(1)	125000	27	O	b'warning: timeout'
init_bootloader_read = b'y'
setup_memread_read = b'y'
[-] Timeout received in block(). Continuing.
[+] Experiment 12	0	(1)	125000	25	O	b'warning: timeout'
init_bootloader_read = b'y'
setup_memread_read = b'y'
[-] Timeout received in block(). Continuing.
[+] Experiment 13	0	(1)	125000	20	O	b'warning: timeout'
init_bootloader_read = b'y'
setup_memread_read = b'y'
[-] Timeout received in block(). Continuing.
[+] Experiment 14	0	(1)	125000	24	O	b'warning: timeout'
init_bootloader_read = b'y'
setup_memread_read = b'y'
[-] Timeout received in block(). Continuing.
[+] Experiment 15	0	(1)	125000	25	O	b'warning: timeout'
init_bootloader_read = b'y'
setup_memread_read = b'y'
[-] Timeout received in block(). Continuing.
[+] Experiment 16	0	(1)	125000	28	O	b'warning: timeout'
init_bootloader_read = b'\xf9'
[+] Experiment 17	0	(1)	125000	30	M	b'error: bootloader error'
init_bootloader_read = b'y'
setup_memread_read = b'y'
[-] Timeout received in block(). Continuing.
[+] Experiment 18	0	(1)	125000	30	O	b'warning: timeout'
init_bootloader_read = b'y'
setup_memread_read = b'y'
[-] Timeout received in block(). Continuing.
[+] Experiment 19	0	(1)	125000	25	O	b'warning: timeout'
init_bootloader_read = b'y'
setup_memread_read = b'y'
[-] Timeout received in block(). Continuing.
[+] Experiment 20	0	(1)	125000	25	O	b'warning: timeout'
init_bootloader_read = b'y'
setup_memread_read = b'y'
[-] Timeout received in block(). Continuing.
[+] Experiment 21	0	(1)	125000	21	O	b'warning: timeout'
init_bootloader_read = b'y'
setup_memread_read = b'y'
[-] Timeout received in block(). Continuing.
[+] Experiment 22	0	(1)	125000	26	O	b'warning: timeout'
init_bootloader_read = b'y'
setup_memread_read = b'y'
[-] Timeout received in block(). Continuing.
[+] Experiment 23	0	(1)	125000	29	O	b'warning: timeout'
init_bootloader_read = b'y'
setup_memread_read = b'y'
[-] Timeout received in block(). Continuing.
[+] Experiment 24	0	(1)	125000	20	O	b'warning: timeout'
init_bootloader_read = b'y'
setup_memread_read = b'y'
[-] Timeout received in block(). Continuing.
[+] Experiment 25	0	(1)	125000	26	O	b'warning: timeout'
init_bootloader_read = b'y'
setup_memread_read = b'y'
[-] Timeout received in block(). Continuing.
[+] Experiment 26	0	(1)	125000	21	O	b'warning: timeout'
init_bootloader_read = b'y'
setup_memread_read = b'y'
[-] Timeout received in block(). Continuing.
[+] Experiment 27	0	(1)	125000	26	O	b'warning: timeout'
init_bootloader_read = b'y'
setup_memread_read = b'y'
[-] Timeout received in block(). Continuing.
[+] Experiment 28	0	(1)	125000	30	O	b'warning: timeout'
init_bootloader_read = b'y'
setup_memread_read = b'y'
[-] Timeout received in block(). Continuing.
[+] Experiment 29	0	(1)	125000	24	O	b'warning: timeout'
init_bootloader_read = b'y'
setup_memread_read = b'y'
[-] Timeout received in block(). Continuing.
[+] Experiment 30	0	(1)	125000	25	O	b'warning: timeout'
^C
Exitting...
[+] Terminating gracefully.
[+] Closing serial port.
(.venv) user1@user1-ub24:~/fault-injection-library/projects/stm32f40x$

```
For more information, I added data output to the script.

```
 print(f"[+] Opening serial port {port}.")
        self.ser = serial.Serial(port=port, baudrate=115200, timeout=1, bytesize=8, parity="E", stopbits=1)
        print(f"UARTsetPort = {self.ser}")
```
```
    # init bootloader
        self.ser.write(b'\x7f')
        s = self.ser.read(1)
        print(f"init_bootloader_read = {s}")
        if s == self.ACK:
            return b'ok: bootloader ok'
        return b'error: bootloader error'
```
```
 # read memory command (x11: read memory, xee: crc)
        self.ser.write(b'\x11\xee')
        if read:
            s = self.ser.read(1)
            print(f"setup_memread_read = {s}")
```
At the same time, the logical analyzer shows correct data exchange. Wireshark interception also shows correct data exchange.

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

Petr330, 2025-03-19:
Distributor ID:	Ubuntu
Description:	Ubuntu 24.04.2 LTS
Python 3.12.3

MKesenheimer, 2025-03-19:
What do you mean by "the script has an error reading the bytes"? Are you worried about the timeout or the error

```
...
init_bootloader_read = b'\xf9'
[+] Experiment 17	0	(1)	125000	30	M	b'error: bootloader error'
...
```

Maybe you can also try the project `stm32f42x` which should be nearly identical.

Petr330, 2025-03-19:
My target device is in RDP0 mode.

MKesenheimer, 2025-03-19:
Ah understood. Can you please print the variable `response` at each step and run a few more experiments?

MKesenheimer, 2025-03-19:
I know what's wrong. Sorry for that. I push a solution in the next few minutes.

MKesenheimer, 2025-03-19:
Ok, after a few attempts, it should work now.

Petr330, 2025-03-19:
Sorry, I probably misled you. Error reading bytes occurs in the STM32Bootloader.py script when running the stm32f4-glitching.py script. The script STM32Bootloader.py does not receive the correct data for its work. I made the changes indicated above to the STM32Bootloader.py script.

MKesenheimer, 2025-03-19:
Alright, can you still please print the variable `response` at each step and run a few more experiments?

MKesenheimer, 2025-03-19:
I quickly verified with my setup. It seems to work on my side.

Petr330, 2025-03-19:
> Хорошо, можете ли вы все равно распечатать переменную `response`на каждом шаге и провести еще несколько экспериментов?
In which script? I think the problem is in the STM32Bootloader.py script when reading data from the serial port. Now two functions are running in a cycle - bootloader initialization and memory read attempt. The script cannot get correct data from the target board.

MKesenheimer, 2025-03-19:
I verified with the script `fault-injection-library/projects/stm32f40x/stm32f4-glitching.py` from the latest push. Maybe something else is wrong? Did you connect the trigger input to the UART-TX line?

Please post also an output of the variable `response` at each step of the script `stm32f4-glitching.py`.

Petr330, 2025-03-19:
Tomorrow I will be able to conduct experiments. Everything is connected correctly. stm32flash works fine via the serial port interface.
```
user1@user1-ub24:~/stm32flash-code$ stm32flash -b 115200 /dev/ttyUSB0
stm32flash 0.7

http://stm32flash.sourceforge.net/

Interface serial_posix: 115200 8E1
Version      : 0x31
Option 1     : 0x00
Option 2     : 0x00
Device ID    : 0x0413 (STM32F40xxx/41xxx)
- RAM        : Up to 128KiB  (12288b reserved by bootloader)
- Flash      : Up to 1024KiB (size first sector: 1x16384)
- Option bytes  : 16b
- System memory : 30KiB
```

MKesenheimer, 2025-03-19:
ok, perfect. Let me know how it goes. I also tried to optimize the script a bit. Now the serial timeouts are a bit better and the script should be faster.

Petr330, 2025-03-19:
What version of python are you using?

MKesenheimer, 2025-03-19:
Python 3.13.2

Should not make a huge difference.

MKesenheimer, 2025-03-19:
Remember that you probably have to play with the timeouts at your side too. The stm32f4 is a bit picky in that regard.
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
MKesenheimer, 2025-03-20:
Ok, understood. This is because the timeout condition overwrites any response from the target. The script goes into timeout because the trigger condition is not met. For testing, you can either comment the line `self.glitcher.block(timeout=1)` or connect the TX line of your uart adapter to the trigger input of the Pico Glitcher (so that the Pico Glitcher can observe the trigger condition).

MKesenheimer, 2025-03-20:
You can also try communicating with your target with the command-line tool `power-cycle-and-read`:
https://fault-injection-library.readthedocs.io/en/latest/cli/

MKesenheimer, 2025-03-24:
Hey, good to hear! Yes that rate is acceptable. We have to glitch for every read attempt and getting the glitch position right is hard. You can of course try to optimize the glitch length and delay. Maybe it can be improved a little.

I am using macos and linux for running these scripts.

Thanks for reporting this issue.

Closed 2025-03-24.

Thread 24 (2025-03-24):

Error starting database server.

Petr330, 2025-03-24:
When starting the database, the following error occurs:
```
(.venv) user1@user1-ub24:~/fault-injection-library/projects/stm32f40x$ analyzer --directory databases
Traceback (most recent call last):
  File "/home/user1/fault-injection-library/.venv/bin/analyzer", line 8, in <module>
    sys.exit(main())
             ^^^^^^
  File "/home/user1/fault-injection-library/.venv/lib/python3.12/site-packages/findus/analyzer/analyzer.py", line 462, in main
    run(directory=args.directory, ip=args.ip, port=args.port, x_axis=args.x, y_axis=args.y, aspect_ratio=args.aspect_ratio, auto_update_interval=args.auto_update, debug=True)
  File "/home/user1/fault-injection-library/.venv/lib/python3.12/site-packages/findus/analyzer/analyzer.py", line 444, in run
    app.run_server(host=ip, port=port, debug=True)
    ^^^^^^^^^^^^^^
  File "/home/user1/fault-injection-library/.venv/lib/python3.12/site-packages/dash/_obsolete.py", line 22, in __getattr__
    raise err.exc(err.message)
dash.exceptions.ObsoleteAttributeException: app.run_server has been replaced by app.run
(.venv) user1@user1-ub24:~/fault-injection-library/projects/stm32f40x$

(.venv) user1@user1-ub24:~/fault-injection-library/projects/stm32f40x$ lsb_release -a
No LSB modules are available.
Distributor ID:	Ubuntu
Description:	Ubuntu 24.04.2 LTS
Release:	24.04
Codename:	noble
(.venv) user1@user1-ub24:~/fault-injection-library/projects/stm32f40x$

```

MKesenheimer, 2025-03-24:
Fixed in latest commit. Thank you for reporting.

Closed 2025-03-24.

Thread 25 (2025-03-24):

Error updating database.

Petr330, 2025-03-24:
After updating the project, the database server starts, but when updating the database, an error occurs:
```
Traceback (most recent call last):
  File "/home/user1/fault-injection-library/.venv/lib/python3.12/site-packages/findus/analyzer/analyzer.py", line 158, in update_dropdown
    return get_databases(DATABASE_DIRECTORY)
           ^^^^^^^^^^^^^^^^^^^^^^^^^^^^^^^^^
  File "/home/user1/fault-injection-library/.venv/lib/python3.12/site-packages/findus/analyzer/analyzer.py", line 81, in get_databases
    databases_new.append('%s (%d)' %(databases[index], get_number_of_experiments(directory, databases[index])))
                                                       ^^^^^^^^^^^^^^^^^^^^^^^^^^^^^^^^^^^^^^^^^^^^^^^^^^^^^^^^
  File "/home/user1/fault-injection-library/.venv/lib/python3.12/site-packages/findus/analyzer/analyzer.py", line 34, in get_number_of_experiments
    cursor.execute(query)
sqlite3.OperationalError: attempt to write a readonly database
```

MKesenheimer, 2025-03-24:
What was your command? Did you use `resume`?

Petr330, 2025-03-24:
I used the stm32f4-glitching.py script command with the --resume key and without it. There are many database files in the database directory, but the server does not work with them.

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
DB Browser works fine with these files.

```
(.venv) user1@user1-ub24:~/fault-injection-library/projects/stm32f40x$ analyzer --directory databases
Dash is running on http://127.0.0.1:8080/

 * Serving Flask app 'findus.analyzer.analyzer'
 * Debug mode: on
```
When opened in a web browser, the database is not updated.
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

MKesenheimer, 2025-03-24:
Weird. Did you change the number of parameters in between? Can you please delete or rename the database folder and try again with a completely new setup?

Petr330, 2025-03-24:
I cleared the database directory, but when I run the script I get an error:
```
(.venv) user1@user1-ub24:~/fault-injection-library/projects/stm32f40x$ python stm32f4-glitching_m_v2.py --rpico /dev/ttyACM0 --target /dev/ttyUSB0 --delay 108000 108000 --length 1000 1000 --resume
[+] Version of Pico Glitcher: [1, 5, 0]
[+] Version of findus: [1, 5, 0]
Traceback (most recent call last):
  File "/home/user1/fault-injection-library/projects/stm32f40x/stm32f4-glitching_m_v2.py", line 170, in <module>
    main = Main(args)
           ^^^^^^^^^^
  File "/home/user1/fault-injection-library/projects/stm32f40x/stm32f4-glitching_m_v2.py", line 60, in __init__
    self.database = Database(sys.argv, resume=self.args.resume, nostore=self.args.no_store)
                    ^^^^^^^^^^^^^^^^^^^^^^^^^^^^^^^^^^^^^^^^^^^^^^^^^^^^^^^^^^^^^^^^^^^^^^^
  File "/home/user1/fault-injection-library/.venv/lib/python3.12/site-packages/findus/findus.py", line 87, in __init__
    latest_file = max(list_of_files, key=os.path.getctime)[10:]
                  ^^^^^^^^^^^^^^^^^^^^^^^^^^^^^^^^^^^^^^^^
ValueError: max() iterable argument is empty
[+] Terminating gracefully.
(.venv) user1@user1-ub24:~/fault-injection-library/projects/stm32f40x$
```

Petr330, 2025-03-24:
Yes, the database is working. First we clear the directory, run the script once without the --resume key, then with the key and the database files are visible through the browser.

MKesenheimer, 2025-03-24:
Understood. I will clarify the --resume argument and make it easier to use. Is now everything working as expected?

Petr330, 2025-03-24:
Yes, thank you.

Closed 2025-03-25.

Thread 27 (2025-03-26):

No start_time in pico-glitcher-uart-trigger.py

Flybro, 2025-03-26:
Calling this ends with an error "'Main' object has no attribute 'start_time'"
Adding "self.start_time = int(time.time())" fixes the issue.

MKesenheimer, 2025-03-26:
Fixed. Thank you!

Closed 2025-03-26.

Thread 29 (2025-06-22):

Backward compatybility

Flybro, 2025-06-22:
Hi,
I'm trying to run Pico Glitcher in hardware version 2.1 with STM8s as target with latest version of findus but something just doesn't want to work. And by the way, how backward is the findus library compatible with the hardware? I've also tried with the latest version (v1.11.2) but I get a message about version incompatibility but without any additional information.

Even when Pico, Glitcher, and findus are in the same version, errors still occur.

Installation:

    pip install findus==1.5.0
    git clone --branch 1.5.0 --single-branch https://github.com/MKesenheimer/fault-injection-library.git findus

Input:

    python stm8-readmemory.py \
    --target /dev/ttyACM0 \
    --rpico /dev/ttyACM1 \
    --delay 106_000 107_500 \
    --length 10 100

Output:

    [+] Version of Pico Glitcher: [1, 5, 0]
    [+] Version of findus: [1, 5, 0]
    Traceback (most recent call last):
      File "/home/masterchief/Hardware/findus/projects/stm8s/stm8-readmemory.py", line 149, in <module>
        main = Main(args)
      File "/home/masterchief/Hardware/findus/projects/stm8s/stm8-readmemory.py", line 48, in __init__
        self.glitcher.init(port=args.rpico)
      File "/home/masterchief/.findus/lib/python3.10/site-packages/findus/findus.py", line 712, in init
        self.pico_glitcher.enable_vtarget()
      File "/home/masterchief/.findus/lib/python3.10/site-packages/findus/findus.py", line 450, in enable_vtarget
        self.pyb.exec(f'mp.enable_vtarget({use_mux})')
      File "/home/masterchief/.findus/lib/python3.10/site-packages/findus/pyboard.py", line 498, in exec_
        raise PyboardError("exception", ret, ret_err)
    findus.pyboard.PyboardError: ('exception', b'', b'Traceback (most recent call last):\r\n  File "<stdin>", line 1, in <module>\r\nTypeError: function takes 1 positional arguments but 2 were given\r\n')
    [+] Terminating gracefully.

MKesenheimer, 2025-06-22:
Hey,

thanks for reporting this issue. The software is backwards compatible with all versions of the Pico Glitcher. For sure with all versions 2.x. Can you please try to use the latest version?

```
mkdir my-fi-project && cd my-fi-project
python3 -m venv .venv && source .venv/bin/activate
pip install findus==1.11.2
cd .venv/lib/python3.xx/site-packages/findus/firmware
upload --port /dev/tty.<rpi-tty-port> --files AD910X.py FastADC.py Globals.py \
    PicoGlitcher.py PulseGenerator.py Spline.py config_v2.1-2/config.json
```

Flybro, 2025-06-29:
Installing findus with the version specified helped, thanks.

MKesenheimer, 2025-06-29:
Perfect! Glad to help!

Closed 2025-06-29.

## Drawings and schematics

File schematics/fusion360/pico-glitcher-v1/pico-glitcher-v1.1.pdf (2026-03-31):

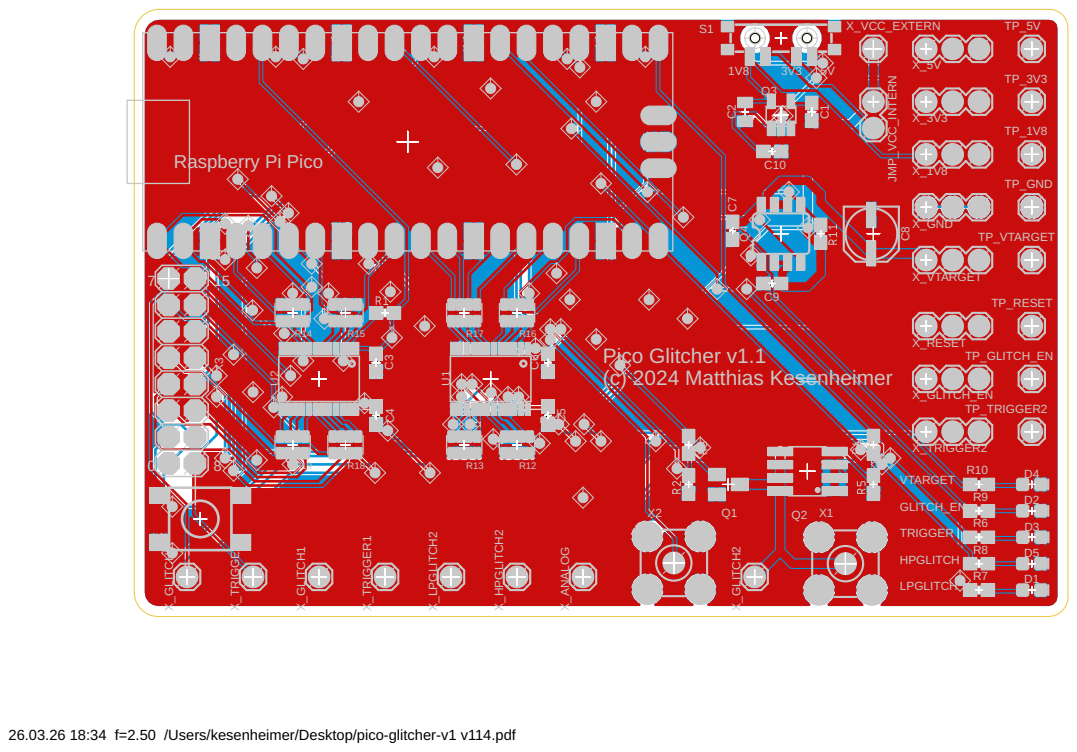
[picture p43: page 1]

26.03.26 18:34 f=2.50 /Users/kesenheimer/Desktop/pico-glitcher-v1 v114.pdf

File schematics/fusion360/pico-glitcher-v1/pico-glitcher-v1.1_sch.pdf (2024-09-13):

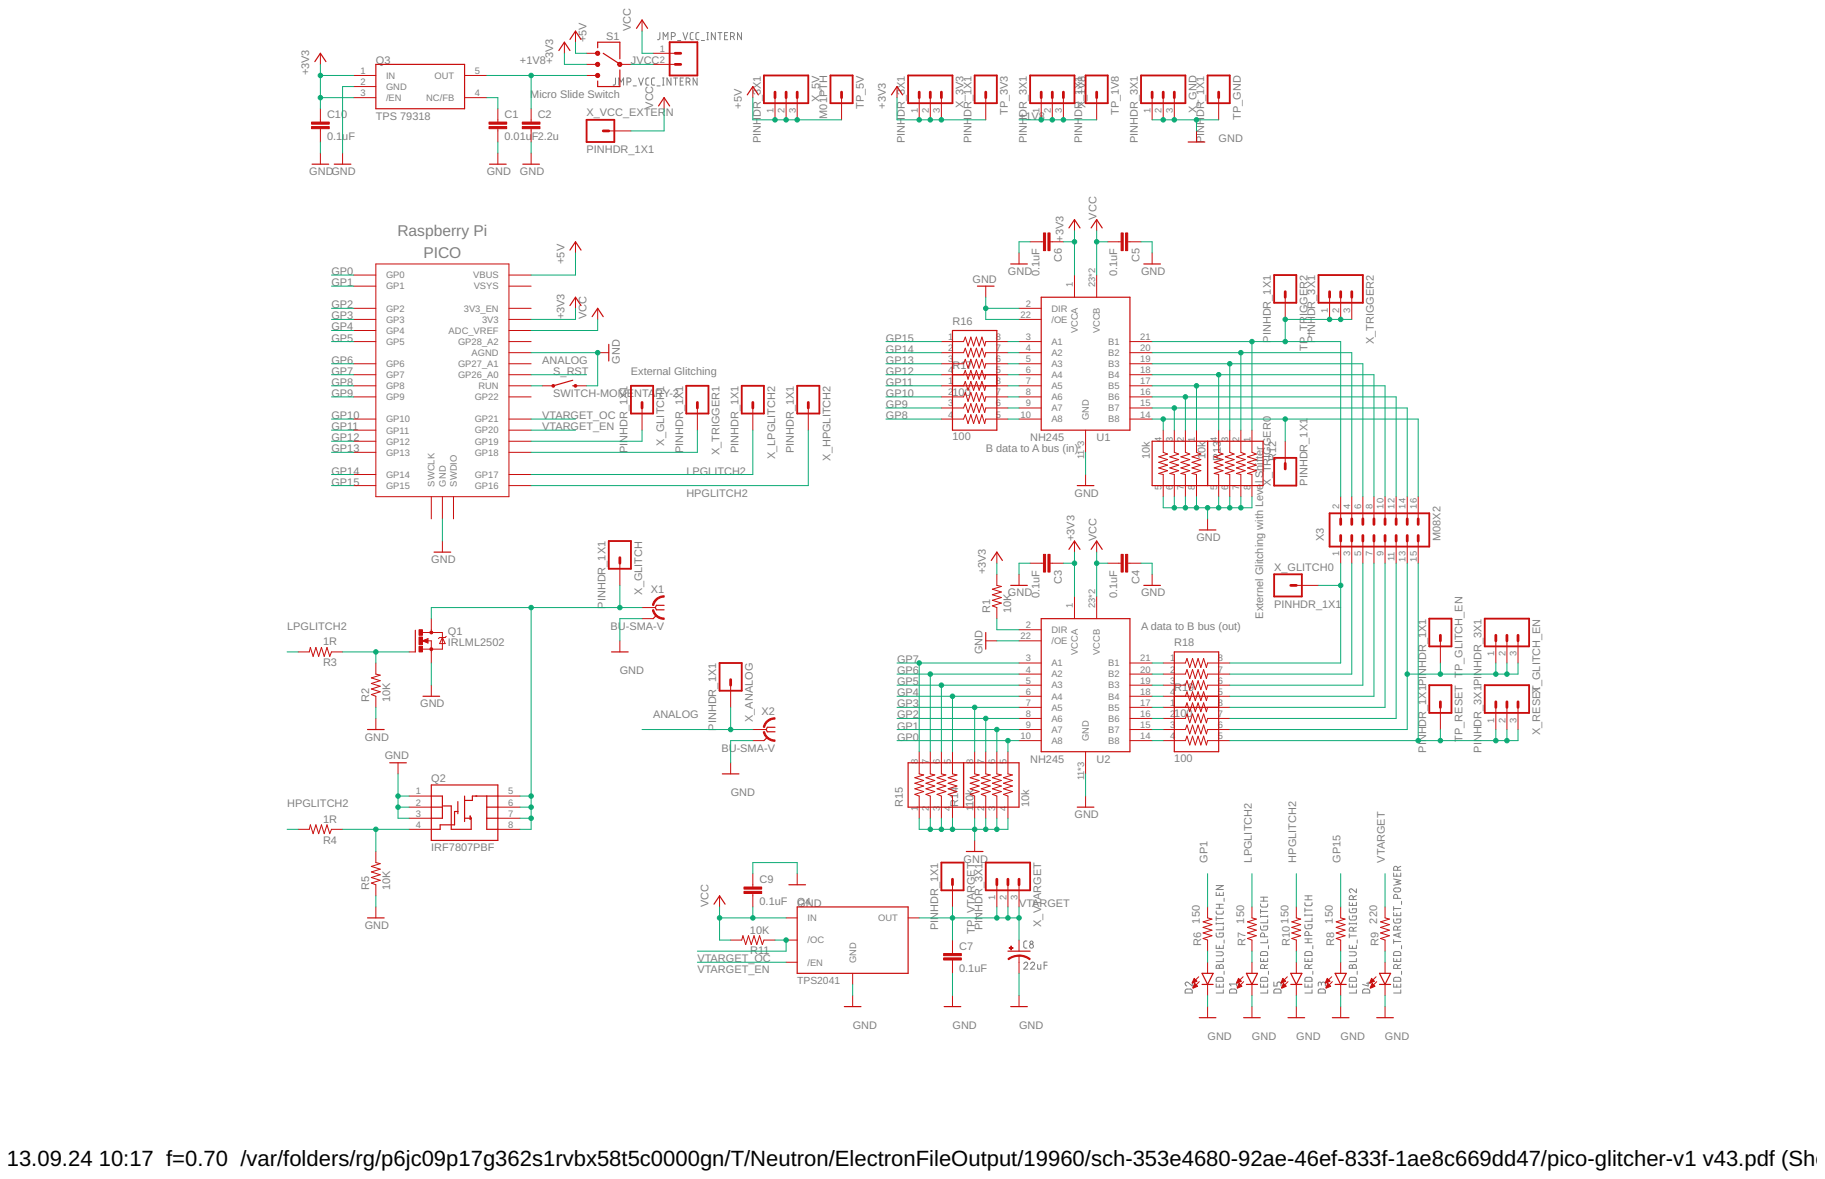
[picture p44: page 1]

Externel Glitching with Level Shifter

13.09.24 10:17 f=0.70 /var/folders/rg/p6jc09p17g362s1rvbx58t5c0000gn/T/Neutron/ElectronFileOutput/19960/sch-353e4680-92ae-46ef-833f-1ae8c669dd47/pico-glitcher-v1 v43.pdf (Sheet: 1/1)

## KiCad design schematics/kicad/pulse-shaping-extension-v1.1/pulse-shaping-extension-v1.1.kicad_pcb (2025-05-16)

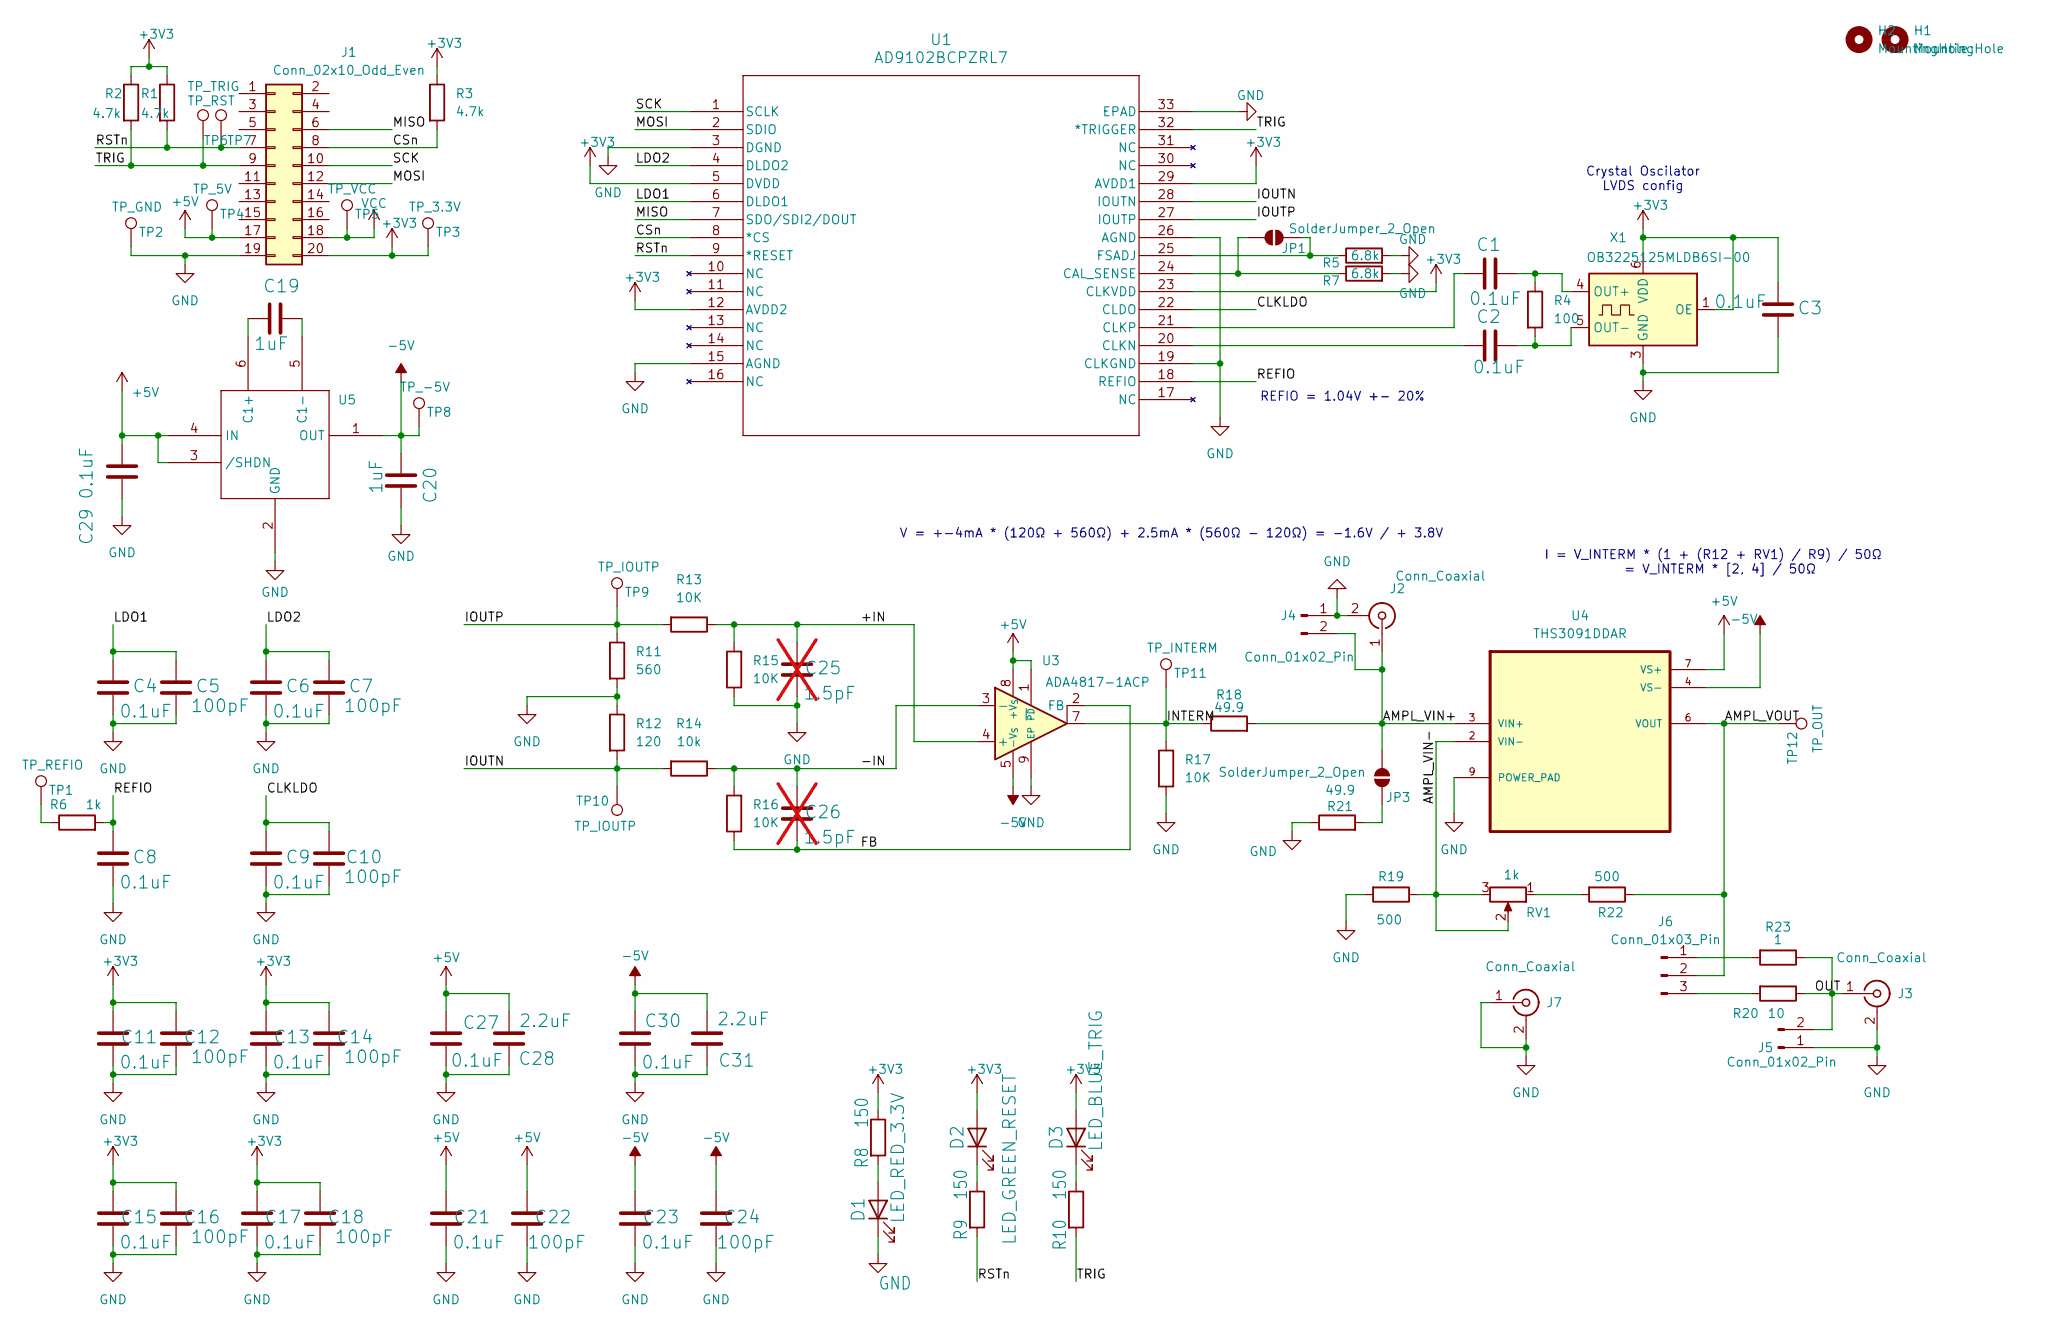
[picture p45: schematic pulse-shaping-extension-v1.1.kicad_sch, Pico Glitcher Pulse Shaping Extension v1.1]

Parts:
C1, C2, C3, C4, C6, C8, C9, C11, C13, C15, C17, C21, C23, C27, C29, C30: 0.1uF; C_0603_1608Metric
C5, C7, C10, C12, C14, C16, C18, C22, C24: 100pF; C_0603_1608Metric
C19, C20: 1uF; C_0805_2012Metric
C25, C26: 1.5pF; C_0603_1608Metric; not fitted
C28, C31: 2.2uF; C_0805_2012Metric
D1: LED_RED_3.3V; LED_0603_1608Metric
D2: LED_GREEN_RESET; LED_0603_1608Metric
D3: LED_BLUE_TRIG; LED_0603_1608Metric
H1, H2: MountingHole; MountingHole_3mm
J1: Conn_02x10_Odd_Even; PinHeader_2x10_P2.54mm_Vertical
J2, J3, J7: Conn_Coaxial; SMA_Amphenol_901-144_Vertical
J4, J5: Conn_01x02_Pin; PinHeader_1x02_P2.54mm_Vertical
J6: Conn_01x03_Pin; PinHeader_1x03_P2.54mm_Vertical
JP1, JP3: SolderJumper_2_Open; SolderJumper-2_P1.3mm_Open_TrianglePad1.0x1.5mm
R1, R2, R3: 4.7k; R_0603_1608Metric
R4: 100; R_0603_1608Metric
R5, R7: 6.8k; R_0603_1608Metric
R6: 1k; R_0603_1608Metric
R8, R9, R10: 150; R_0603_1608Metric
R11: 560; R_0603_1608Metric
R12: 120; R_0603_1608Metric
R13, R15, R16, R17: 10K; R_0603_1608Metric
R14: 10k; R_0603_1608Metric
R18, R21: 49.9; R_0603_1608Metric
R19, R22: 500; R_0603_1608Metric
R20: 10; R_2512_6332Metric
R23: 1; R_2512_6332Metric
RV1: 1k; Potentiometer_Bourns_TC33X_Vertical
TP1: TP_REFIO; TestPoint_Pad_D1.0mm
TP2: TP_GND; TestPoint_Pad_D1.0mm
TP3: TP_3.3V; TestPoint_Pad_D1.0mm
TP4: TP_5V; TestPoint_Pad_D1.0mm
TP5: TP_VCC; TestPoint_Pad_D1.0mm
TP6: TP_TRIG; TestPoint_Pad_D1.0mm
TP7: TP_RST; TestPoint_Pad_D1.0mm
TP8: TP_-5V; TestPoint_Pad_D1.0mm
TP9, TP10: TP_IOUTP; TestPoint_Pad_D1.0mm
TP11: TP_INTERM; TestPoint_Pad_D1.0mm
TP12: TP_OUT; TestPoint_Pad_D1.0mm
U1: AD9102BCPZRL7; CP-32-12_ADI
U3: ADA4817-1ACP; LFCSP-8-1EP_3x3mm_P0.5mm_EP1.45x1.74mm
U4: THS3091DDAR; VREG_LM5017MR_NOPB
U5: SOT-363_SC-70-6
X1: OB3225125MLDB6SI-00; Oscillator_SMD_SiTime_PQFD-6L_3.2x2.5mm

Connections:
+3V3: C3.2, C11.2, C12.2, C13.2, C14.2, C15.2, C16.2, C17.2, C18.2, D2.2 (A), D3.2 (A), J1.20, R1.1, R2.1, R3.1, R8.1, TP3.1, U1.5 (DVDD), U1.12 (AVDD2), U1.23 (CLKVDD), U1.29 (AVDD1), X1.1 (OE), X1.6 (VDD)
+5V: C21.2, C22.2, C27.2, C28.2, C29.2, J1.17, TP4.1, U3.1 (~PD), U3.8 (+V_{S}), U4.7 (VS+), U5.3 (/SHDN), U5.4 (IN)
-5V: C20.2, C23.2, C24.2, C30.2, C31.2, TP8.1, U3.5 (-V_{S}), U4.4 (VS-), U5.1 (OUT)
/+IN: C25.2, R13.1, R15.2, U3.4 (+)
/-IN: C26.2, R14.1, R16.2, U3.3 (-)
/AMPL_VIN+: J2.1 (In), J4.2, JP3.1 (A), R18.2, U4.3 (VIN+)
/AMPL_VIN-: R19.1, RV1.2, RV1.3, U4.2 (VIN-)
/AMPL_VOUT: J6.2, R22.1, TP12.1, U4.6 (VOUT)
/CLKLDO: C9.2, C10.2, U1.22 (CLDO)
/CSn: J1.8, R3.2, U1.8 (*CS)
/FB: C26.1, R16.1, U3.2 (FB)
/INTERM: R17.2, R18.1, TP11.1, U3.7
/IOUTN: R12.2, R14.2, TP10.1, U1.28 (IOUTN)
/IOUTP: R11.1, R13.2, TP9.1, U1.27 (IOUTP)
/LDO1: C4.2, C5.2, U1.6 (DLDO1)
/LDO2: C6.2, C7.2, U1.4 (DLDO2)
/MISO: J1.6, U1.7 (SDO/SDI2/DOUT)
/MOSI: J1.12, U1.2 (SDIO)
/OUT: J3.1 (In), J5.2, R20.1, R23.1
/REFIO: C8.2, R6.2, U1.18 (REFIO)
/RSTn: J1.7, R1.2, R9.2, TP7.1, U1.9 (*RESET)
/SCK: J1.10, U1.1 (SCLK)
/TRIG: J1.9, R2.2, R10.2, TP6.1, U1.32 (*TRIGGER)
GND: C3.1, C4.1, C5.1, C6.1, C7.1, C8.1, C9.1, C10.1, C11.1, C12.1, C13.1, C14.1, C15.1, C16.1, C17.1, C18.1, C20.1, C21.1, C22.1, C23.1, C24.1, C25.1, C27.1, C28.1, C29.1, C30.1, C31.1, D1.1 (K), J1.19, J2.2 (Ext), J3.2 (Ext), J4.1, J5.1, J7.1 (In), J7.2 (Ext), R5.2, R7.2, R11.2, R12.1, R15.1, R17.1, R19.2, R21.1, TP2.1, U1.3 (DGND), U1.15 (AGND), U1.19 (CLKGND), U1.26 (AGND), U1.33 (EPAD), U3.9 (EP), U4.9 (POWER_PAD), U5.2 (GND), X1.3 (GND)
unnamed: D1.2 (A), R8.2
unnamed: D2.1 (K), R9.1
unnamed: D3.1 (K), R10.1
unnamed: J6.1, R23.2
unnamed: J6.3, R20.2
unnamed: JP1.1 (A), R7.1, U1.24 (CAL_SENSE)
unnamed: JP1.2 (B), R5.1, U1.25 (FSADJ)
unnamed: JP3.2 (B), R21.2
unnamed: R6.1, TP1.1
unnamed: R22.2, RV1.1
unnamed: C2.2, U1.20 (CLKN)
unnamed: C1.2, U1.21 (CLKP)
unnamed: C19.2, U5.6 (C1+)
unnamed: C19.1, U5.5 (C1-)
unnamed: C1.1, R4.1, X1.4 (OUT+)
unnamed: C2.1, R4.2, X1.5 (OUT-)
VCC: J1.18, TP5.1

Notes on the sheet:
REFIO = 1.04V +- 20%
V = +-4mA * (120Ω + 560Ω) + 2.5mA * (560Ω - 120Ω) = -1.6V / + 3.8V
I = V_INTERM * (1 + (R12 + RV1) / R9) / 50Ω = V_INTERM * [2, 4] / 50Ω
Crystal Oscilator LVDS config

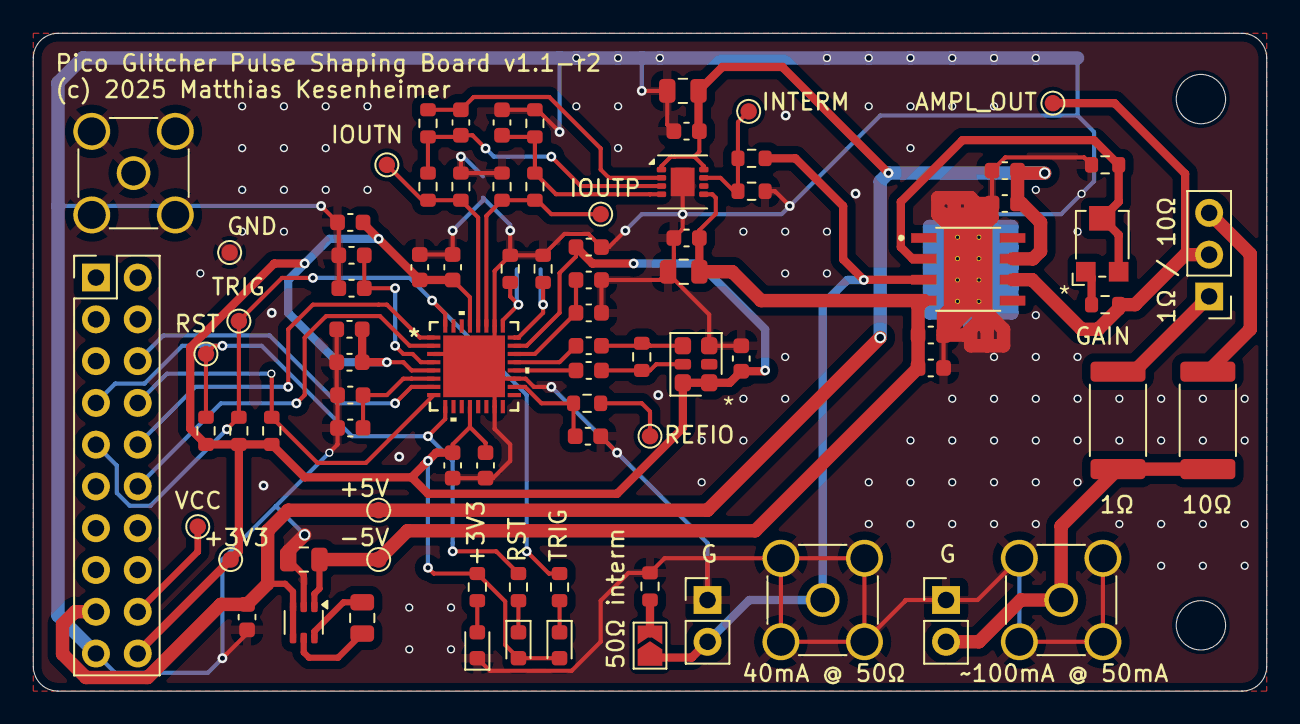
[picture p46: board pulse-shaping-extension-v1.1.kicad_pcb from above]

Board: 2 copper layers, 75.0 x 40.0 mm, 86 parts (1 on the bottom side), 41 nets.

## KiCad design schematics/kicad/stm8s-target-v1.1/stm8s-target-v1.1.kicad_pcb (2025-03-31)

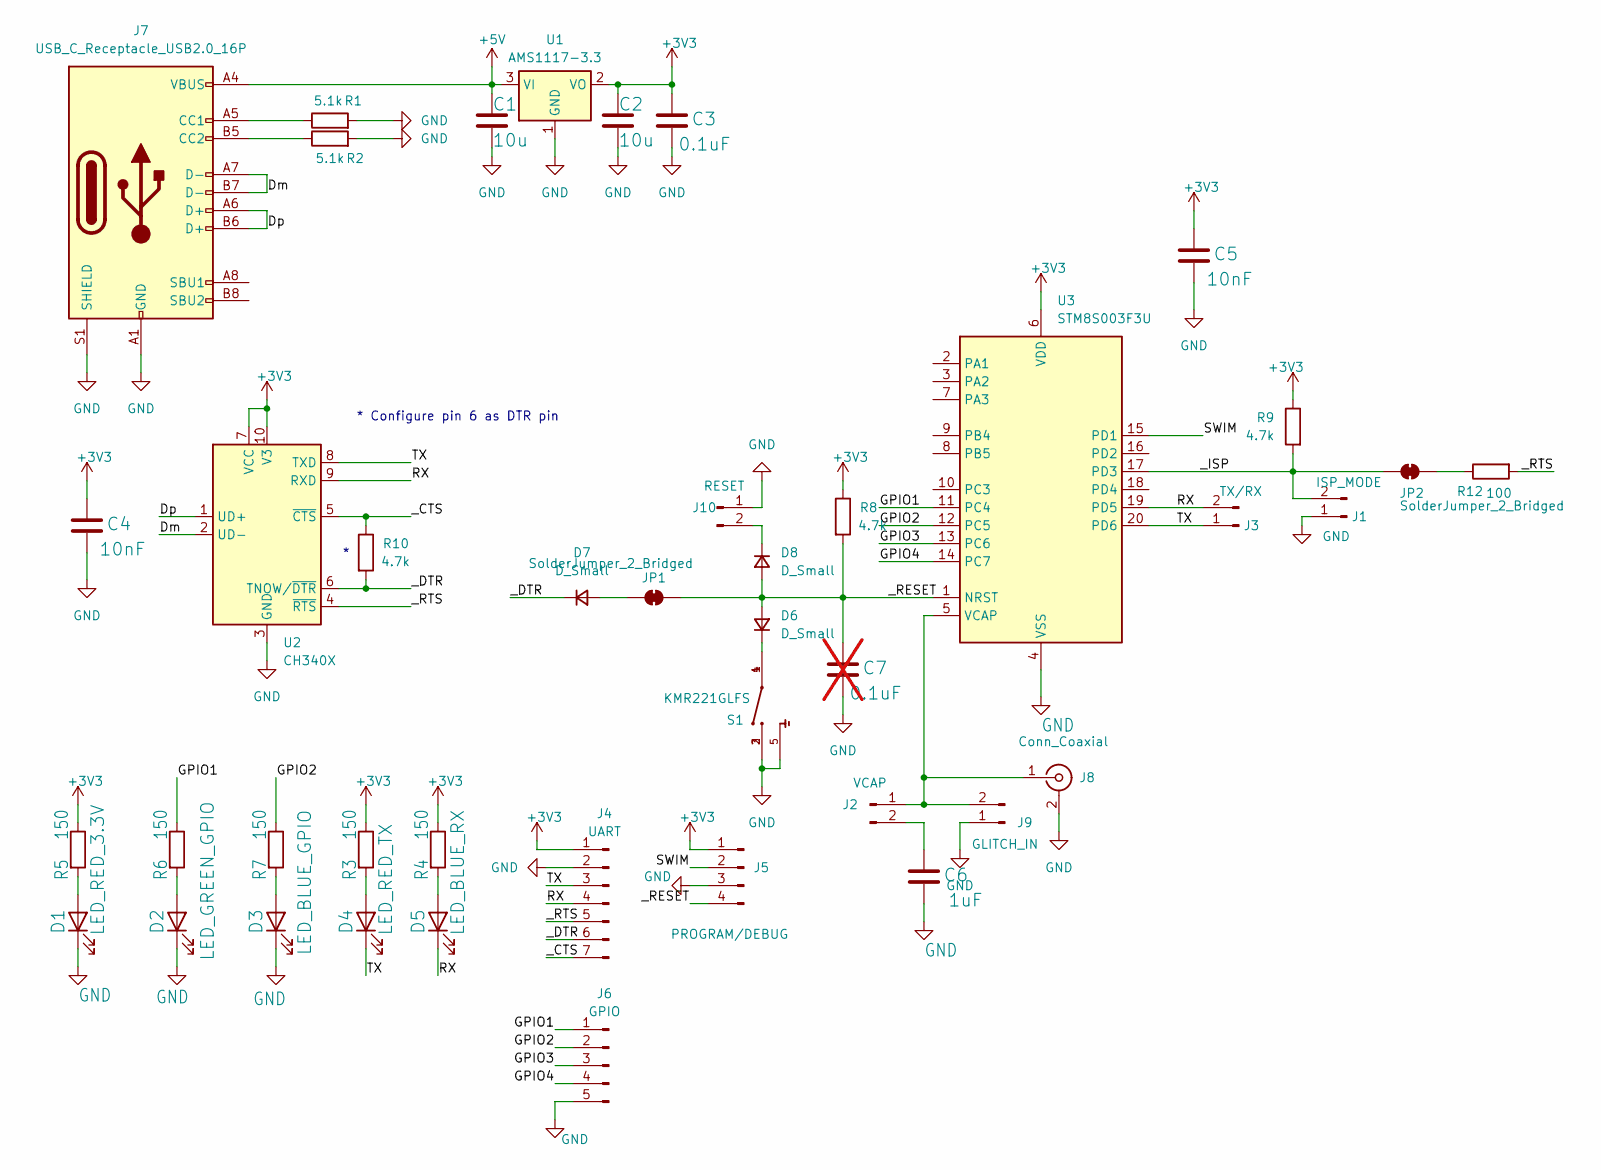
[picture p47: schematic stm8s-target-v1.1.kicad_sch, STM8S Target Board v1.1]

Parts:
C1, C2: 10u; C_0805_2012Metric
C3: 0.1uF; C_0603_1608Metric
C4, C5: 10nF; C_0603_1608Metric
C6: 1uF; C_0603_1608Metric
C7: 0.1uF; C_0603_1608Metric; not fitted
D1: LED_RED_3.3V; LED_0603_1608Metric
D2: LED_GREEN_GPIO; LED_0603_1608Metric
D3: LED_BLUE_GPIO; LED_0603_1608Metric
D4: LED_RED_TX; LED_0603_1608Metric
D5: LED_BLUE_RX; LED_0603_1608Metric
D6, D7, D8: D_Small; D_SOD-323
J1: ISP_MODE; PinHeader_1x02_P2.54mm_Vertical
J2: VCAP; PinHeader_1x02_P2.54mm_Vertical
J3: TX/RX; PinHeader_1x02_P2.54mm_Vertical
J4: UART; PinHeader_1x07_P2.54mm_Vertical
J5: PROGRAM/DEBUG; PinHeader_1x04_P2.54mm_Vertical
J6: GPIO; PinHeader_1x05_P2.54mm_Vertical
J7: USB_C_Receptacle_USB2.0_16P; USB_C_Receptacle_HRO_TYPE-C-31-M-12
J8: Conn_Coaxial; SMA_Amphenol_901-144_Vertical
J9: GLITCH_IN; PinHeader_1x02_P2.54mm_Vertical
J10: RESET; PinHeader_1x02_P2.54mm_Vertical
JP1, JP2: SolderJumper_2_Bridged; SolderJumper-2_P1.3mm_Bridged_RoundedPad1.0x1.5mm
R1, R2: 5.1k; R_0603_1608Metric
R3, R4, R5, R6, R7: 150; R_0603_1608Metric
R8, R9, R10: 4.7k; R_0603_1608Metric
R12: 100; R_0603_1608Metric
S1: KMR221GLFS; SW_KMR221GLFS
U1: AMS1117-3.3; SOT-223-3_TabPin2
U2: CH340X; MSOP-10_3x3mm_P0.5mm
U3: STM8S003F3U; ST_UFQFPN-20_3x3mm_P0.5mm

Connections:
+3V3: C2.1, C3.2, C4.2, C5.2, J4.1, J5.1, R3.1, R4.1, R5.1, R8.1, R9.1, U1.2 (VO), U2.7 (VCC), U2.10 (V3), U3.6 (VDD)
+5V: C1.1, J7.A4 (VBUS), J7.A9 (VBUS), J7.B4 (VBUS), J7.B9 (VBUS), U1.3 (VI)
/Dm: J7.A7 (D-), J7.B7 (D-), U2.2 (UD-)
/Dp: J7.A6 (D+), J7.B6 (D+), U2.1 (UD+)
/GPIO1: J6.1, R6.1, U3.11 (PC4)
/GPIO2: J6.2, R7.1, U3.12 (PC5)
/GPIO3: J6.3, U3.13 (PC6)
/GPIO4: J6.4, U3.14 (PC7)
/RX: D5.1 (K), J3.2, J4.4, U2.9 (RXD), U3.19 (PD5)
/SWIM: J5.2, U3.15 (PD1)
/TX: D4.1 (K), J3.1, J4.3, U2.8 (TXD), U3.20 (PD6)
/_CTS: J4.7, R10.1, U2.5 (~CTS)
/_DTR: D7.1 (K), J4.6, R10.2, U2.6 (TNOW/~DTR)
/_ISP: J1.2, JP2.2 (B), R9.2, U3.17 (PD3)
/_RESET: C7.2, D6.2 (A), D8.2 (A), J5.4, JP1.2 (B), R8.2, U3.1 (NRST)
/_RTS: J4.5, R12.2, U2.4 (~RTS)
GND: C1.2, C2.2, C3.1, C4.1, C5.1, C6.1, C7.1, D1.1 (K), D2.1 (K), D3.1 (K), J1.1, J4.2, J5.3, J6.5, J7.A1 (GND), J7.A12 (GND), J7.B1 (GND), J7.B12 (GND), J7.S1 (SHIELD), J8.2 (Ext), J9.1, J10.1, R1.2, R2.2, S1.2, S1.3, S1.5, U1.1 (GND), U2.3 (GND), U3.4 (VSS)
unnamed: D1.2 (A), R5.2
unnamed: D2.2 (A), R6.2
unnamed: D3.2 (A), R7.2
unnamed: D4.2 (A), R3.2
unnamed: D5.2 (A), R4.2
unnamed: D6.1 (K), S1.1, S1.4
unnamed: D7.2 (A), JP1.1 (A)
unnamed: D8.1 (K), J10.2
unnamed: J2.1, J8.1 (In), J9.2, U3.5 (VCAP)
unnamed: C6.2, J2.2
unnamed: J7.A5 (CC1), R1.1
unnamed: J7.B5 (CC2), R2.1
unnamed: JP2.1 (A), R12.1

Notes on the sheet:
* Configure pin 6 as DTR pin

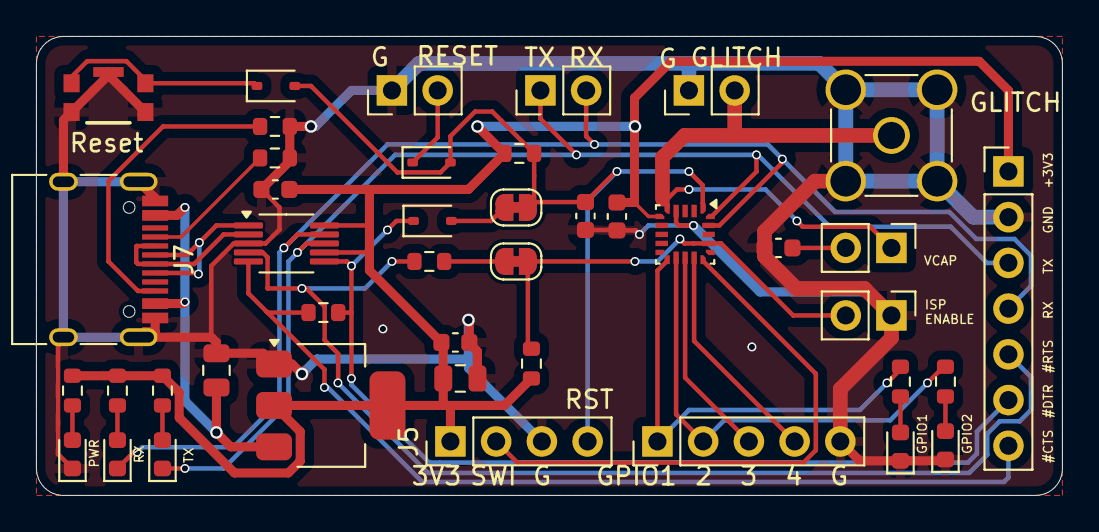
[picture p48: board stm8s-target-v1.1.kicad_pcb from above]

Board: 2 copper layers, 57.0 x 25.5 mm, 42 parts (0 on the bottom side), 30 nets.

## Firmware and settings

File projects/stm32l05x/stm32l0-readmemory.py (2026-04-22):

#!/usr/bin/env python3
# Copyright (C) 2024 Dr. Matthias Kesenheimer - All Rights Reserved.
# You may use, distribute and modify this code under the terms of the GPL3 license.
#
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
# SQL Queries:
# Show only successes and flash-resets:
# color = 'R' or response LIKE '_Warning.flash_reset'

import argparse
import logging
import random
import sys
import time

# import custom libraries
from findus.STM32Bootloader import STM32Bootloader
from findus import Database, PicoGlitcher, Helper, ErrorHandling
from findus.DebugInterface import DebugInterface

class DerivedPicoGlitcher(PicoGlitcher):
    @staticmethod
    def classify(state:bytes) -> str:
        color = 'C'
        if b'expected' in state:
            color = 'G'
        elif b'ok' in state:
            color = 'C'
        elif b'error: write number of bytes to read failed' in state:
            color = 'C'
        elif b'error' in state:
            color = 'M'
        elif b'failure' in state:
            color = 'B'
        elif b'timeout' in state:
            color = 'Y'
        elif b'warning' in state:
            color = 'O'
        elif b'success' in state:
            color = 'R'
        return color

class Main:
    def __init__(self, args):
        self.args = args

        # logging
        logging.basicConfig(filename="execution.log", filemode="a", format="%(asctime)s %(message)s", level=logging.INFO, force=True)

        # glitcher
        self.glitcher = DerivedPicoGlitcher()
        # if argument args.power is not provided, the internal power-cycling capabilities of the pico-glitcher will be used. In this case, ext_power_voltage is not used.
        self.glitcher.init(port=args.rpico, ext_power=args.power, ext_power_voltage=3.3)
        self.glitcher.set_cpu_frequency(300_000_000)

        # we want to trigger on x11 with the configuration 8e1
        # since our statemachine understands only 8n1,
        # we can trigger on x22 with the configuration 9n1 instead
        # Update: Triggering on x11 in configuration 8n1 works good enough.
        self.glitcher.uart_trigger(0x11)

        # choose pulse-shaping or crowbar glitching and set up the database
        if args.pulse_shaping:
            self.v_init = self.args.vinit
            self.glitcher.set_pulseshaping(vinit=self.v_init)
            self.database = Database(sys.argv, resume=self.args.resume, nostore=self.args.no_store, column_names=["delay", "length", "v_init", "v_intermediate"])
        elif args.delay2 is not None and args.length2 is not None:
            self.glitcher.set_lpglitch()
            self.database = Database(sys.argv, resume=self.args.resume, nostore=self.args.no_store, column_names=["delay", "length", "delay2", "length2"])
        else:
            self.glitcher.set_lpglitch()
            self.database = Database(sys.argv, resume=self.args.resume, nostore=self.args.no_store, column_names=["delay", "length", "number_of_pulses", "delay_between"])
        self.start_time = int(time.time())

        # STLink Debugger
        self.debugger = DebugInterface(interface_config="interface/stlink.cfg", transport="hla_swd", target="stm32l0")

        # programming the target
        if args.program_target is not None:
            print("[+] Programming target.")
            self.debugger.program_target(glitcher=self.glitcher, elf_image="toggle-led-stm32l051.elf", unlock=True,  rdp_level=args.program_target, verbose=True)

        # memory read settings
        self.bootcom = STM32Bootloader(port=self.args.target, serial_timeout=0.1, dump_address=0x08000000, dump_len=0x2000)
        self.dump_filename = f"{Helper.timestamp()}_memory_dump.bin"

        # error handling
        self.error_handler = ErrorHandling(max_fails=15, look_back=20, database=self.database)
        self.error_handler2 = ErrorHandling(max_fails=1500, look_back=1500, database=self.database)

    def cleanup(self):
        print("[+] Cleaning up.")
        self.debugger.detach()

    def run(self):
        # log execution
        logging.info(" ".join(sys.argv))

        s_delay = self.args.delay[0]
        e_delay = self.args.delay[1]
        s_length = self.args.length[0]
        e_length = self.args.length[1]

        if args.pulse_shaping:
            s_v_intermediate = self.args.vintermediate[0]
            e_v_intermediate = self.args.vintermediate[1]
        elif self.args.delay2 is not None and self.args.length2 is not None:
            s_delay2 = self.args.delay2[0]
            e_delay2 = self.args.delay2[1]
            s_length2 = self.args.length2[0]
            e_length2 = self.args.length2[1]
        else:
            s_delay_between = self.args.delay_between[0]
            e_delay_between = self.args.delay_between[1]
            s_number_of_pulses = self.args.number_of_pulses[0]
            e_number_of_pulses = self.args.number_of_pulses[1]

        experiment_id = 0
        while True:
            # flush garbage
            self.bootcom.flush()

            # trigger on read-memory command
            self.glitcher.uart_trigger(0x11)

            # set up glitch parameters (in nano seconds) and arm glitcher
            delay = random.randint(s_delay, e_delay)
            length = random.randint(s_length, e_length)
            if self.args.delay2 is not None and self.args.length2 is not None:
                delay2 = random.randint(s_delay2, e_delay2)
                length2 = random.randint(s_length2, e_length2)

            # dummy variables (not all are used in each case)
            v_intermediate = 0
            delay_between = 0
            number_of_pulses = 0
            if args.pulse_shaping:
                v_intermediate = Helper.random_point(s_v_intermediate, e_v_intermediate, 0.05, dtype=float)
                ps_lambda = f"lambda t:{v_intermediate} if t<{length} else {self.v_init}"
                self.glitcher.arm_pulseshaping_from_lambda(delay, ps_lambda, 2*length)
            elif self.args.delay2 is not None and self.args.length2 is not None:
                # the second glitch with delay2 and length2 is done further below
                self.glitcher.arm(delay, length)
            else:
                delay_between = random.randint(s_delay_between, e_delay_between)
                number_of_pulses = random.randint(s_number_of_pulses, e_number_of_pulses)
                self.glitcher.arm(delay, length, number_of_pulses, delay_between)

            # reset target
            self.glitcher.reset(0.01)
            time.sleep(0.01)

            # setup bootloader communication
            state = self.bootcom.init_bootloader()
            # setup memory read; this function triggers the glitch
            if b'ok' in state:
                state = self.bootcom.setup_memread()

            # block until glitch
            try:
                self.glitcher.block(timeout=0.2)
            except Exception as _:
                print("[-] Timeout received in block(). Continuing.")
                self.glitcher.power_cycle_reset()
                time.sleep(0.2)
                state = b'warning: timeout'

            # dump memory
            mem = b''
            if b'success' in state:
                # this triggers the second glitch (if requested)
                #state, mem = self.bootcom.dump_memory_to_file(self.dump_filename)
                #start = 0x08000000
                start = 0x08000000 - 0*0xFF
                size = 0xFF

                # arm for the second time and trigger on 0xff (size of memory to read)
                if not args.pulse_shaping and self.args.delay2 is not None and self.args.length2 is not None:
                    self.glitcher.uart_trigger(size)
                    self.glitcher.arm(delay2, length2)

                state, mem = self.bootcom.read_memory(start, size)

                # block until glitch
                if not args.pulse_shaping and self.args.delay2 is not None and self.args.length2 is not None:
                    try:
                        self.glitcher.block(timeout=1)
                    except Exception as _:
                        print("[-] Timeout received in block(). Continuing.")
                        self.glitcher.power_cycle_reset()
                        time.sleep(0.2)
                        state = b'warning: timeout (glitch2)'

                # DEBUG (to easily find the glitch with a logic analyzer)
                time.sleep(1)
                if mem != b'\x1f' and mem != b'\x79' and mem != b'':
                    time.sleep(4)

            # classify state
            color = self.glitcher.classify(state)

            # add to database
            state_str = b"state = " + state + b", mem = " + mem
            if args.pulse_shaping:
                self.database.insert(experiment_id, delay, length, self.v_init, v_intermediate, color, state_str)
            elif self.args.delay2 is not None and self.args.length2 is not None:
                self.database.insert(experiment_id, delay, length, delay2, length2, color, state_str)
            else:
                self.database.insert(experiment_id, delay, length, number_of_pulses, delay_between, color, state_str)

            # monitor
            speed = self.glitcher.get_speed(self.start_time, experiment_id)
            experiment_base_id = self.database.get_base_experiments_count()
            if args.pulse_shaping:
                print(self.glitcher.colorize(f"[+] Experiment {experiment_id}\t{experiment_base_id}\t({speed})\t{delay}\t{length}\t{self.v_init}\t{v_intermediate}\t{color}\t{state}", color))
            elif self.args.delay2 is not None and self.args.length2 is not None:
                print(self.glitcher.colorize(f"[+] Experiment {experiment_id}\t{experiment_base_id}\t({speed})\t{delay}\t{length}\t{delay2}\t{length2}\t{color}\t{state}", color))
            else:
                print(self.glitcher.colorize(f"[+] Experiment {experiment_id}\t{experiment_base_id}\t({speed})\t{delay}\t{length}\t{number_of_pulses}\t{delay_between}\t{color}\t{state}", color))

            # check for successive errors, re-programm target if too many successive errors occur.
            def error_action():
                # reprogram target and try again
                self.glitcher.power_cycle_target(1)
                time.sleep(1)
                self.bootcom.flush()
                # reprogram the target
                print("[+] Programming target.")
                self.debugger.program_target(glitcher=self.glitcher, elf_image="toggle-led-stm32l051.elf", unlock=True,  rdp_level=1, verbose=True)
                self.glitcher.power_cycle_target(1)
            self.error_handler.check(experiment_id=experiment_id, response=state, expected=b'expected', keep=[b'success', b'failure'], recolor='O', user_action=error_action)
            # if no errors occur at all (only expected), there might be something different wrong:
            def error_action2():
                print("[+] Glitch may be in the wrong position. Stop.")
                sys.exit(-1)
            self.error_handler2.check(experiment_id=experiment_id, response=state, expected=b'error', keep=[b'ok', b'success', b'failure'], recolor='O', user_action=error_action2)  

            # increase experiment id
            experiment_id += 1

            # Dump finished
            if state == b'success: dump finished':
                break

if __name__ == "__main__":
    parser = argparse.ArgumentParser()
    parser.add_argument("--target", required=False, help="target port", default="/dev/ttyUSB1")
    parser.add_argument("--rpico", required=False, help="rpico port", default="/dev/ttyUSB2")
    parser.add_argument("--power", required=False, help="rk6006 port", default=None)
    parser.add_argument("--delay", required=True, nargs=2, help="delay start and end", type=int)
    parser.add_argument("--length", required=True, nargs=2, help="length start and end", type=int)
    parser.add_argument("--delay2", required=False, nargs=2, help="second pulse delay start and end, relative to the first glitch", type=int, default=None)
    parser.add_argument("--length2", required=False, nargs=2, help="second pulse length start and end", type=int, default=None)
    parser.add_argument("--delay-between", required=False, nargs=2, help="delay between pulses for crowbar burst-glitching", type=int, default=[0, 0])
    parser.add_argument("--number-of-pulses", required=False, nargs=2, help="number of pulses pulses for crowbar burst-glitching (can also be 1 for single-crowbar glitching)", type=int, default=[1, 1])
    parser.add_argument("--pulse-shaping", required=False, action='store_true', help="Instead of crowbar glitching, perform a fault injection with a predefined voltage profile (requires PicoGlitcher v2).")
    parser.add_argument("--vinit", required=False, help="Initial voltage for pulse shaping", type=float, default=3.3)
    parser.add_argument("--vintermediate", required=False, nargs=2, help="Intermediate voltage for pulse shaping", type=float, default=[2.0, 2.5])
    parser.add_argument("--resume", required=False, action='store_true', help="if an previous dataset should be resumed")
    parser.add_argument("--no-store", required=False, action='store_true', help="do not store the run in the database")
    parser.add_argument("--trigger-input", required=False, default="default", help="The trigger input to use (default, alt, ext1, ext2). The inputs ext1 and ext2 require the PicoGlitcher v2.")
    parser.add_argument("--program-target", required=False, metavar="RDP_LEVEL", type=int, default=None, help="Reprogram the target before glitching and set the RDP level.")
    args = parser.parse_args()

    main = Main(args)

    try:
        main.run()
    except KeyboardInterrupt:
        print("\nExitting...")
        main.cleanup()
        sys.exit(1)

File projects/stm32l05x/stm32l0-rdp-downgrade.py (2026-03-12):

#!/usr/bin/env python3
# Copyright (C) 2024 Dr. Matthias Kesenheimer - All Rights Reserved.
# You may use, distribute and modify this code under the terms of the GPL3 license.
#
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
# SQL Queries:
# Show only successes and flash-resets:
# color = 'R' or response LIKE '_Warning.flash_reset'

# connections
# - UART TX: Pin 19 (PA9)
# - UART RX: Pin 20 (PA10)
# - SWDIO: Pin 23 (PA13)
# - SWDCLK: Pin 24 (PA14)
# - LED ERROR: Pin 2 (PC14)
# - LED OK: Pin 3 (PC15)
# - TRIGGER: Pin 22 (PA12)

import argparse
import logging
import random
import sys
import time

# import custom libraries
from findus import DebugInterface, Database, PicoGlitcher, Helper

elf_image = "rdp-downgrade-stm32l051.elf"
#elf_image = "dma-uart-stm32l051.elf"

class DerivedDebugInterface(DebugInterface):
    def characterize(self, response:str, mem:int):
        # possibly ok
        if mem is not None:
            if mem != 0x00 and mem != 0xffffffff:
                return b'success: RDP inactive'
            else:
                return b'expected: read empty flash'
        # Error: no connection
        elif "Error: init mode failed (unable to connect to the target)" in response:
            return b'error: no connection'
        # Warning: Polling failed
        elif "Polling target" in response:
            return b'warning: polling failed'
        # Warning: Device lockup
        if "clearing lockup after double fault" in response:
            return b'warning: lock-up'
        # Warning: else
        elif "Warning" in response:
            return b'warning: default warning'
        # expected state
        elif "Error: Failed to read memory at" in response:
            return b'expected: RDP active'
        # no response
        return b'error: no response'

class Main:
    def __init__(self, args):
        self.args = args

        # logging
        logging.basicConfig(filename="execution.log", filemode="a", format="%(asctime)s %(message)s", level=logging.INFO, force=True)

        # glitcher
        self.glitcher = PicoGlitcher()
        # if argument args.power is not provided, the internal power-cycling capabilities of the pico-glitcher will be used. In this case, ext_power_voltage is not used.
        self.glitcher.init(port=args.rpico, ext_power=args.power, ext_power_voltage=3.3)

        # if target is powered with external power supply, the power-cycle time must be increased
        self.power_cycle_time = 0.05
        if args.power is not None:
            self.power_cycle_time = 0.5
            self.ext_power_supply = self.glitcher.get_power_supply()

        # trigger on the rising edge of the reset signal
        self.glitcher.rising_edge_trigger(pin_trigger=args.trigger_input)

        # choose pulse-shaping or crowbar glitching and set up the database
        if args.pulse_shaping:
            self.v_init = self.args.vinit
            self.glitcher.set_pulseshaping(vinit=self.v_init)
            self.database = Database(sys.argv, resume=self.args.resume, nostore=self.args.no_store, column_names=["delay", "length", "v_init", "v_intermediate"])
        elif args.delay2 is not None and args.length2 is not None:
            self.glitcher.set_hpglitch()
            self.database = Database(sys.argv, resume=self.args.resume, nostore=self.args.no_store, column_names=["delay", "length", "delay2", "length2"])
        else:
            self.glitcher.set_hpglitch()
            self.database = Database(sys.argv, resume=self.args.resume, nostore=self.args.no_store, column_names=["delay", "length", "number_of_pulses", "delay_between"])
        self.start_time = int(time.time())

        # STLink Debugger
        #self.debugger = DerivedDebugInterface(interface="stlink", target="stm32l0", transport="hla_swd", gdb_exec="gdb-multiarch")
        self.debugger = DerivedDebugInterface(interface_config="interface/stlink.cfg", target="stm32l0", transport="hla_swd", adapter_serial=args.stlink_serial)

        # programming the target
        if args.test and args.program_target is not None:
            print("[+] Programming target.")
            if args.power is not None:
                self.ext_power_supply.set_voltage(3.3)
            self.debugger.program_target(glitcher=self.glitcher, elf_image="toggle-led-stm32l051.elf", unlock=True, rdp_level=args.program_target, power_cycle_time=self.power_cycle_time, verbose=True)

    def cleanup(self):
        self.debugger.detach()

    def is_programming_necessary(self):
        programming_necessary = False
        unlock_necessary = False
        # check if target needs to be programmed
        rdp, pcrop = self.debugger.read_rdp_and_pcrop(verbose=False)
        print(f"[+] Option bytes: rdp = {hex(rdp)}, pcrop = {hex(pcrop)}")
        if rdp == 0xaa or rdp == 0xcc:
            programming_necessary = True
            unlock_necessary = False
        elif pcrop != 0x00:
            programming_necessary = True
            unlock_necessary = True
        return programming_necessary, unlock_necessary

    def prepare_target(self):
        print("[+] Preparing target.")
        programming_necessary, unlock_necessary = self.is_programming_necessary()
        #print(f"[+] Is programming necessary? programming_necessary = {programming_necessary}, unlock_necessary = {unlock_necessary}")
        # write a program to the target and enable RDP level 1
        # unlock should not be necessary, since RDP level should be zero from the last experiment
        # if RDP is already level 1, we don't care and continue
        # steps:
        # - init; halt; program {elf_image}; run; exit
        # - init; halt; {self.processor_name}x lock 0; exit
        # - reset and power-cycle
        if programming_necessary:
            if self.args.power is not None:
                self.ext_power_supply.set_voltage(3.3)
            print("[+] Warning: rdp or pcrop not as expected. Programming target with test program (to flash) and enabling rdp level 1.")
            self.debugger.program_target(glitcher=self.glitcher, elf_image="toggle-led-stm32l051.elf", unlock=unlock_necessary, rdp_level=1, power_cycle_time=self.power_cycle_time, verbose=True)

        # check if programming was successful (RDP should be active)
        rdp, pcrop = self.debugger.read_rdp_and_pcrop(verbose=False)
        success = (rdp != 0xaa and rdp != 0xcc) and pcrop == 0x00
        print(f"[+] Result whether programming was successful: {"ok" if success else "failed"}, (rdp = {rdp}, pcrop = {pcrop})")
        if not success:
            raise Exception("Programming failed.")
        print("[+] Programming finished.")
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

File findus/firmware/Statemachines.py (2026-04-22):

# Copyright (C) 2024 Dr. Matthias Kesenheimer - All Rights Reserved.
# You may use, distribute and modify this code under the terms of the GPL3 license.
#
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
from rp2 import asm_pio, PIO
import Globals

@asm_pio(set_init=(PIO.OUT_LOW), sideset_init=(PIO.OUT_LOW))
def glitch():
    # block until delay received
    pull(block)
    mov(x, osr)
    # block until length received
    pull(block)
    mov(y, osr)

    # wait for trigger condition
    # enable pin_glitch_en
    wait(1, irq, 1).side(0b1)
    # set irq0 which starts the adc callback (if enabled)
    irq(0)

    # wait delay
    label("delay_loop")
    jmp(x_dec, "delay_loop")

    # emit glitch at base pin
    set(pins, 0b1)
    label("length_loop")       
    jmp(y_dec, "length_loop")

    # stop glitch and disable pin_glitch_en
    set(pins, 0b0).side(0b0)

    # tell execution finished (fills the sm's fifo buffer)
    push(block)

@asm_pio(set_init=(PIO.OUT_LOW), sideset_init=(PIO.OUT_LOW), out_shiftdir=PIO.SHIFT_RIGHT)
def glitch_burst():
    # block until delay received
    pull(block)
    mov(x, osr)
    # block until pulse config (length and delay between pulses) received, backup in isr
    pull(block)
    mov(isr, osr)
    # block until number of pulses received
    pull(block)
    mov(y, osr)

    # wait for trigger condition
    # enable pin_glitch_en
    wait(1, irq, 1).side(0b1)
    # set irq0 which starts the adc callback (if enabled)
    irq(0)

    # delay until first glitch
    label("delay_loop")
    jmp(x_dec, "delay_loop")

    # emit a certain number of glitches
    label("burst_loop")

    # copy config into osr
    mov(osr, isr)
    out(x, 16) # length = OSR >> 16

    # emit glitch
    set(pins, 0b1)
    label("length_loop")       
    jmp(x_dec, "length_loop")
    set(pins, 0b0)

    # wait until next glitch
    out(x, 16) # delay = OSR >> 16
    label("delay2_loop")       
    jmp(x_dec, "delay2_loop")

    jmp(y_dec, "burst_loop")

    # reset glitch_en
    set(pins, 0b0).side(0b0)

    # tell execution finished (fills the sm's fifo buffer)
    push(block)

@asm_pio(set_init=(PIO.OUT_LOW), sideset_init=(PIO.OUT_LOW), out_shiftdir=PIO.SHIFT_RIGHT)
def glitch_multiple():
    # block until number of pulses received
    pull(block)
    mov(y, osr)
    
    # wait for trigger condition
    # enable pin_glitch_en
    wait(1, irq, 1).side(0b1)
    # set irq0 which starts the adc callback (if enabled)
    irq(0)

    # emit multiple glitches given by each config
    label("glitch_loop")

    # block until first config is received
    pull(block)
    out(x, 22) # delay = OSR >> 22

    # delay until first glitch
    label("delay_loop")
    jmp(x_dec, "delay_loop")

    # get the length
    out(x, 10) # length = OSR >> 10

    # emit glitch at base pin
    set(pins, 0b1)
    label("length_loop")       
    jmp(x_dec, "length_loop")
    set(pins, 0b0)

    jmp(y_dec, "glitch_loop")

    # stop glitch and disable pin_glitch_en
    set(pins, 0b0).side(0b0)

    # tell execution finished (fills the sm's fifo buffer)
    push(block)

@asm_pio(set_init=(PIO.OUT_HIGH), sideset_init=(PIO.OUT_LOW))
def pulse_shaping():
    # block until delay received
    pull(block)
    mov(x, osr)
    # block until total length of pulse received
    pull(block)
    mov(y, osr)

    # wait for trigger condition
    # enable pin_glitch_en
    wait(1, irq, 1).side(0b1)
    # set irq0 which starts the adc callback (if enabled)
    irq(0)

    # wait delay
    label("delay_loop")
    jmp(x_dec, "delay_loop")

    # set trigger pin low (start pulse generator)
    set(pins, 0b0)
    label("length_loop")
    jmp(y_dec, "length_loop")

    # stop pulse and disable pin_glitch_en
    set(pins, 0b1).side(0b0)

    # tell execution finished (fills the sm's fifo buffer)
    push(block)

@asm_pio(set_init=(Globals.MUX1_PIO_INIT, Globals.MUX0_PIO_INIT), out_init=(Globals.MUX1_PIO_INIT, Globals.MUX0_PIO_INIT), sideset_init=(PIO.OUT_LOW), out_shiftdir=PIO.SHIFT_RIGHT)
def multiplex(MUX_PIO_INIT=Globals.MUX_PIO_INIT):
    # block until delay received
    pull(block)
    mov(x, osr)

    # wait for trigger condition
    # enable pin_glitch_en
    wait(1, irq, 1).side(0b1)
    # set irq0 which starts the adc callback (if enabled)
    irq(0)

    # wait delay
    label("delay_loop")
    jmp(x_dec, "delay_loop")

    # do the following two times
    set(x, 1)
    label("for_loop")

    # block until config received
    pull(block)
    out(pins, 2)
    out(y, 14) # t = OSR >> 14
    label("t1_loop")
    jmp(y_dec, "t1_loop")

    out(pins, 2)
    out(y, 14) # t = OSR >> 14
    label("t2_loop")
    jmp(y_dec, "t2_loop")

    # for loop
    jmp(x_dec, "for_loop")

    # reset and disable pin_glitch_en
    set(pins, MUX_PIO_INIT).side(0b0)

    # tell execution finished (fills the sm's fifo buffer)
    push(block)

@asm_pio(set_init=(PIO.OUT_LOW, PIO.OUT_LOW), out_init=(PIO.OUT_LOW, PIO.OUT_LOW), sideset_init=(PIO.OUT_LOW), out_shiftdir=PIO.SHIFT_RIGHT)
def multiplex_vin1(MUX_PIO_INIT=0b00):
    # block until delay received
    pull(block)
    mov(x, osr)

    # wait for trigger condition
    # enable pin_glitch_en
    wait(1, irq, 1).side(0b1)
    # set irq0 which starts the adc callback (if enabled)
    irq(0)

    # wait delay
    label("delay_loop")
    jmp(x_dec, "delay_loop")

    # do the following two times
    set(x, 1)
    label("for_loop")

    # block until config received
    pull(block)
    out(pins, 2)
    out(y, 14) # t = OSR >> 14
    label("t1_loop")
    jmp(y_dec, "t1_loop")

    out(pins, 2)
    out(y, 14) # t = OSR >> 14
    label("t2_loop")
    jmp(y_dec, "t2_loop")

    # for loop
    jmp(x_dec, "for_loop")

    # reset and disable pin_glitch_en
    set(pins, MUX_PIO_INIT).side(0b0)

    # tell execution finished (fills the sm's fifo buffer)
    push(block)

@asm_pio(set_init=(PIO.OUT_LOW, PIO.OUT_HIGH), out_init=(PIO.OUT_LOW, PIO.OUT_HIGH), sideset_init=(PIO.OUT_LOW), out_shiftdir=PIO.SHIFT_RIGHT)
def multiplex_vin2(MUX_PIO_INIT=0b10):
    # block until delay received
    pull(block)
    mov(x, osr)

    # wait for trigger condition
    # enable pin_glitch_en
    wait(1, irq, 1).side(0b1)
    # set irq0 which starts the adc callback (if enabled)
    irq(0)

    # wait delay
    label("delay_loop")
    jmp(x_dec, "delay_loop")

    # do the following two times
    set(x, 1)
    label("for_loop")

    # block until config received
    pull(block)
    out(pins, 2)
    out(y, 14) # t = OSR >> 14
    label("t1_loop")
    jmp(y_dec, "t1_loop")

    out(pins, 2)
    out(y, 14) # t = OSR >> 14
    label("t2_loop")
    jmp(y_dec, "t2_loop")

    # for loop
    jmp(x_dec, "for_loop")

    # reset and disable pin_glitch_en
    set(pins, MUX_PIO_INIT).side(0b0)

    # tell execution finished (fills the sm's fifo buffer)
    push(block)
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

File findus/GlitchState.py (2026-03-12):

#!/usr/bin/env python3
# Copyright (C) 2024 Dr. Matthias Kesenheimer - All Rights Reserved.
# You may use, distribute and modify this code under the terms of the GPL3 license.
#
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
from enum import Enum

# types for classification
class ErrorType(Enum):
    pass

class WarningType(Enum):
    pass

class OKType(Enum):
    pass

class ExpectedType(Enum):
    pass

class SuccessType(Enum):
    pass

# templates to copy
class _Expected(ExpectedType):
    """
    Enum class for expected states.
    """
    default = 0
    rdp_active = 1

class _Error(ErrorType):
    """
    Enum class for error states.
    """
    default = 0
    nack = 1
    no_response = 2
    bootloader_not_available = 3
    bootloader_error = 4
    id_error = 5

class _Warning(WarningType):
    """
    Enum class for warning states.
    """
    default = 0
    flash_reset = 1
    timeout = 2

class _OK(OKType):
    """
    Enum class for ok states (no errors).
    """
    default = 0
    ack = 1
    bootloader_ok = 2
    dump_error = 4

class _Success(SuccessType):
    """
    Enum class for success states (glitching was successful).
    """
    default = 0
    rdp_inactive = 1
    dump_ok = 2
    dump_successful = 3
    dump_finished = 4

class GlitchState():
    """
    Class that combines subclasses for different states. Can be used to classify different responses.

    - Error: Enum class for error states.
    - Warning: Enum class for warning states.
    - OK: Enum class for ok states (no errors).
    - Expected: Enum class for expected states.
    - Success: Enum class for success states (glitching was successful).

    Example usage:

        from findus.GlitchState import GlitchState, OKType

        def return_ok():
            return GlitchState.OK.ack

        def main():
            response = return_ok()
            if issubclass(type(response), OKType):
                print("Response was OK.")
    """
    Error = _Error
    Warning = _Warning
    OK = _OK
    Expected = _Expected
    Success = _Success

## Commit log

2024-05-19 Added schematics for a pico glitcher
    [pico-glitcher-v1 v22.csv]
2024-05-20 Added gerber files
    [pico-glitcher-v1.csv]
2024-05-20 Added example block diagram
    [example.fzz]
2024-05-20 Added example usage
    [example.fzz, example2.fzz]
2024-05-22 Added support for the Chipwhisperer Husky
    [example.fzz, example2.fzz]
2024-05-22 added stm32 pro-glitcher.py script
    [pro-glitcher.py]
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2024-05-25 Power cycle bugfixing
2024-05-25 Working power glitch on stm32f4
    [pro-glitcher.py]
2024-05-25 Added function to reset the corwbar transistors
    [pro-glitcher.py]
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2024-05-28 power-cycle-and-read script fixed
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2024-05-28 faster glitching, however still inconsistent
    [pro-glitcher.py]
2024-06-01 dumping over a large memory range
    [pico-glitcher-v1-bom.csv, pico-glitcher-v1.csv]
2024-06-17 improvements and adaptions over all glitching scripts
    [pico-glitcher.py, pro-glitcher.py]
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2024-07-10 better classification, overall rework
    [pico-glitcher.py, pro-glitcher.py]
2024-07-13 Anpassungen im STM32F4 glitching
    [pico-glitcher.py, pro-glitcher.py]
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2024-08-20 Added pico-glitcher script to STM32F4 directory
    [pico-glitcher-v1 v52_top_bom.csv, pico-glitcher-v1-bom.csv, pico-glitcher-v1.1-BOM.xlsx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]
2024-08-22 Updated the PCB: made it smaller, compact routing, thicker traces, better readable silk screen markings. Rectified eroneous comment.
    [pico-glitcher-v1.1-BOM.xlsx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]
2024-08-23 Timeout is now working correctly for the pico glitcher's block function.
    [pico-glitcher.py, pro-glitcher.py]
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2024-08-24 optimized stm32f4 glitching
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2024-09-12 corrections in mpGlitcher (incorrect pinout) and better voltage handling
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2024-09-13 Updated resistor values
    [pico-glitcher-v1 v52_top_bom.csv]
2024-09-27 Added description of glitching the STM32F412
2024-09-29 added EAGLE compatible files
    [pico-glitcher-v1.1 v91.brd, pico-glitcher-v1.1_v43.sch]
2024-10-04 Added new project nrf52832 glitching, improved trigger capabilities of rising edge trigger (added dead zone)
    [testnrf.cfg]
2024-10-04 better project structure
    [testnrf.cfg]
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2024-10-09 new images
    [pico-glitcher-v1.1-BOM.xlsx]
2024-10-12 added first version of kicad import
    - footprint and symbols moved to a library
    - GND tracks that ran trough GND plane removed
    [pico-glitcher.kicad_pcb, pico-glitcher.kicad_sch]
2024-10-12 cleaned libraries from unused symbols and footprints
    [pico-glitcher.kicad_sch]
2024-10-12 replaced LEDs symbol and footprint with kicad library's ones
    [pico-glitcher.kicad_pcb, pico-glitcher.kicad_sch]
2024-10-12 replaced 0603 resistor's symbol and footprint with kicad library's ones
    [pico-glitcher.kicad_pcb, pico-glitcher.kicad_sch]
2024-10-12 replaced 0603 capacitor's symbol and footprint with kicad library's ones
    also: simplified some tracks.
    [pico-glitcher.kicad_pcb, pico-glitcher.kicad_sch]
2024-10-12 replaced 1x03 pinheader's symbol and footprint with kicad library's ones
    [pico-glitcher.kicad_pcb, pico-glitcher.kicad_sch]
2024-10-12 improved placement and connection of C9
    [pico-glitcher.kicad_pcb]
2024-10-12 replaced 1x01 pinheader's symbol and footprint with kicad library's ones
    [pico-glitcher.kicad_pcb, pico-glitcher.kicad_sch]
2024-10-12 replaced 1x02 pinheader's symbol and footprint with kicad library's ones
    [pico-glitcher.kicad_pcb, pico-glitcher.kicad_sch]
2024-10-12 replaced 2x08 pinheader's symbol and footprint with kicad library's ones
    [pico-glitcher.kicad_pcb, pico-glitcher.kicad_sch]
2024-10-12 replaced power symbols with kicad library's ones
    [pico-glitcher.kicad_pcb, pico-glitcher.kicad_sch]
2024-10-12 corrected various little things (see details)
    most important thing is that ground plan no longer have themal plane on
    SMD pads. Because some pins are narrowed than the plan minimal width,
    this caused some GND pin to need manual wiring to the ground plan.
    [pico-glitcher.kicad_pcb, pico-glitcher.kicad_sch]
2024-10-12 replaced SOT-23 symbols with kicad library's ones
    [pico-glitcher.kicad_pcb, pico-glitcher.kicad_sch]
2024-10-12 replaced 3V3 symbols with kicad library's ones
    [pico-glitcher.kicad_pcb, pico-glitcher.kicad_sch]
2024-10-13 corrected STO-23(5) footprints and replaced polarized capacitor symbol with kicad library's ones
    [pico-glitcher.kicad_pcb, pico-glitcher.kicad_sch]
2024-10-13 replaced TSSOP-24 footprint with kicad library's ones
    [pico-glitcher.kicad_pcb, pico-glitcher.kicad_sch]
2024-10-13 replaced resistor arrays footprint with kicad library's ones
    [pico-glitcher.kicad_pcb, pico-glitcher.kicad_sch]
2024-10-13 replaced SOIC-8 footprint with kicad library's one
    [pico-glitcher.kicad_pcb, pico-glitcher.kicad_sch]
2024-10-13 replaced switches' symbol and footprint with kicad library's ones
    [pico-glitcher.kicad_pcb, pico-glitcher.kicad_sch]
2024-10-16 Added example script to test the pico-glitcher
    [pico-glitcher.py]
2024-10-22 Implemented better block condition for the dead time after reset or power down
    [findus.py, mpGlitcher.py, pico-glitcher.py]
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2024-10-28 More documentation - components of the Pico Glitcher
2024-10-28 How to customize your Pico Glitcher
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2024-11-26 Fixed an issue with the dead time trigger
    [findus.py, mpGlitcher.py]
2024-11-26 Added new project esp32v1.3 glitching
    [pico-glitcher.py]
2024-11-30 added soldering aid 3d print; modified esp32 glitcher to better classify results
    [soldering-aid-v1.1.stl]
2024-12-02 Fixed a serious bug in the UART trigger
    [BootloaderCom.py, findus.py, mpGlitcher.py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]
2024-12-09 New feature: Genetic Algorithm that helps to find optimal parameter sets in a multidimensional parameter space
    [pico-glitcher-v1.1-BOM.xlsx]
2024-12-28 added PicoGlitcher v2.1 Extension board
    [pico-glitcher-v1.1 v91.brd, pico-glitcher-v1.1-BOM.xlsx, pico-glitcher-v1.1.kicad_pcb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]
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2024-12-30 Documentation of pulse-shaping
    [pico-glitcher-v2.1-extension-BOM.xlsx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]
2024-12-30 Documentation of Schmitt Trigger inputs
    [pico-glitcher-v2.1-extension-BOM.xlsx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]
2024-12-31 Erroneous initial voltages for multiplexing corrected
    [mpGlitcher.py, pico-glitcher.py]
2024-12-31 components of Pico Glitcher v2
2025-01-01 New project rp2040 glitching
    [findus.py, main.cpp]
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2025-01-06 correction in documentation
    [pico-glitcher-v2.1-extension-BOM.xlsx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]
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2025-01-14 Bugfixing for Expansion Board schematics
    [pico-glitcher-v2.1-extension.kicad_pcb, pico-glitcher-v2.1-extension.kicad_sch]
2025-01-14 Improvements for Pulse Shaping Expansion board. Pulse Shaping is working with arbitrary pulses.
2025-01-17 Fixed errors in the installation process.
    [AD910X.py, PulseGenerator.py, Spline.py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]
2025-01-17 added esp32 glitching script with pulse shaping
2025-01-18 Pulse Shaping working for esp32 glitching
    [AD910X.py, PulseGenerator.py, Spline.py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]
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2025-01-18 Added note where to purchase the Pico Glitcher.
2025-01-19 Added PCHIP: PCHIP (piecewise cubic hermite interpolating polynomial) interpolation method. Fixed an issue where the time resolution was screwed up when interpolating between fixed points.
    [InteractivePchipEditor.py, PulseGenerator.py, Spline.py]
2025-01-19 Fixed division by zero error. Added example pictures.
    [Spline.py]
2025-01-19 Better esp32 glitching with pulse shaping
2025-01-21 Bug fixing and documentation
    [pico-glitcher-v2.1-extension.kicad_sch]
2025-01-25 fixed a small bug, that prevented small pulses when multiplexing
    [mpGlitcher.py]
2025-01-28 added figures of different pulse shapes to documentation
    [interface.cfg, target.cfg]
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2025-02-05 Solved an issue when re-initializing the PicoGlitcher
    [pico-glitcher.py]
2025-02-07 Added new class STLinkInterface to easily access the STLink adapter; added soldering aids 3d models; added a script to power on target boards via the Pico Glitcher.
    [expansion-board-spacer-v1.stl, soldering-aid-v1.1.stl, soldering-aid-v2.1.stl]
2025-02-08 Solved an issue with Pico Glitcher Pulse Expansion board not storing the calibration
    [pico-glitcher-v2.1-extension.kicad_pcb, pico-glitcher-v2.1-extension.kicad_sch]
2025-02-08 successfully glitched the rp2350
    [interface.cfg, target.cfg]
2025-02-11 minor corrections in documentation
    [findus.py]
2025-02-19 - Preparations for loading a program into RAM. - Added design files for Target and UART Board
    [KMR221GLFS.step, lpc1311-target-v1.kicad_pcb, lpc1311-target-v1.kicad_sch]
2025-02-21 Added new schematic: STM8S target board
    [KMR221GLFS.step, stm8s-target-v1.kicad_pcb, stm8s-target-v1.kicad_sch]
2025-02-21 loosend version compatibility check of findus and Pico Glitcher
    [findus.py]
2025-02-28 Added stm8s glitching project; added STM8 Programmer
    [STM8Programmer.py]
2025-03-01 refactored findus; renamed scripts (consistent naming scheme); Moved submodules to separate files; fixed an error with arm_multiplexing and the genetic algorithm; added more example scripts; finalize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
    [stm8s-target-BOM.xlsx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]
2025-03-02 Removed GlitchState Enum class and used byte states instead
    [DebugInterface.py, GlitchState.py, STM32Bootloader.py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]
2025-03-04 Added functions to clear pending interrupts in PicoGlitcher.py; added Helper functions in findus.py; added function to read until a specific pattern in findus.Serial
2025-03-04 Added error handler that checks for successive fails and executes a user-defined action if too many fails occur in a given time.
    [findus.py, pico-glitcher.py, pro-glitcher.py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]
2025-03-04 small correction (added import)
    [stm32f4-glitching.py]
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2025-03-11 shortened directory names
    [testnrf.cfg]
2025-03-12 fixed errors making the new firmware incompatible with Pico Glitcher v1
    [PicoGlitcher.py]
2025-03-14 Improved class DebugInterface; extended ProGlitcher class to capture voltage traces; added timeout to get_adc_samples
2025-03-14 added a dynamic_range variable to AnalogPlot for consistent voltage scaling; Added checks for ext_offset and repeat parameters
2025-03-14 extended STM8Programmer; STM8s glitching is working; fix for issue #18
    [stm8s-target-v1.kicad_sch]
2025-03-15 Fix for issue #20
    [pico-glitcher.py, stm32f4-glitching.py]
2025-03-15 Fixed several scripts with missing start_time
    [findus.py, pico-glitcher.py, pro-glitcher.py]
2025-03-15 Added try except block to fix issue #20
    [findus.py]
2025-03-16 Changed reset function to reset_target to better understand what this function does
    [HuskyGlitcher.py, PicoGlitcher.py, ProGlitcher.py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]
2025-03-16 Replaced reset with reset_target in examples
    [pro-glitcher.py]
2025-03-17 Fixed a bug in the multiplexing code; added possibility to power-cycle the target via the multiplexing stage; Since these changes break the interface to the PicoGlitcher class, the minor release numb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
    [PicoGlitcher.py, findus.py, pico-glitcher.py]
2025-03-19 renaming; small changes
    [pico-glitcher-v2-amplifier.kicad_pcb, pico-glitcher-v2-amplifier.kicad_sch, pico-glitcher-v2-opamp-amplifier.kicad_pcb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]
2025-03-19 Added Pico Glitcher v2 schematics
2025-03-19 fix for issue #23: if-statement did not check for the correct return value
    [stm32f4-glitching.py]
2025-03-19 fix for issue #23: success state even better specified
    [stm8s-target-v1.step, target-board-soldering-aid.stl]
2025-03-19 fix for issue #23: bug fixing - sorry for that
    [pico-glitcher.py, pro-glitcher.py, stm32f4-glitching.py]
2025-03-19 issue #23: added test script with shorter timeouts
    [STM32Bootloader.py, stm32f4-glitching-shorter-timeouts.py]
2025-03-24 Updated stm8 glitching schematic, added examples
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2025-03-26 Added figures; added setup; added connections of stm32l422 glitching
    [stm32l4-rdp-downgrade.py]
2025-03-28 glitch burst function added. Now you can emit any number of glitches in a short amount of time (improvement #13
    [DebugInterface.py, PicoGlitcher.py, findus.py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]
2025-03-28 Burst glitches applied to stm32l422 glitching
    [pico-glitcher.py, stm32l4-rdp-downgrade.py]
2025-03-30 Removed uncessary pull-up resistors for input pins; added pull-up resistors for output pins; removed hardware pull-up resistors for pulse-shaping expansion board; Added new config file for hardware v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
    [pulse-shaping-extension-v1.kicad_sch]
2025-03-31 Correction of VTARGET enable; updated schematics
    [KMR221GLFS.step, pico-glitcher-v2.1-extension-BOM.xlsx, pulse-shaping-extension-v1.1-BOM.xlsx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]
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2025-04-01 Minor fix when using the external power supply
    [findus.py]
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2025-04-01 Removed adc from example script as it was not working correctly many times.
    [pico-glitcher.py]
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2025-04-01 corrected links
    [pulse-shaping-extension-v1.1-BOM.xlsx]
2025-04-01 updated gerbers, BOM, CPL and schematics
    [expansion-board-spacer-v1.1.stl, expansion-board-spacer-v1.stl, pulse-shaping-extension-v1.1-BOM.xlsx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]
2025-04-02 stm32l422 glitching improved
2025-04-02 Fixed issue with burst glitching when using a delay of 0 ns
    [PicoGlitcher.py, stm32l4-rdp-downgrade.py]
2025-04-05 Reworked power-cycling. Now even the pulse-shaping extension board can be used to power cycle the target.
    [AD910X.py, PicoGlitcher.py, PulseGenerator.py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]
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2025-04-12 Added function to set the voltage output of the multiplexing stage; improved power-cycling capabilities; clarified mux power-cycling; Added gpio pin toggling to power-on tool to enter bootloader mode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
    [stm32f205-breakout-board-B_Cu.gbr, stm32f205-breakout-board-B_Mask.gbr, stm32f205-breakout-board-B_Paste.gbr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]
2025-04-19 Improved STM32 Bootloader communication; Added function to cleanup PIOs if configuration is changed; Better name conventions
2025-04-19 Added functions to re-initialize the Pico Glitcher during a run. Can be used to make config changes on the fly; Finished left over TODOs; Removed uneccessary code; Added a function to switch to a dif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
    [PicoGlitcher.py, findus.py]
2025-04-20 Moved STM32F205 glitching to separate repository
2025-04-22 Added functions to switch between two multiplexing initial values during a run without having the Pico Glitcher re-initialize itself.
    [Globals.py, PicoGlitcher.py, findus.py]
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2025-04-24 Reworked schematics
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2025-04-25 Updated documentation; Added possibility to analyzer script to display a heat map.
2025-04-25 the heatmap can now be displayed additionally as second plot to the usual parameterspace
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2025-05-02 Replaced dc-dc converter in pulse shaping expansion board.
    [pulse-shaping-extension-v1.1.kicad_pcb, pulse-shaping-extension-v1.1.kicad_sch]
2025-05-07 Added Pico Glitcher Fritzing part.
2025-05-08 Added database-tool to operate on existing databases; added the possibility to run two instances of DebugInterface at the same time (by port remapping and fixing the serial number of the debug adapte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
    [DebugInterface.py, database_tool.py, findus.py]
2025-05-16 Updated pulse shaping extension production files
    [pulse-shaping-extension-v1.1-BOM.xlsx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]
2025-05-16 documentation: where to buy the Pico Glitcher from.
2025-05-21 corrected arguments for dump_memory_to_file
    [STM32Bootloader.py]
2025-05-26 Better error handling in STM32Bootloader class
    [STM32Bootloader.py, database_tool.py]
2025-05-28 Added a function to emit two fully configurable glitches with the crowbar stage
    [PicoGlitcher.py, findus.py]
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2025-06-11 Improved error handling; Now removing eroneous experiments more consequently
    [findus.py]
2025-06-18 Added a function to check if the glitch was emitted without blocking
    [PicoGlitcher.py, findus.py, pico-glitcher.py]
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2025-07-16 updated soldering aids
    [soldering-aid-v2.1.stl, soldering-aid-v2.2.stl, soldering-aid-v2.4.stl]
2025-08-29 Updated schematics for airtag glitching
2025-08-29 Updated schematics of Airtag glitching
2025-09-30 clean-up in DebugInterface; added demo flag to stm32l05 glitching
    [DebugInterface.py, stm32l0-rdp-downgrade.py]
2025-10-05 Unwanted oscillation removed when using the multiplexing stage. Moved pio functions to file Statemachines.py
    [PicoGlitcher.py, Statemachines.py, findus.py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]
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2025-10-21 Removed confusing error message
    [DebugInterface.py]
2025-10-28 Updated Expansion Board v1.1 Spacer 3D model
    [expansion-board-spacer-v1.1.stl]
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2025-12-08 Fixed a minor compilation bug
    [PicoGlitcher.py]
2025-12-09 Updated docs; updated spacer for pulse shaping expansion board
    [expansion-board-spacer-v1.1.3mf]
2025-12-10 Fixed an issue with block() and get_adc_samples() where the timeout would trigger prematurely since time.time() is only returning whole seconds in MicroPython. See https://github.com/MKesenheimer/fau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
    [PicoGlitcher.py]
2026-01-11 Version bumpm to 1.12.1
    [pico-glitcher-v2-simulation.kicad_sch, soldering-aid-v3.0.3mf, soldering-aid-v3.0.stl]
2026-01-11 Updated soldering aid
    [soldering-aid-v3.0.3mf, soldering-aid-v3.0.stl]
2026-01-24 pico glitcher v3 introduced
    [pico-glitcher-v2-simulation.kicad_pcb, pico-glitcher-v2-simulation.kicad_sch]
2026-02-05 Better interfacing with gdb; debugging and bug-fixing; correct naming of variables
    [DebugInterface.py, stm32l0-rdp-downgrade.py, stm32l4-rdp-downgrade.py]
2026-02-07 Soldering aid v3
    [soldering-aid-v3.0.3mf, soldering-aid-v3.0.stl]
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2026-03-09 fix(upload): batch delete/upload over single pyboard session to avoid hangs
    Changes:
    - replace repeated ampy subprocess calls with direct findus.pyboard API usage
    - perform multi-file uploads in two phases within one connection:
    - delete matching remote files first
    - upload all requested files next
    - keep reset behavior but issue reset via pyboard (machine.reset())
    - add small connect wait (wait=2) to improve reliability after resets/reconnects
    - print final remote file listing via pyboard
    - fix --file path bug (was incorrectly passing args.files)
    - bonus - fix bad indentation in InteractivePchipEditor
    Before:
    ```
    $ upload --port /dev/ttyACM0 --files AD910X.py FastADC.py Globals.py Pi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
    [InteractivePchipEditor.py, upload.py]
2026-03-09 Print settings of soldering aid improved.
    [soldering-aid-v3.0.3mf]
2026-03-20 Back to old upload script, since the script fails to detect the hardware
    [upload.py]
2026-03-21 Added new upload script (not merged yet); Documentation for multiplexing.
    [expansion-board-spacer-v1.1.3mf]
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2026-03-22 Added a firmware updater script which can be used to easily update the Pico Glitcher to the latest version.
    [update_firmware.py, upload.py, upload_ampy.py]
2026-03-26 Updated gerber files for version 1
    [pico-glitcher-v1.1-BOM.xlsx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]
2026-03-26 Removed kicad files due to errors
    [pico-glitcher-v1.1.kicad_pcb, pico-glitcher-v1.1.kicad_sch]
2026-03-26 Added high-level fritzing schematics
    [Pico-Glitcher-v2.1.fzz, adc-setup.fzz, esp32-glitching.fzz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]
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2026-03-31 Added additional checks and the possibility to provide another external pin number to output the glitch.
    [DebugInterface.py, Globals.py, PicoGlitcher.py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]
2026-04-06 Fix resetting device during FW update for MacOS
    [upload.py]
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2026-04-09 Changed Glitcher methods to static
    [DebugInterface.py, findus.py]
2026-04-17 Fixed an issue where it was not possible to perform double glitching consistently
    [STM32Bootloader.py, Statemachines.py, stm32l0-readmemory.py]
2026-04-22 Improved analyzer; Fixed a critical issue that prevented correct triggering in double-glitching attempts
    [DebugInterface.py, findus.py, stm32l0-readmemory.py]
2026-04-22 Improved stm32l0 project to support double glitching
    [stm32l0-readmemory.py]
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

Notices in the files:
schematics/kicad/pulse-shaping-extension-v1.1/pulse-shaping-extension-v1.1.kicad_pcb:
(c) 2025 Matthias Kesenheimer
